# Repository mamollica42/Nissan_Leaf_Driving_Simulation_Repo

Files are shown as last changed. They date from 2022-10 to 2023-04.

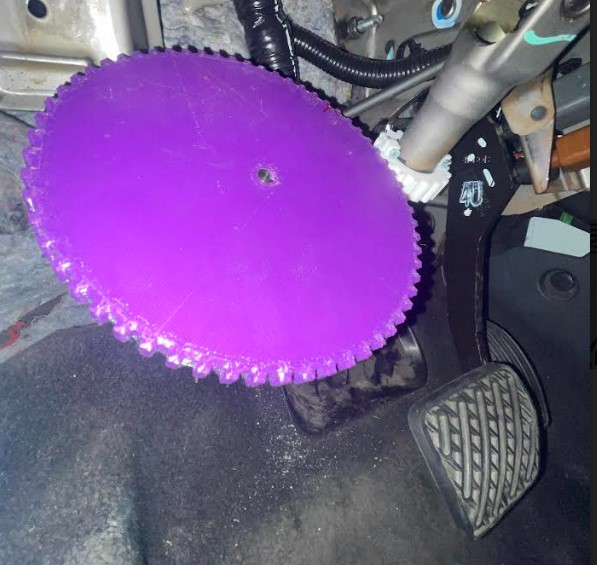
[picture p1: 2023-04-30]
Documentation/Images/Steering.jpg

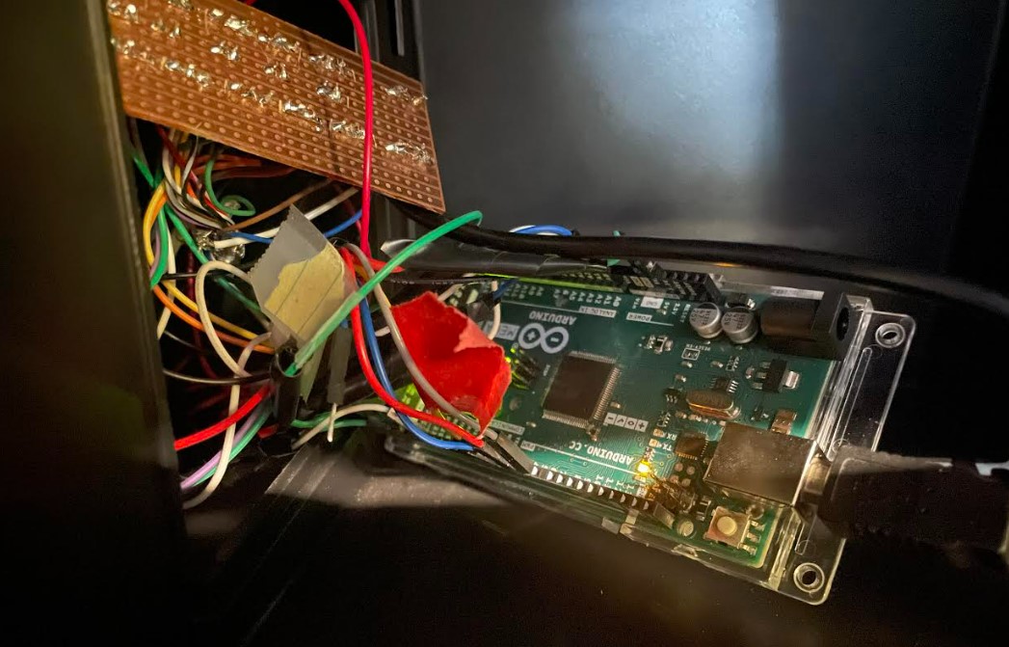
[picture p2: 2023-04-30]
Documentation/Images/MasterMCU.jpg

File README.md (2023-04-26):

# Nissan Leaf Driving Simulation

# Executive Summary

The Nissan Leaf Driving Simulation is a long-term goal for the ECE and ME Departments at TNTECH. This project consists of data acquistion and initial hardware setup for the future simulation to be built off of. The hopes of the final product are to accurately replicate the look and feel of driving a Nissan Leaf without the actual motion of the vehicle.

# Capabilities

This repository currently contains finalized documents for the project. This includes, but is not limited to the following:
- Electrical Schematics
- Final Project Poster
- CAD Models
- Experimental Analysis
-  Subsystem Signoffs
- Finalized Software
- Project Demonstration
- Individual & Final Presentations

# Salient Outcomes
- Measure steering angle from -600 to +600 degrees
  - _Note: After experimentation, the team discovered that the left and right bounds of the steering wheel are NOT equal. That is, the wheel rotates slightly more to the right than it does to the left by approximately 20 degrees._
- Capture break and accelerator percentage of compression
- Detect shifter position and auto-light selection
- Single system power switch with overcurrent protection
- Collect CAN Bus messages >> 10 Hz
- Replaced speedometer with aesthetic 3D printed LCD module
- Use of OEM steering wheel, brake pedal, accelerator pedal, shifter, and auto-light knobs
- All hardware is concealed from the user
- Provide all data to PC in less than 100 milliseconds

# Project Demonstration & Images
Watch our project demonstration [HERE](https://youtu.be/_0IFVq8wqwk)

Power Supply & Control Switch|Steering Gear System|Shifter Subsystem|
:---------------------------:|:------------------:|:------------------:
||

Final Vehicle Interior|
:--------------------:|
|

# About Us

## Team

Michael Mollica - CmpE

Gerardo Mateo - CmpE

Chase Colotta - EE

Brett Harden - EE

Ethan Powers - EE

## Faculty Supervisor

Dr. Nan Chen - ECE Department

Mr. Jesse Roberts -  ECE Department

### Stakeholders

Dr. B. Andy Pardue - ME Department

# Repo Organization
## Reports
- Project Proposal
- Conceptual Design
- Individual Technical Presentations
- Final Presentation
- Final Bill of Materials (BOM)
- Project Poster
- Lessons Learned

## Documentation
- 3D Models
- Electrical Diagrams
- Images
- Signoffs
- Experimentation

## Software
- Documentation -> Software
- Folder includes all Arduino code used to program the MCUs

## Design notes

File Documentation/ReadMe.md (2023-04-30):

## Signoffs

Signoffs are the detailed designs for different components. Signoffs include the analysis for each design specification, images of the schematics for the implementation, and the bill of materials for the components. These documents are the details for each subsystem in the total project. 

## 3D Models

The models posted here are derived from the signoffs. The signoffs include images of the models, but this folder houses the files that contain the designs to be opened in drawing software. Most files were drawn in AutoCAD and uploaded as a .stl file. The 'Final **** Assembly' file in each subfolder is all other pieces in the folder combined into the implemented design. 

## Electrical

### Wiring Schematics

Schematics posted here were drawn in KiCAD from the signoffs, and they represent the wiring for components in the subsystems. Images of the schematics were posted in the signoffs, but this is the downloadable files to view in drawing software. 

## Detailed photos of the project

Pictures taken of the implemented hardware and the software output. The picture labels describe the contents of the respective pictures.

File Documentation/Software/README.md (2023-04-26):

Arduino Software
---------
This folder contains the code for the Master MCU, Shifter, Speedometer, and CAN Bus subsystems. All files are .ino extension.

##### _*Note: CAN Capture Code is example code found at the following link created by the manufacturer of the CAN Bus Shield for Arduino, Seeed Studio. It is not original code and Team 8 takes no credit for its creation._
Link to Code: https://github.com/Seeed-Studio/Seeed_Arduino_CAN
### Capabilities
Each file is the main code that runs its respective subsystem. For example, the Master MCU V2 code runs on the Arduino Mega in the Master MCU subsystem.
### How to Install/Run?
Each .ino file must be downloaded in a folder **with the same name as file**. For example, a file named "myFile.ino" must be placed in a folder named "myFile" so that Arduino IDE can recognize it properly. Once downloaded and in a folder with the same name, simply open the files in Arudino IDE to run and edit.

##### _*Note: This code requires no dependencies to run._

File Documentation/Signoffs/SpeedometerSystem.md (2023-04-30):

SPEEDOMETER SUBSYSTEM
--------------------
### Functions of the Subsystem
The speedometer subsystem must receive output from the driving simulation and display the speed the user is going. A microcontroller will be used to export the speed data from the simulator and display it on a screen inside the car.
### Specifications & Constraints
- C1. Shall be powered by the PC running the simulator via USB 2.0
-	C2. Microcontroller must be able to read speed data from the simulator while it is running using serial communication
-	C3. Data must exit the PC running the simulator and be stored on a microcontroller using serial communication
-	C4. Shall display the speed data in an appropriate manner on a screen inside the car

### Schematic
##### 1. Screen to Microcontroller Connection



_Figure 1. A photograph of the LCD snapping onto the Arduino Uno [1]

##### 2. Wiring Schematic



_Figure 2. Schematic for the 3.5 Inch TFT Color LCD Screen Plugging into the Arduino Uno

### Analysis

### C1. Shall be powered by the PC running the simulator via USB 2.0
An Arduino Uno can be powered by a USB 2.0 coming from the PC running the simulator.

### C2. Microcontroller must be able to read speed data from the simulator while it is running using serial communication
Arduino can directly communicate with the simulator that runs on MATLAB via serial communication with a USB 2.0. For the simulator to send data to the Arduino, serial.write() functions will be inserted into the simulator code to continuously send speed data to the Arduino. For the Arduino to receive and display the speed data, serial.read() functions will be used.

### C3. Data must exit the PC running the simulator and be stored on a microcontroller using serial communication
Once the serial.read() function is used, the speed data will be collected and used in the C code that displays the speed. This means that the data has exited the PC and is being processed on another device using a programming language other than MATLAB.

### C4. Shall display the speed data in an appropriate manner on a screen inside the car
#### LCD Display Selection
The The 3.5 Inch TFT Color LCD Screen has 28 pins and can directly snap onto an Arduino UNO REV3. The 3.5" LCD screen can be programmed to display whatever the user wants and is plenty big enough to display the speed data from the simulation. With a module display area that contains 320x480 pixels, the team can add extra embellishments onto the screen to make the speed data that is displayed feel more appropriate to the car.

#### Mounting
The recommended max distance of a USB 2.0 cable is 16 feet. The PC running the simulator will be within 16 feet of the speedometer and the master MCU, so mounting the LED display in the desired position shall have no effect on transmission speeds. To keep the the immersive feel of the inside of the car, the LCD will be mounted exactly where the current speedometer display is located. The stock display will be removed and be replaced with a new mount that will mimic the current one. The new one will of be able to communicate with MATLAB and pull the speed data from the simulator.



_Figure 3. The mounting for the Uno in the Car 



_Figure 4. The face plate for the mount

The back of the mount will be screwed in to replace the old speedometer display. The face plate will allow for only the LCD screen to be seen by the user of the simulator and will be screwed directly where the old speedometer display was located. All of this should allow for immersive experience for the simulator by not creating an eye sore that sticks out from the rest of the car. The green pieces from the above digrams will be 3D printed in black to blend in with the rest of the components in the car. The pink piece is the Arduino and the yellow piece is the display.

### BOM

| Part | Price |
|:---:|:---:|
| Arduino | $27.60  |
| USB 2.0 | $ 7.60 |
| TFT Color LCD | $ 19.00|
| TOTAL | $54.20 |

### REFERENCES
[1] https://www.amazon.com/Treedix-Display-Screen-Arduino-Mega2560/dp/B0872S57HG

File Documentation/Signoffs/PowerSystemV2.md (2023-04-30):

Power System
-------
### Function of the Subsystem
The power system is to provide power to all of the components and subsystems within the design. This includes the original car components in its entirety as well as the external subsystems that will be added. This will include replacing the battery with a power converter for continuous supply and implementing safety components to protect the sensors and controllers in the external subsystems. . 

### Specs & Constraints
- Must utilize the power supply provided for 12 V supply
- Must regulate the supplied source voltage to be within 5% of 12 V
- Must implement a method to disconnect the entire system from the source
- Shall implement safety components to prevent overcurrent on new devices
- Must not exceed wire capabilities
- Must supply required input voltage to the external sensors, external controllers, and 12 V OEM components

### Schematics
###### Wiring Diagram



_Figure 1: Power Circuit & Connected Components_---

### Analysis
*This analysis is for the original design with 3 Ardiono Unos. The design was modified to only one Uno as shown in the schematic and implemented.*

###### 1. Power Supply
The power supply to be used supplies 12 Volts and 600 Watts of direct current. The voltage output of the power supply was tested with an oscilloscope and the peak-to-peak voltage was approximately 800 mV with a 12 V DC offset. This output means that the voltage supplied is between 11.6 and 12.4 V. The variance of +/- 0.4 V means that the supplied voltage is approximately 3.33% of the expected value. This verifies that the power supply’s original output meets the 5% constraint.  

###### 2. Switch Selection
To prevent the master switch from being a restriction, the switch needs to have a rating of 12 V and 50 A DC. Digi-Key offers a toggle switch from Switch Components that meets the criteria with the TD1-1A-DC-3-R [1]. The switch is rated for 12 V, 50 A DC and has minimum insulation resistance of 100 Mohm. The insulation of the switch will not allow a current from a 12 V supply to reach the user that could be felt by the operator while properly disconnecting the entire system from the source.

###### 3. Diode Selection 
Due to the uncertainty of not knowing the components in the OEM components, an assumption is made that energy storage elements are implemented somewhere. The switch system needs to be designed to allow for the load to always have a path for current to flow and dissipate the stored energy. A flyback diode is introduced to be in parallel with the load and allow energy to circulate through the load until it dissipates completely after the switch is opened.
The diode for the circuit shown in Figure 1 will be a 19TQ015CJ from SMC Diode Solutions [2]. It is designed to have a continuous forward voltage of 360 mV at a maximum continuous current of 19 A. The datasheet provides that the diode can handle a peak current of 120 A for an instance before dissipating, which is three times greater than the maximum current that can be supplied.

###### 4. Wiring
The wiring to all of the external components will be 18-gauge wire. This is based around the pre-terminated wire that is sold to be used for the Arduino’s DC jack [3]. The maximum current that is allowed for 18-gauge wire is 2.3 Amps [4]. The current drawn by each external microcontroller or sensor is expected to have a maximum of 70 mA per their respective datasheet. This 70 mA current is within the 2.3 A limit of the 18-gauge wire. The internal resistance of 18-gauge wire is approximately 6.385 Ohms per 1000 ft. For the 6 ft of wire, the resistance is 0.03831 Ohms. This means that the maximum voltage across the wire is 0.08811 V or 88.11 mV.  

###### 5. Voltages and Fuses
Per the datasheet for the Arduino Uno, the microcontroller draws no more than 70 mA and can receive voltages ranging from 6 to 20 volts on the DC jack [5]. The microcontrollers will then be connected directly to the 12 V system due to 12 +/- 0.4 V falling within the range. The rotary encoder used for the steering system states that it can draw up to 70 mA per the data sheet at a range of 10.6 to 24 V. Likewise, the voltage will be within the requirements with the 12 V supply.
A fuse panel will be implemented to protect the wiring from short circuits. The fuses for each system will be 100 mA glass fuses from Digi-Key [6]. These fuses will be used in series as the first point of failure instead of the wire. It is common practice for mechanics and electricians to install wiring for devices that would be around 60-85% of the maximum current rating for the expected load. The 100 mA fuse was chosen to allow for approximately 70% of the maximum tolerance to allow for the event of a device drawing slightly more current than expected. 
To protect the wiring between the power supply and the switch, the internal fuse for the power supply will be the protection. This is designed within the supply and eliminates any issues seen by the terminals.


_Figure 2: Spice Circuit with 70 mA loads_

A Spice simulation was used to determine the expected values of the currents and voltages on each line. The circuit in Figure 2 shows the expected connections for the Unos and encoder with each of the wire resistances placed in series. Two simulations were run with the input voltage V1 being 11.6 V and 12.4 V to cover the maximum variance of the supplied voltages to the wires. The data yields the conclusion that the voltages at the end of the wires will be within the acceptable values for the input of the Unos and Encoder. 

Input: 11.6 V 

| Element | Voltage (V) | Current (mA) |
|---:|:---:|:---|
| Uno1 | 11.5973 | 70 |
| Uno2 | 11.5973 | 70 |
| Uno3 | 11.5973 | 70 |
| Encoder | 11.5973 | 70 |

Input: 12.4 V 

| Element | Voltage (V) | Current (mA) |
|---:|:---:|:---|
| Uno1 | 12.3973 | 70 |
| Uno2 | 12.3973 | 70 |
| Uno3 | 12.3973 | 70 |
| Encoder | 12.3973 | 70 |

###### 6. OEM Connection
The OEM battery terminals will be connected to bolts that will act as posts to the switch. The OEM safety devices will be utilized since they were designed for the OEM components. 

###### 7. Housing
The components to the power system will be placed inside of a plastic electrical box. The wires will be ran into it and will provide insulation and support to all of the safety compontents. A plastic box was chosen over metal due to the insulation characteristics of plastic.

### BOM

|Item | Part Number |Price |
|---:|:---:|:---|
| Master Switch | TD1-1A-DC-3-R |$5.08 |
| Flyback Diode | 19TQ015CJ |$1.30 |
| Arduino Wiring | 10-02493 |$30.04  |
| 100 mA Fuses | 5ST 100-R |$3.78 |
| Fuse Holder | 4628 |$2.92 |
| TOTAL | |$43.12  |

### References
[1] https://www.digikey.com/en/products/detail/switch-components/TD1-1A-DC-3-R/11492919

[2] https://www.digikey.com/en/products/detail/smc-diode-solutions/19TQ015CJ/6022095

[3] https://www.digikey.com/en/products/detail/tensility-international-corp/10-02493/9134524

[4] https://docs.arduino.cc/resources/datasheets/A000066-datasheet.pdf

[5] https://docs.arduino.cc/static/6c94080aaecc364dd9013ce042a27790/A000066-datasheet.pdf

[6] https://www.digikey.com/en/products/detail/bel-fuse-inc/5ST-100-R/1009010

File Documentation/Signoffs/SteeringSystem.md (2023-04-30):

STEERING WHEEL SUBSYSTEM
------------------------
### Function of the Subsystem
The Steering Wheel subsytem shall recieve the input of the Nissan Leaf steering wheel into a sensor
embedded into the steering column of the vehicle. The sensor will measure the steering angle and send
the data into a local microcontroller which will interpret the data and relay it to the simulation.

### Specifications & Constraints
- Must measure angle of rotation of the steering wheel
- Must use the Nissan Leaf OEM steering wheel as the input
- Angle shall be no less than 1200 degrees from the left boundary to the right boundary (3 and 1/3 rotations)
- Error of the angle must be within 1 degree of the true steering angle
- Must not lose steering position when power is cycled
- System must be small enough to fit in the area of the vehicle without interfering with the driver or other subsytems

The simulation requires an input for the steering angle of the vehicle. In the Nissan Leaf, the steering
is limited to 3 and 1/3 total rotations from the clockwise boundary to the counter-clockwise boundary.
Therefore, the angle measured must be at least 1200 degrees total. Due to the broader impact 
accuracy constraint, the error of the angle sensed must be within 1 degree of the true angle to prevent false
representation of the steering. Based on a study conducted on front wheel drive vehicles, the range of error in steering angles
is between -0.56 and 1.64 degrees for a total error range of 2.2 degrees [1]. Therefore, the 1 degree target error is within the
normal range of a standard front wheel drive vehicle such as the Nissan Leaf.

### Schematic
##### 1. Model



LEGEND:
- Black  --> OEM Parts (Steering Column and Mounting Plate)
- Blue   --> Small Gear
- Green  --> Large Gear
- Red    --> Adapter Plate
- Yellow --> JT-035D (Mounting Bracket)
- Orange --> Absolute Encoder

_Figure 1: 3D-Model of Gear and Encoder Connection_



_Figure 2: 2D Model of the Adapter Plate to be 3D printed_



_Figure 3: 2D Model of the Mounting Plate in the Nissan Leaf_



_Figure 4: Highlighted the Mounting Plate from Figure 3 in the Nissan Leaf_

##### 2. Wiring Schematic



_Figure 5: Encoder Connection to MCU_

### Analysis
##### 1. Angular Rotation

To select the appropriate rotary encoder, the CPR value must be enough to measure each steering position accurately. The equation below is used to capture the angle in degrees based on the CPR and the counts:
      
      A = (C/CPR) * 360       (1)

where C is the number of counts, CPR is the Counts per Revolution, and A is the angle in degrees.

Similarly, the accuracy of the angle is highly important to the selection of an encoder. To find the output sensitivy of the encoder, the following equation is used:
     
     D = 360/(Resolution)       (2)

where D is the degrees of accuracy and Resolution is the how many data bits. 

##### 2. Encoder Selection

This steering wheel design will use a TRD-NA1024NW absolute rotary encoder with a resolution of 1024. The unique property of the absolute encoder is that the output will remain constant even if the encoder is not powered which allows the system to not lose the steering position when power is cycled. The Encoder a voltage rating of 12 to 24 VDC, and a maximum current consumption of 70 mA. The TRD-NA1024NW has 10 data bits, a VDD pin, and a GND pin. This requires a microcontroller with at least 10 digital GPIO pins and that can receive current of up to 32 mA from the rotary encoder.

The encoder has 1024 unique 10-bit outputs than will be read into the MCU. The outputs of each pin are 10 V signals which are too high for the MCU to read becuase the Arduino digital input pins operate at 5 V. To overcome this issue, a simple two resistor voltage divider will be connected to each output of the encoder. To solve for the resitance needed, the below equation is used:

      Vin = Vout*(R2/R1 + R2)   (3)
      
In this case, Vin is 10 V and Vout must be 5 V. Therefore, selecting R1 such that it equals R2 will give a Vout of 5 V because 10 V / 2 = 5 V. For the purposes of this project, R1 and R2 will be 2 W, 100k Ohm resistors to ensure the current of 32 mA will not damage the resistors in the voltage divider circuit. This can be proved by the equation below:

      P = IV                    (4)
      
where P is power dissipated in the resistor, I is current through the resistor, and V is the voltage across the resistor. The resistors are each rated for 2 W of power. If each resistor is placed in the circuit and are equivalent, the current though each resistor will be equal. Additionally, the voltage across each resistor will be 5 V based on Ohm's Law where V = IR. Therefore, the power consumed in each resistor is (5 V)(32 mA / 2) = 0.16 W which is much less than the maximum rating of 2 W.

The output of the encoder changes on rotation of the knob. The knob of the encoder will be connected to a gear system that is mounted to the steering column of the vehicle so that the steering wheel rotation will rotate the knob. Each 10-bit output will increment or decrement a count variable in the MCU code depending on the direction of rotation. That count will be used to calculate the angle of the wheel using equation 1 above.

Our contraint of 1% accuracy means that the encoder must have a resolution high enough to measure values within 1 degree of the true angle. With a 1024 resolution, we are able to cut down the accuracy to 0.9375 degrees, which is highly accurate. This resolution is the lowest possible that allows the team to measure less than a degree of change in the steering angle.

##### 3. Microcontroller Selection

The Arduino UNO REV3 is clocked at 16 MHz, has 14 digital I/O pins, and 6 analog I/O pins. The board can be powered via battery, USB, or the VDD pin and can operate within a voltage range of 7-12 V. Each GPIO pin can receive up to 40 mA and operates at 5 V. The maximum current consumption Given that the encoder requires 10 digital pins, the Arduino UNO can support that requirement and still have leftover pins for communication. Addtionally, the power supplied to the encoder will be supplied by the power system to avoid any possible damage to the microcontroller.

##### 4. Connectivity

The rotary encoder must be connected to the steering column such that the rotation of the wheel can be properly mapped to the encoder. This will be done using a gear system with an 10:3 gear ratio. This value is based on the 1200 degree rotation of the Nissan Steering Wheel having to be mapped to the 360 degree rotation of the encoder. The below equation helps analytically verify this calculation:

      Driven/Driving = 1200/360 = 10/3 ==> 10:3    (5)
      
The steering wheel is already limited to the 1200 degree range by Nissan. This means that the steering wheel physically is unable to exceed 960 degrees of rotation from the left boundary to the right boundary. Therefore, mapping its rotation using the 10:3 gear ratio will also make it physically impossible for the rotation of the encoder to exceed 360 degrees as desired. The TRD-NA1024NW is a 1024 resolution encoder, meaning it displays 1024 unique outputs per revolution. For each turn of the encoder, 0.356 degrees will be measured allowing the angle to be extremely precise. Additionally, by attaching the gear system to the steering column, the OEM steering wheel can be used as the input to the encoder.  

##### 5. Calculations
To find the diameters of the gears that will be used to create the 8:3 gear ratio, we will follow the Law of Gearing:
      
      D2/D1 = T2/T1                             (6)
      
where D1 and D2 are the diameters of the gears, and T1 and T2 are the number of teeth for each gear. To acheive an 8:3 ratio, the driving gear will have 18 teeth and the driven gear will have 48 teeth. This translates to 6 cm and 16 cm respectively for D1 and D2 to maintain the 8:3 ratio while meeting the spacing constraint of the vehicle.

To verify that this ratio would provide accurate mapping of 960 to 360 degrees, we created a MATLAB script to iterate through all possible positions of the encoder as seen in the figure below.



_Figure 6: MATLAB Verfication for all possible Angles_

##### 6. Gear and Mounting Design
The size constraints for the next closest item in the car are as follows:
- Closest point to the left of the mounting plate: 12 cm
- Closest point behind the mounting plate: 6 cm
- Closest point below the mointing plate (barrier determined to be for operator's feet): 10 cm
- Closest point to the right of the steering column: 7 cm
- Closest point to above the steering column: 9 cm

The steering column has an inch diameter, so the small gear must have a center bore of exactly 1 inch (2.54 cm). To maintain a small size, the small gear was chosen to have a 6 cm pitch diameter to fit around the steering column and comply with size restrictions around the column. When chosing 6 cm for the small gear, 16 cm must be the pitch diameter of the large gear based on the Law of Gearing. The center bore of the large gear must fit the knob of the encoder such that the rotation of the gear is the same rotation for the encoder. In this case, the center bore of the large gear must be 8 mm in diameter and a 0.5 mm notch to secure the knob of the encoder. 

The mounting bracket of the encoder will be connect to the frame of the Leaf via an adapter plate. The gear connected to the encoder needs to be on the same plane as the gear from the steering column to allow the gears to mesh properly. This was done by creating the adapter plate to allow the mounting bracket to be rotated 45 degrees from the frame and be parallel to the steering column. Then the depth of the adapter was determined to be 12.7063 mm based off of the space needed to have the gears far enough to mesh, but also have the gears as close as possible to reduce the backlash between the teeth. These gears will be 3D printed in the Maker's Space in the Angelo & Jennette Volpe Library.

The furthest point that the design extends to the right is the small gear on the steering column, and its farthest point protrudes 2.03 cm from edge of the steering column. The furthest point to the left is the large gear and it should extend 10.38 cm past the edge of the mounting plate. The model should not extend below the mounting plate by any more than 1 cm. The back of the mounting plate is the furthest back that the design goes and should not conflict with the wall. The furthest up the design goes is the 10.45 cm due to the large gear and the closest point is above the steering column. Since the large gear is offset, the closet point to it is 17 cm above the mounting plate. With the specifications of the design, none of the boundaries on the car are exceeded and the size constraints are met.

### BOM

| Part | Price |
|:---:|:---:|
| TRD-NA1024NWD| $352.00  |
| JT-035D | $13.00 | (Mounting Bracket)
| Arduino | $27.60 |
| Resistors | $7.60 |
| TOTAL | $400.20  |

_*Note: The filament and the printer will be provided by the university because this is a school project_

### REFERENCES
[1] https://www.researchgate.net/publication/327832862_Analytical_Evaluation_of_Steering_Errors_in_a_Front_Wheel_Steered_Vehicle

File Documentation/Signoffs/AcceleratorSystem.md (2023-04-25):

Accelerator Pedal Position System
--------------------------------------
### Function of the Subsystem
This subsystem will obtain the gas pedals position and send this signal to a local microcontroller for processing. The local microcontroller will then send its position to the master microcontroller which tells the simulation the pedals position. 

### Specifications & Constraints
- C1. Must use OEM gas pedal to meet customer expectations.
- C2. Must send voltage at the range 0-5V that changes as the position changes to be read by the local microcontroller.
- C3. Must have wires able to handle at least 5V and 20mA due to the expected voltage range 0-5V and expected current of 20mA.
- C4. Shall have an accurate measure of the pedal postion of at least 1% accuracy to ensure the simulation is a accurate representation of real life. 
- C5. Must not have any exposed or loose wire according to IEEE Std 576-13.  

### Wiring Schematic

Gas and Brake kicad schematic

###### _Figure 1: OEM Wiring With Splice On Output Signals of Gas and Brake pedals_

### Analysis
#### C1. Must use OEM gas pedal to meet customer expectations.
- Customer does not want external pedal installed to car.
#### C2. Must send voltage at the range 0-5V that changes as the position changes to be read by the local microcontroller.
- The sensor that measures the position will be an analog signal with voltage range 0-5V that can be read by most microcontrollers. In this case a external sensor will not be added since there is a accelerator pedal position sensor(APPS) that sends an analog signal to the engine controller module(ECM) that will be wire spliced to the local microcontroller.
#### C3. Must have wires able to handle at least 5V and 20mA due to the expected voltage range 0-5V and expected current of 20mA.
- 22 AWG wire will be selected for the splicing since it can handle 300V and 7A.
#### C4. Shall have an accurate measure of the pedal postion of at least 1% accuracy to ensure the simulation is a accurate representation of real life.
- Arduino boards convert the 0-5V analog signal to a digital signal with 1024 bits so 5/1024 means 4.88mV per step.  The smallest range of voltage we tested was 1.883V which has 1.883V/0.00488V to get 376.6 steps for this range of voltage. The accuracy then is 1/376.6 = 0.27%.
#### C5. Must not have any exposed or loose wire according to IEEE Std 576-13. 
- This section of the IEEE standards tell you the safe practices of wire splicing which I will follow when install the Dorman wire splicing clips.



###### _Figure 2: The wiring diagram of the cruise control with the pedal position sensors at the bottom left[1]_



###### _Figure 3: The expected values of each wire for the accelerator[2]_

### Testing 
The accelerator pedal has been tested by the Mechanical Engineering (ME) capstone team that has also been tasked to get data from the gas pedal to use in the simulation. They took out the pedal and took it to their lab and power the sensors with a power supply and measured the sensors output with a digital multimeter (DMM). Their results are shown in Figure 4. As shown in the picture there are two 5V supplied the pedal from the ECU to pins 3 and 2 and shown in the picture with red and wired in the car with white. The two grounds are shown shown in the picture as pins 5 and 6 with black and wired in the car with black. The two outputs from the senors are on pins 1 and 4 and are shown in the picture as green but are wired in the car with red. The correct pins and wire colors are also shown in Figure 2. The voltage range they got on the sensor at pin 1 is 0.367V - 2.250V from zero throttle to full throttle respectively. The voltage range from the sensor on pin 4 is 0.745V - 4.455V. With these ranges we will be able to set up a linear angle increase as the voltages increase in the coding of the local microcontroller. 

ME gas pedal testing

###### _Figure 4: The data the ME team gathered from testing the accelerator pedal while hooked up to a DMM.

### BOM

| Part | Price |
|:---:|:---:|
| Dorman 22-18 splicers 7 pact | $4.49 |
| 22 gauge wire | $14.99 |

note: tax not included

Sources:
[1] https://portal-diagnostov.com/en/2020/04/20/cruise-control-nissan-leaf-sv-2013-system-wiring-diagrams/

[2] https://erwinsalarda.com/nissan-accelerator-pedal-position-app-sensor/

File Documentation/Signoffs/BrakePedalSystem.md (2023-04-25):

Brake Pedal Position System
--------------------------------------
### Function of the Subsystem
This system will obtain the brake pedal posistion and send this signal to a local microcontroller to process its position. The local microcintroller will then send the pedal location to the master microcontroller to implement it to the simulation.  

### Specifications & Constraints
- C1. Must use OEM brake pedal to meet customer expectations.
- C2. Must send voltage in the range of 0-5V that changes with pedal position to be read by a local microcontroller.
- C3. Must have wires able to handle 5V and 20mA to meet the expected voltage range of 0-5V and the expected current of 20mA. 
- C4. Shall have an accurate measure of the brake pedal position of at least 1% accuracy to ensure the simulation is an accurate representation of real life.
- C5. Must comply to IEEE 576-13 section on loose wires and splicing of wires.
- C6. Must have microcontroller with at least four analog or four digital in ports to read both the gas pedal sensors and the brake pedal sensors.
- C7. Must have microcontroller able to be powered by a 12V source to comply with the power systems design to stay at 12V.
- C8. Must have microcontroller with UART capability to communicate with the master MCU. 
- C9. Must have microcontroller able to convert analog to digital in at least 100ms to be consider real time. (Shown in master MCU signoff)

### Wiring Schematic

Gas and Brake kicad schematic

_Figure 1: The wiring schematic with the desired local MCU and OEM sensors for both pedals being sent to it. 

### Analysis
#### C1. Must use OEM brake pedal to meet customer expectations.
- Customer does not want external brake pedal installed so must use stock pedal.
#### C2. Must send voltage in the range of 0-5V that changes with pedal position to be read by a local microcontroller.
- I am going to use the cars anti-brake system(ABS) deceleration sensor[1] which sends an analog voltage of 0-5V to the ECM. I will wire splice sensor output wires and feed them to local microcontroller analog input pins. 
#### C3. Must have wires able to handle 5V and 20mA to meet the expected voltage range of 0-5V and the expected current of 20mA.
- I am choosing 22 AWG wire since it is rated for 300V and 7A.
#### C4. Shall have an accurate measure of the brake pedal position of at least 1% accuracy to ensure the simulation is an accurate representation of real life.
- Arduino boards convert the analog siganl to digital signal with 4.88mV per step. The smallest signal voltage range was 3.35-3.98V. (3.98-3.35)V/4.88mV = 129 steps and has 1/129 = 0.78% accuracy.
#### C5. Must comply to IEEE 576-13 section on loose wires and splicing of wires.
- This section of standard deals with wire splicing practices and regulation which will be followed when installing the Dorman wire splicing clip that meets regulation. 
#### C6. Must have microcontroller with at least four analog or four digital in ports to read both the gas pedal sensors and the brake pedal sensors.
- I will be using an Arduino Uno Rev3 that has 6 analog pins.
#### C7. Must have microcontroller able to be powered by a 12V source to comply with the power systems design to stay at 12V.
- I chose the Uno over the nano since the uno can be powered by 12V power supply will the nano cannot.
#### C8. Must have microcontroller with UART capability to communicate with the master MCU. 
- The Uno has UART which is haow it will communicate with the Arduino Mega.
#### C9. Must have microcontroller able to convert analog to digital in at least 100ms to be consider real time. (Shown in master MCU signoff)
- The Uno has processing speed of 16MHz which is 62.5ns for one cycle, it takes 13 cycles to convert A to D which takes 0.8125 microseconds which is greater then 100ms.

### Testing 
Brett and I took out the entire brake pedal with the ABS sensor attached and took it to the capstone lab for testing. I turned on the car with the part removed and measured the 4 pin plug and found Vin and GND. Vin is the white wire on pin 3 and GND is the black wire on pin 4. With these pins determined I hooked up those pins to a powersupply and measured the outputs of pin 1 and 2 with a digital multimeter(DMM). I learned that pin 2 has a voltage of 3.35V when not pressed and a voltage of 3.98V while fully pressed. The voltage does change linearly as the brake is pushed. I also learned that pin 1 has a voltage of 2.77V not pressed and 1.58V fully pressed. This voltage also changes linearly as the brake is pushed. With this data I will be able to program the arduino board to get a position based on the change of voltages while the pedal is being pressed. 

### BOM

| Part | Price |
|:---:|:---:|
| Arduino Uno Rev 3 | $24.00 |

Sources:
[1] https://www.scribd.com/presentation/344855740/Sensors-Used-in-ABS#

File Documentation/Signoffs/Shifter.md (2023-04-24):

Gear Shifter Subsystem
--------------------------------------
### Function of the Subsystem
The gear shifter subsystem will capture the OEM signal from the gear shifter sensor by splicing into the wiring and storing the signal on a local microcontroller. 
### Specifications & Constraints
-	C1. Must use OEM gear shifter sensor
-	C2. OEM shifter sensor must send a detectable output signal for the shifter positions park, neutral, drive, and reverse.
-	C3. Shall receive the OEM gear shifter signal on a local microcontroller
-	C4. Must have local microcontroller that can be powered by a 12 V source
-	C5. Must have local microcontroller that can communicate with the master MCU via UART communication
-	C6. Must have local microcontroller that samples above or at twice the the measured normal frequency of 4.82 Hz from OEM gear shifter sensor to satisfy the Nyquist rate
-	C7. Must have local microcontroller capable of reading the measured 5 V digital output signal from the OEM shifter sensor
-	C8. Must have local microcontroller with at least 4 digital I/O pins to read the output signals coming from the OEM shifter signal
-	C9. Must have wires capable of handling 5 V to read the output signal from the OEM shifter sensor
-	C10. Must comply with IEEE 576-13 section on splicing wires and having loose wires.

### Wiring Schematic



###### _Figure 1: Splicing OEM wiring to a local microcontroller

### Testing 
For wire splicing to be effective, the signals coming from the wires of the gear shifter sensor would still need to be accurate even with the back half of the car being cut off.  As of now, the car can only go into park and neutral. To see if the car can go into drive and reverse, the OEM shifter sensor was tested was to see if the sensor still could send the appropriate output signal even if the car could not go into the desired gear. For testing, male to female jumper wires, an oscilloscope, and a DMM was used. The DMM was used to the voltage changes coming from the sensor and the oscilloscope was used to find the normal frequency of the voltage changes. The voltages measured on the DMM were 0 or 5 V.



###### _Figure 2: Measuring the voltage of the output signals coming from the gear shifter sensor

## Analysis

### Nyquist
For the signal to be read properly by the local microcontroller, the Nyquist rate of the OEM shifter sensor needs to be determined to eliminate aliasing in reading the signal. This was done by using an oscilloscope to detect the fastest fall and rise of the signal created by the user coming from the OEM sensor. After measuring this, it was concluded that the normal frequency is 4.82 Hz. This value was found by using the oscilloscope's measurement tools. The Nyquist rate is double the normal frequency. This makes the Nyquist rate of the OEM shifter sensor 9.64 Hz. This means that the local microcontroller must have a sampling rate of 9.64 Hz or greater to have accurate readings.



###### _Figure 3: Measuring the falling edge of the OEM shifter signal going from 5 V to 0 V



###### _Figure 4: The measured values from the oscilloscope

### C1. Must use OEM gear shifter sensor
The output from the OEM shifter sensor is being captured so the sensor is being used.

### C2. OEM shifter sensor must send a detectable output signal for the shifter positions drive, park, reverse, and neutral
After measuring the voltages and changing the gears in the car, it was determined that system is an active low system. This was done by using a DMM to measure the output signals coming from the OEM gear shifter sensor. The red lead was connected to a pin and the black lead was connected to ground. Whenever the gear in the car was changed, the wire corresponding to the gear when from 5 V down to 0 V until you let go of the shifter position. Then it returned back to 5 V. This allowed for the conclusion of the signal being a digital signal [1]. Out of the 12 pins coming from the sensor, it was determined that pins 2, 3, 9, and 11 were able to represent park, neutral, drive, and reverse.

### C3. Shall receive the OEM gear shifter signal on a local microcontroller
The wires carrying the signal are being wire spliced to a microcontroller.

### C4. Must have local microcontroller that can be powered by a 12 V source
The Arduino Uno can be powered by a 12 V source unlike the Arduino Nano.

### C5. Must have local microcontroller that can communicate with the master MCU via UART communication
The master MCU is an Arduino Mega, so the Arduino Uno can communicate with it via UART communication.

### C6. Must have local microcontroller that samples above or at twice the the measured normal frequency of 4.82 Hz from OEM gear shifter sensor to satisfy the Nyquist rate
The sampling rate of a digital I/O pin from the Arduino Uno is 8 MHz, so the constraint of sampling at or above double the normal frequency of the OEM shifter sensor is met. A Nyquist rate of 9.64 Hz is easily met.

### C7. Must have local microcontroller capable of reading the measured 5 V digital output signal from the OEM shifter sensor
A digital port on the Arduino Uno can read up to a 5.5 V digital signal. Since the measured signal was 0 or 5 V, it was determined to be a digital signal [1].



###### _Figure 5: Spice Diagram of Protection Circuit

Since the the max input voltage into a digital I/O port is 5.5 V, four 100 Ω resistors and four zener diodes with a breakdown voltage of 5.1 V will be used to protect the the microcontroller in case of a voltage spike. Once the breakdown voltage of the zener diode is reached, it will short circuit to neutral until the voltage is below the threshold of 5.1 V. This means that a voltage greater than 5.5 V cannot reach the microcontroller.



###### _Figure 6: Output Voltage of Circuit with an Input Voltage of 15 V

### C8. Must have local microcontroller with at least 4 digital I/O pins to read the output signals coming from the OEM shifter signal
The Arduino Uno has 14 digital I/O pins.

### C9. Must have wires capable of handling 5 V to read the output signal from the OEM shifter sensor
Since the wires will be only handling 5 V, any sized wire could be used to carry the gear shifter's signal to the local microcontroller. 22 gauge wire will be used to splice into the OEM wires. 22 gauge wire is capable of handling 7 A, so it is more than capable of handling a digital voltage signal [2].

### C10. Must comply with IEEE 576-13 section on splicing wires and having loose wires.
This section of standards deal with the regulations and protocols around wire splicing that will be met when installing the Dorman wire splicing clip that meets regulations.

### BOM

| Part | Price |
|:---:|:---:|
| Dorman 22-18 Splicers 7 Pact | $4.49 |
| 22 Gauge Wire | $14.99 |
| Arduino Uno | $25.00 |
|Diodes | $3.00 |
| 100 Ω Resistors | $1.00 |
| Total | $48.48 |

### REFERENCES
[1] https://www.allaboutcircuits.com/textbook/direct-current/chpt-9/current-signal-systems/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,12%20milliamps%20representing%2050%20percent%2C%20and%20so%20on.

[2] https://www.rvandplaya.com/what-is-22-gauge-wire-used-for/

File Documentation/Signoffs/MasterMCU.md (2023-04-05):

MASTER MICROCONTROLLER
------------------------
### Function of the Subsystem
The master microcontroller (MMCU) must receive data from four seperate local microcontrollers that interface with the
sensors in other subsystems. This MMCU will read serial data from each local MCU and then send that data to the PC to
be processed in the simulation. This system in necessary to relieve the PC that is running the graphical simulation from
having to also read four different data streams from the local microcontrollers. The SpeedGoat system is connected to the
PC so it can handle the physics engine because the PC can not handle running the graphics and physics simultaneously. So, 
without the MMCU to handle the addtional data processing to the PC could overload the system and greatly impact the performance 
of the simulation.

### Specifications & Constraints
- Must connect to no less than one local microcontroller
- Must provide real-time data transfer of under 100 milliseconds
- Shall connect to the PC running the simulation
- Shall have 1 Tx and 1 Rx pin for communication protocols
- Shall be powered by the PC

The definition of real-time is subjective and therefore can not be directly defined. In the case of this system, real-time was
based on the average human reaction time of 250 milliseconds [1]. Given that delay being considerably high for a real-time system, 
the team has decided to cut that number to over 1/2 of its value and target less than 100 milliseconds. This target is based on the 
acceptable latency for gaming which lies between 20 and 100 milliseconds [2].

### Wiring Schematic



###### _Figure 1: UART Connection_

### Analysis
##### 1. Microcontroller Selection
The MCU will be the Arduino Mega 2560 that includes a 16 MHz clock frequency, 54 digtial I/O pins, 4 UARTs, and can be powered via USB. This MCU supports serial communication with up to 4 other local microcontrollers via UART which meets the constraint above. Additionally, the board can be programmed using the Arduino IDE which includes multiple libraries and functions to help manage multiple communications via UART simultaneously without interfering with the data transmitted or received.

Some useful Arduino functions include : 
- Serial.available() : Checks to see if the UART has data waiting to be read
- Serial.read() : Reads the data into the serial buffer
- Serial.write(x) : Sends the data 'x' to through the Tx line

By using these functions, we can use the following code that is from the Official Arduino Forum to connect to four other devices [3]:



###### _Figure 2: Multiple Serial Communications on Arduino Mega 2560

By configuring each of the four serial ports and checking their availability before reading or writing data, no packets should be lost or corrupted during transmission. Addtionally, the four different ports will be read in an infinite loop one after the other in a round robin fashsion such that no process is left unserviced.

##### 2. Communication Protocols
The MMCU will use the following forms of communication with the local microcontrollers and the PC: UART and USB. UART is the most basic form of serial communication offered on the Arduino architecture. UART only requires 2 lines for communication: transmit and receive (Tx, Rx). To send and receive the data properly, UART uses special formatting to denote the start of the data packet and the stop as seen in the figure below.



###### _Figure 2: UART Packet Structure_

UART stands for Universal Asynchronous Receiver-Transmitter. The UART packet begins with a start bit which denotes the beginning of a data message. Following the start bit is the data being sent to the receiver from the transmitter followed by the parity bit. The parity bit is used for error checking and can be either even or odd. Finally, the stop bit denotes the end of the data packet and allows the receiver to correctly parse the data message. This protocol is simple and the baud rate is configurable so that data can be transmitted and received at a desired speed. For the purposes of this project, the baud rate will be configured to the highest supported rate of 115200 for the fastest data transmission time possible as to meet the real-time constraint of 100 milliseconds. The baud rate of 115200 translates to 14400 bytes per second which is equivalent of sending a data packet of 8 bits every 79 microseconds.

USB stands for Universial Serial Bus and is the most commonly used communication protocol today. USB is standard on nearly every computer device and allows the connected hardware to communicate serially while also providing power. The Arduino Mega 2560 supports USB and will be connected to the PC via USB 2.0. This port will be able to read all of the data sent from the microcontroller network up to 480 Mbps while also powering the MMCU.

##### 3. Calculations
Each serial port will be configured to 115200 baud rate which sends a data packet every 79 microseconds. Because there are four serial ports, it will take four times the 79 microseconds at the very least if other code is disregarded. This will be called as T_ideal
  
    T_ideal = (4) * (79 us) = 316 us = 0.316 ms
    
The time complexity of the if-statements are O(1) which correlates to the time of a single atomic instruction. The time of one atomic instruction in the case of the Arduino Mega with a 16 MHz processor is as follows:

    T_atomic = 1 / (16e6) = 62.5 ns = 0.0000625 ms
    
Given the main code has four if-statements and will also require the four serial transmissions, the total time can be calculated:

    T = T_ideal + (4) * T_atomic = 0.31625 ms << 100 ms for real-time constraint
    
Based on the calculations above, the Arduino Mega can read each of the Arduino UNOs data lines in only 0.316 milliseconds. This allows much more code and data processing to occur within the Mega and still maintain a transmission time of under 100 milliseconds.

### BOM

| Part | Price |
|:---:|:---:|
| Arduino | $36.30 |
| USB 2.0 | $ 7.60 |
| TOTAL | $43.90 |

### REFERENCES

[1] https://reactiontest.org/#:~:text=The%20average%20human%20response%20time%20is%20about%200.25,traffic%20and%20had%20to%20slam%20on%20their%20brakes.

[2] https://www.bandwidthplace.com/the-importance-of-latency-in-online-gaming/

[3] https://forum.arduino.cc/t/mega-2560-multiple-serial-connections/100542/2

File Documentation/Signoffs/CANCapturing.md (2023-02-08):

CAN Bus Capturing
---------------------------
### Function of the Subsystem
This subsystem must capture the data on the CAN (Controller Area Network) bus 
and store it. This system is not responsible for interpreting the information
that is captured.

### Specifications & Constraints
- Must capture information from CAN bus at no less than 10 Hz
- Must store CAN bus data neatly and in a readable manner on the PC
- Shall not interfere with the functionality with any other subsystem
- Shall receive power from the PC
- Must be able to store up to 2048 different CAN Messages
- PC must have at least 28 Kb of storage space for CAN data

### Wiring Schematic



###### _Figure 1: Arduino Leonardo CAN BUS Board Connection to OBD II Port via DB9 connector_

### Analysis
##### 1. Microcontroller Selection

The board contains the MCP2515 CAN transceiver to read the CAN bus at a rate of up to 1 Mbps and is connected through a DB9 to OBDII cable to the Nissan Leaf. The MCP2515 utilizes its three receive buffers to capture messages from the CAN bus [1]. The most important of these buffers is the Message Assembly Buffer (MAB) which assembles the messages from the CAN bus and always receives the next message [1]. These messages are then transferred into the RXB0 or RXB1 buffers to be read by the MCU once complete [1]. The MAB buffer ensures the messages are valid before sending them to the other two receive buffers so that the data is correctly interpreted [1]. The MCP2515 is built into the Arduino Leonardo CAN BUS Board and communicates via SPI (Serial Periphial Interface) to the on-board MCU. The Arduino will then be powered by and communicating with the PC via USB (Universal Serial Bus).

Arudino IDE can include the MCP2515 CAN-BUS Library in order to write the proper code to capture the data being read
from the CAN bus. Additionally, the library includes functions to help parse the data into sections of the entire CAN 
message to help the readability of the data.

##### 2. Verfication

The Nissan Leaf CAN Bus uses 11-bit identifier which allows for up to 2048 different messages (2^11 = 2048, which means CAN messages must have IDs that range from 0-2047). Each CAN frame can be up to 108 bits long due to acknowledgements, Cyclic Redundancy Check (CRC), Data bits, Start of Frame bit(s) (SOF), End of Frame bit(s), Control bits, and Remote Transmission Request bits (RTR). Therefore, the PC must be able to store at least 2048 * 108 bits = 221,184 bits = 27,648 bytes = 27.648 Kb to capture at least one of each type of CAN message.

The target is to read the CAN messages at no less than 10 Hz which translates to a message every 0.1 s. The CAN transceiver
on the arduino is able to read up to 1 Mbps which is 1 million bits per second. Each message of the Nissan Leaf is 108-bits
which means the subsystem can read the CAN messages at a rate of up to nearly 9259 messages per second, which is well above the 
10 Hz minimum [2].

###### 2.1 Data Storage
Data capture and storage can be done by using the MCP_CAN library in the Arduino IDE along with an application called [_CoolTerm_](https://freeware.the-meiers.org/). The MCP_CAN library includes the readMsgBuf() function which will read the CAN data from the receive buffer of the MCP2515 CAN transceiver and can then be printed to the terminal using the Serial.println() function so that each message and its corresponding ID will be displayed on a different line [3]. However, to store the data in a non-volatile file type such as CSV (Comma Seperated Values) format, [_CoolTerm_](https://freeware.the-meiers.org/) will be used to intercept the data on the serial port that the Arduino is connected to and will be able to save the data in CSV format which can be opened in Excel [4].



###### _Figure 2: CAN Message Format_

###### 2.2 Connectivity




###### _Figure 3: OBDII Pin Diagram w/ Table [5]_

As seen in the figure above, the OBDII port pins 6 & 14 are connected to the CAN High and CAN Low signals of the Car-CAN as stated in the Nissan Leaf OBDII manual [6]. The output pins of the OBDII port will be connected to a OBDII to DB9 cable.



###### _Figure 4: Pin Diagram for OBDII to DB9 cable [5]_

The diagram above shows that the CANH & CANL signals from pins 6 & 14 from the OBDII port are connected to pins 7 & 2 of the DB9 port through the cable [7]. The female end of the DB9 connector is soldered to the Arduino and the pins 7 & 2 are directly connected to the CANH & CANL input signals of the MCP2515 CAN transceiver.



###### _Figure 5: Arduino Leonardo CAN Bus Board PCB Underside_

###### 2.3 System Interference

The CAN capturing subsystem connects to the OBDII port of the Nissan Leaf and the PC via USB to power the arduino and receive serial data. The OBDII port is not being used by any other subsystem of the design, so there will be no interference from that connection. The PC will be running the simulation and powering the Master Microcontroller subsystem. However, the Arduino for the CAN Capturing subsystem will be connected to a different USB port on the PC and will not have interaction with the simulation in any manner. So, this subsystem will cause no destructive interference to the other subsystems in the overall design.

### BOM
| Part | Price |
|:---:|:---:|
| Arduino | $21.72 |
| DB9 Cable | $10.64 |
| TOTAL | $32.36 |

### References

[1] https://ww1.microchip.com/downloads/aemDocuments/documents/APID/ProductDocuments/DataSheets/MCP2515-Family-Data-Sheet-DS20001801K.pdf

[2] https://www.mynissanleaf.com/viewtopic.php?t=4131#:~:text=The%20messages%20on%20the%20LEAF%20EV%20CAN%20bus,the%20Identifiers%20could%20range%20from%200%20to%200x7FF.

[3] https://reference.arduino.cc/reference/en/libraries/mcp_can/

[4] https://freeware.the-meiers.org/

[5] https://leaf-obd.readthedocs.io/en/latest/tutorial/elm327.html

[6] https://leaf-obd.readthedocs.io/en/latest/diagnostic-connector.html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

[7] https://components101.com/sites/default/files/component_datasheet/OBD2%20Adapter%20Cable%20Datasheet.pdf

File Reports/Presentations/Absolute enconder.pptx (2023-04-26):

## Absolute encoder

By Gerardo Mateo

## table contents

- Definition of Rotary Encoder
- History of encoder
- Introduction the type of rotary
- Advantage and Disadvantage of increment and absolute rotary encoder
- Incremental vs absolute
- How does absolute rotary encoder work
- Absolute encoder feature
- TRD-NA1024NWD
- Grey code
- Absolute Encoder output
- Summary

## Definition of rotary Encoder

- The rotary encoder is an electro-mechanical device that converts angular motions or positions into analog or digital signals.

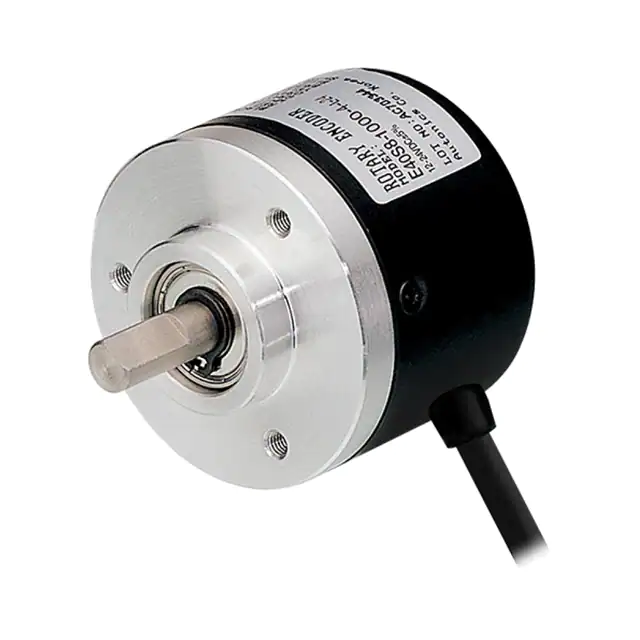
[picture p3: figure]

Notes: This definition of the Rotary encoder is to give you guy a general idea. But eventually, I will take about the absolute encoder.

## History of encoder

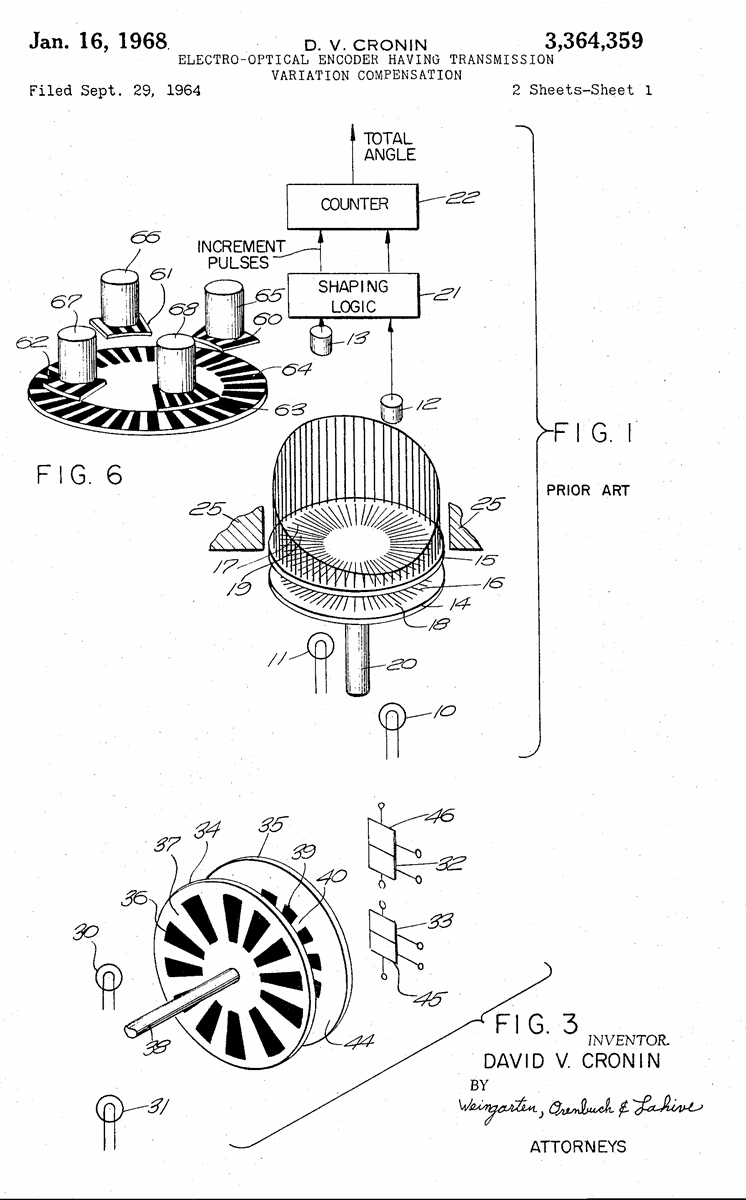
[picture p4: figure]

- In 1964, David Cronin, create the first optical encoder
- In 1955, Baldwin was first who first experimental optical encoder
- In 1962, Baldwin research resulted into creating the first optical encoder with 18-bit resolution used in space.

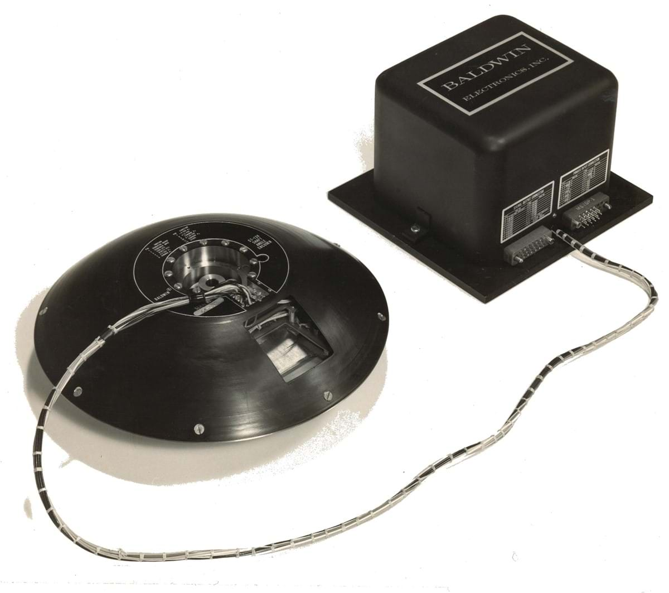
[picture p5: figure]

## Introduction the type of rotary

- Incremental Rotary Encoder
- Absolute Rotary Encoder

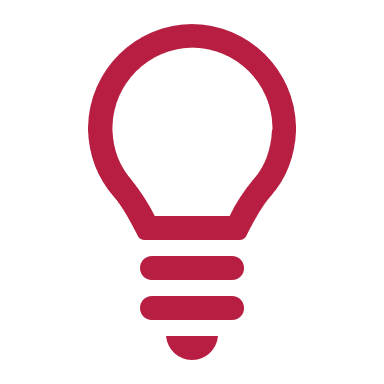
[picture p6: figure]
Lightbulb icon
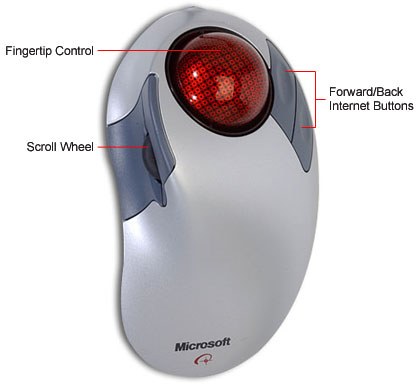
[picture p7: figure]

This Photo (http://superuser.com/questions/303661/remedy-for-a-no-scroll-wheel-trackball) by Unknown Author is licensed under CC BY-SA (https://creativecommons.org/licenses/by-sa/3.0/)

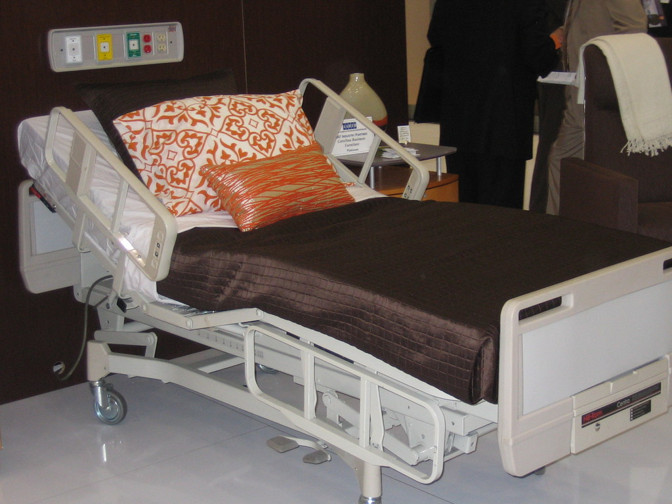
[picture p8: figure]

This Photo (https://www.flickr.com/photos/bfionline/1618597680/) by Unknown Author is licensed under CC BY-SA (https://creativecommons.org/licenses/by-sa/3.0/)

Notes: Most automation companies, industrial companies, warehouse distributors, and daily life equipment use a rotary encoder. The most common rotary encoder is the increment rotary, and it usually uses to monitor speed, measure position, or measure distance. An example of a company and daily life equipment would be an old trackball mouse. Inside the old trackball mouse has an incremental encoder to check its position by counting the positional changes. Furthermore, another example would be inside of assembly line or package line would be checking the speed of a component or the distance. However, an incremental encoder is not the only type of rotary encoder. The other type of rotary encoder is an absolute rotary encoder. An absolute encoder checks the Angular position, velocity, and distance. An example that uses an absolute encoder would be a hospital bed to determine the height. The incremental and absolute rotary encoder has advantages and disadvantages, depending on the situation.

## Advantage and disadvantage of increment encoder

- Incremental encoder
  - Advantage
    - Cost less
    - Less complex
    - Easy to design
  - Disadvantage
    - Volatile
    - Disk have same mark
    - Need Reference point
    - Can be unsafe
    - Imprecise sometime

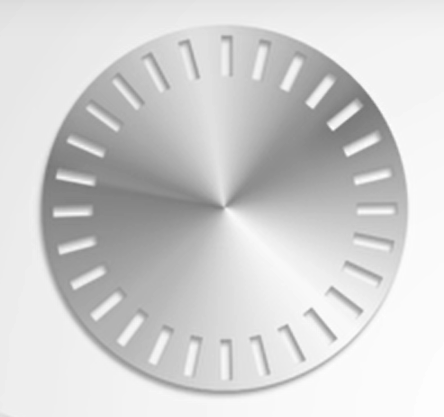
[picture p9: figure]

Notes: The Advantage and disadvantages of both rotary encoders will tell you why I chose the absolute encoder for my team. First, let's talk about the increment rotary encoder benefit. The benefits are that the increment encoder will get information immediately, is less complex, and is easier to buy. However, the increment has some drawbacks. One of the drawbacks of this device is that increment is volatile, which means if the encoder loses power, the position or value it holds will be lost. Also, one of the benefits is a drawback to the device because if it's less complex, it means that the disk inside of the encoder has the same mark. If the disk has the same marking, then there is a chance that the encoder will read an overlapping code. Furthermore, another drawback is that the increment encoder will need a reference point to help to recalibrate or somewhere to call home. Overall, each of the advantages and disadvantages of the incremental encoder will give a general idea of when to use the component.

## Advantage and disadvantage of Absolute encoder

Absolute encoder
Advantage
nonvolatile
No need of a fixed reference point
Higher resolution
Disk has unique mark for each position
Safe
precise
Disadvantage
High price
Complex to design
Hard to design

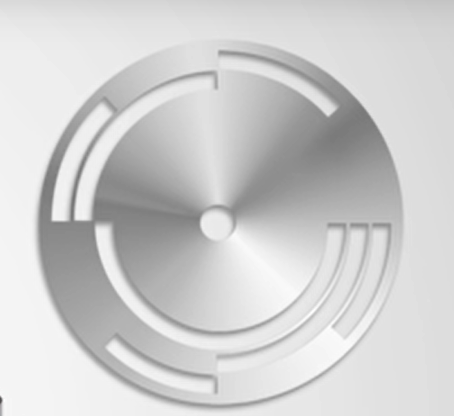
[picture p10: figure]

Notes: Now let's talk about the absolute encoder. The benefit of the absolute encoder is that it's nonvolatile, which means the position or value will not be lost when power is lost. Also, an awesome benefit is that it does not need a fixed reference point because it is nonvolatile. Since absolute encoders are more complex, each position of the disk will have a unique mark, and each mark will help to improve the resolution. However, the disadvantages will be that it's an expensive product and hard to design due to the unique markings for each position for a particular resolution. Overall, each of the advantages of the absolute encoder overcomes the disadvantage of the incremental encoder, which means the absolute encoder is better than incremental.

## Incremental Vs. Absolute Encoders

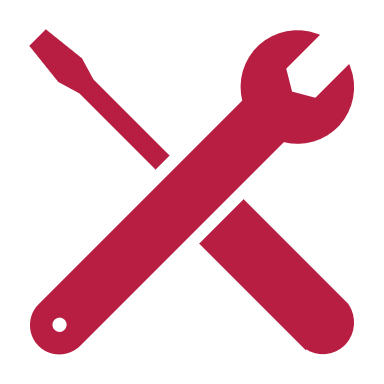
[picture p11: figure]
Tools icon

- Incremental Encoder
  - Volatile
  - The output Square wave with two signal
  - Measure Relative movement
    - Distance
    - Speed
    - position
  - Can be imprecise

Absolute encoder
reliably
nonvolatile
Precise
The output unique bits for each position
Angular position, velocity, and distance

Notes: Since I already talk about the advantage and disadvantages of both rotary encoders. Some detail about increment is that the output is a square wave produced by two signals. However, you can use one or two signal waves to help with a task that needs them. Also, incremental encoders measure specific movements and send information immediately when power is on. Additionally, the incremental encoder can miss reading the disk, leading to imprecision. The absolution encoder, however, overcomes all the problems associated with incremental encoders. Also, the absolution encoder has an output with a unique bit for each position, and it can remember the value when the power is off. Considering that the encoder is precise by a unique bit, it would be safe to say that it would help to prevent any danger. Overall, if a person needs a precise position when the power goes out, then an absolute encoder will help fix the problem. Also, this applies to the incremental encoder, but the absolute encoder has a special benefit.

## How does absolute rotary encoder work

- The component
  - Light emission diode
  - Shaft
  - Rotor plate
  - Fixed slit
  - Photo Transistor

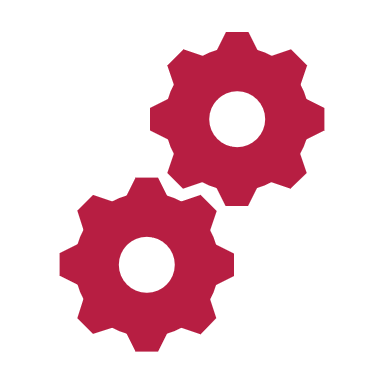
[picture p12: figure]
Gears icon
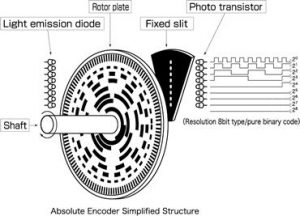
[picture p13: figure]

< Feng, Niu. “Asbolute Encoder Simplified Structure.” Https://Www.omch.co/Absolute-Rotary-Encoder/, 10 Oct. 2021. Accessed 4 Apr. 2023.
!

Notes: I will now explain how an absolute rotary encoder works and what components it contains. The part that the absolute encoder has is the LED, shaft, Rotor plate, fixed slit, and phototransistor. Each of the components will play a part produces the output.Let's begin by rotating the shaft. When the shaft rotates, the disk will rotate along with it. Also, each LED will emit at the Rotor plate. As you can see in the picture, the rotor plate has a tiny marking, and those marking has a unique code. During rotation, the LED will pass through the mark on the disk. After passing the mark, the LED will pass the fixed slit, which allows it to emit effectively to the phototransistor. Furthermore, the transistor will detect if the LED is on or off and produce an output of 0 and 1. Overall, the picture will show what is inside the absolute and give an idea of how each component works.

## Absolute encoder feature

- Single turn

- multi-turn

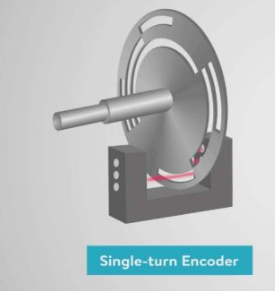
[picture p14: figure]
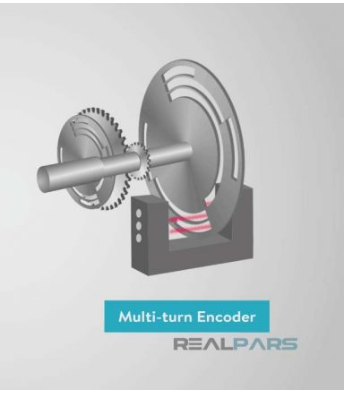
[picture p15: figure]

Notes: The absolute rotary encoder has features such as single and multi-turn. A single turn measures the position in a single rotation, and a multi-turn measures the position beyond a single rotation. Also, the multi-turn can keep track of the rotation. Both single and multi-turn have a usage in different situations. An example of single-turn encoder use in real life would be an automatic door that does not need to measure more than one rotation because the door usually opens around 180 degrees or 90 degrees. The real-life application of multi-turn would be robotic manipulators, which go beyond 360 degrees and need to track rotation.The only problem with both features would be the cost. An absolute single-turn encoder will cost more than an incremental encoder, and an absolute multi-turn encoder will cost more than both a single-turn encoder and an incremental encoder. Our group used an Absolute single turn encoder because it is reliable and costs less than a muti-turn. talk about the group when researching

## TRD-NA1024NWD

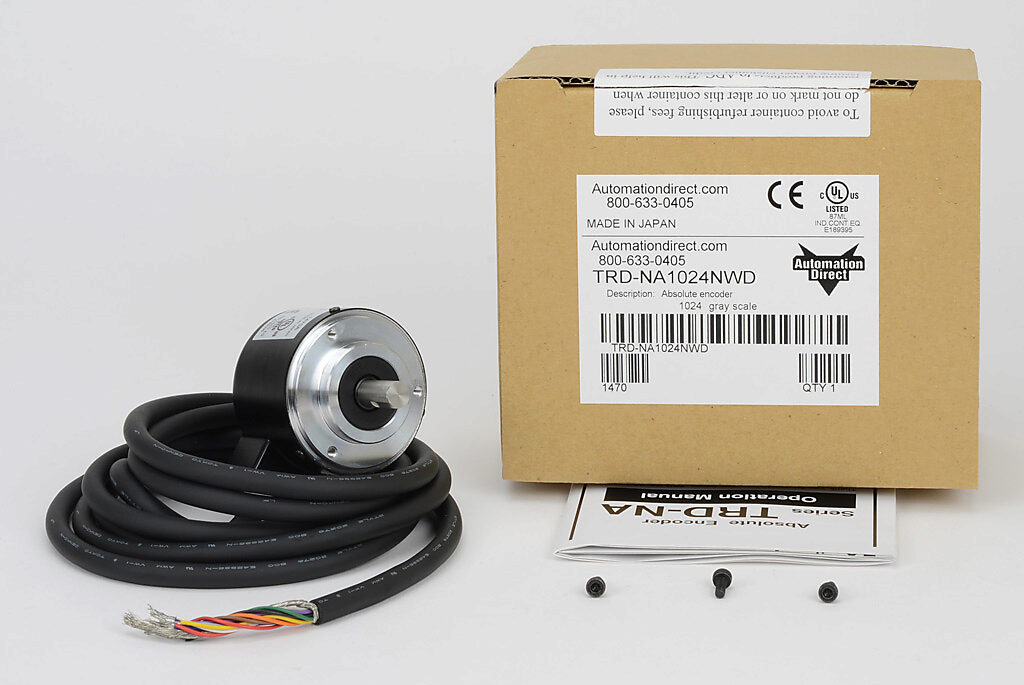
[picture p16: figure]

- Medium duty
- Single turn
- Output: Gray code (10 bit)
- 2^10 =1024 unique position

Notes: The absolute rotary encoder that the team chose was TRD-NA1024NWD. Also, there were three reasons behind this: reliability, remembering its old value when the power went out, and good resolution. Furthermore, The reliable part is that the encoder is medium-duty, which means it can last a couple of years. In addition, the absolute encoder is a single turn, and the output is gray code. However, the resolution is 10-bit and has 1024 unique positions. The resolution will help us to get better accuracy on our steering wheel. Overall, the encoder met our condition for a capstone project, and the team installed it in the vehicle and got the information. But the downside of our encoder was that need a pull resistor to get our output and very good ground. In the next slide, we will talk about grey code.

## Grey code

- Know as reflected binary
- Frank Gray
- Minimum error code

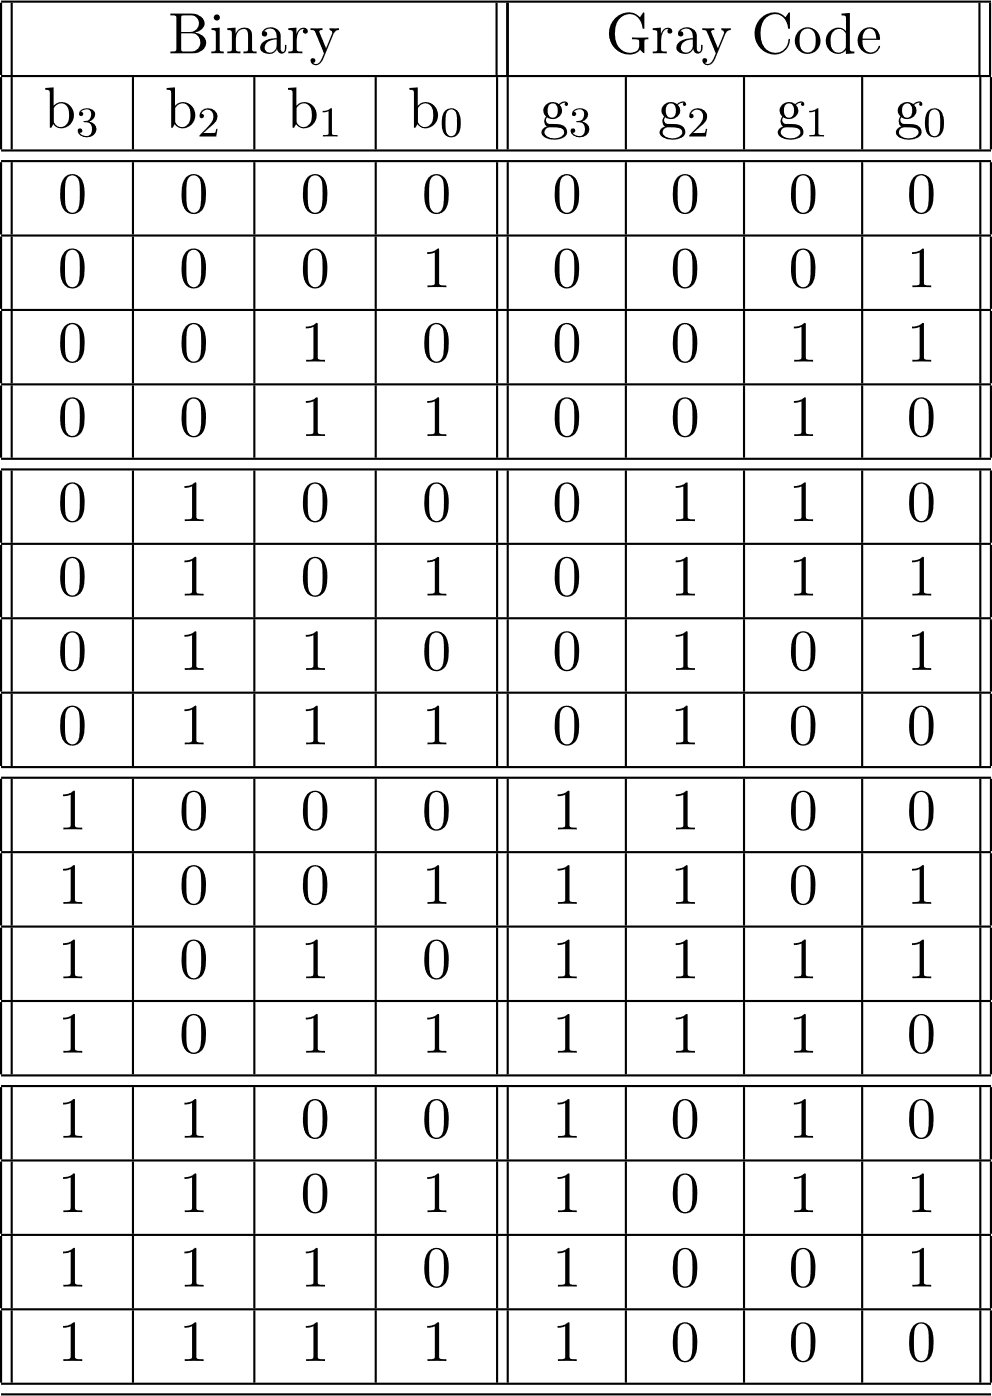
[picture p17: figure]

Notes: Frank Gray created grey code, and the binary are be to be converted to gray code. Grey code is important to the absolute encoder because it helps to minimize error and become more accurate. By minimizing error, we mean reducing the switch binary. If it was binary, then there is a possible chance of an overlap bit. However, grey code gives a big advantage to the absolute encoder and gives a precise position. Also, the grey code creates a unique position on the rotor plate. In general, gray code can be useful for equipment that deals with precision or absolute encoding.





need for extra time
To convert binary to Grey code
get MSB
add the MSB to the next bit and ignore the carry
Repeat the process

## Absolute Encoder output

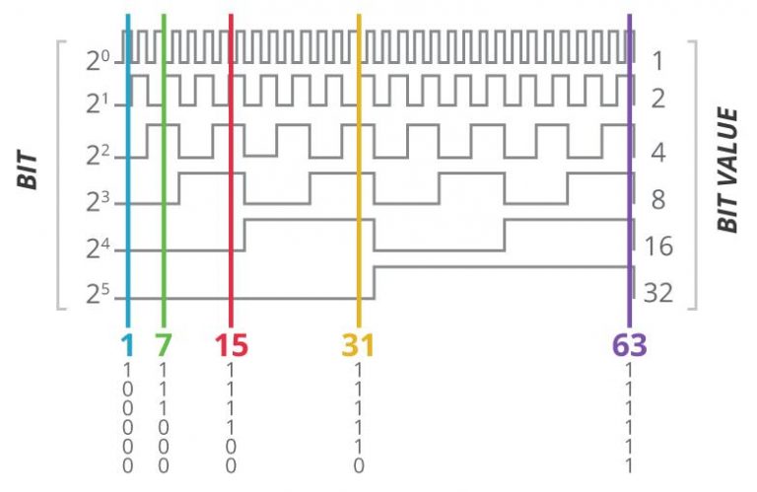
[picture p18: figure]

- Three type of output
  - Parallel
  - Serial
  - Analog

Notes: Absolute encoders have three types of outputs: parallel, serial, and analog. Furthermore, the most common output would be the parallel, and parallel depends on the number of wires for each bit. As shown in the picture, each bit represents a wire, and each bit helps to represent its unique position. Also, our absolute encoder is parallel and has 10 bits. The absolute encoder with serial output is usually used in microcontrollers since serial output has a clock. Further, the absolute encoder output sends one bit for each clock pulse. The analog output will depend on the position of the absolute encoder and send out a voltage signal or current signal. Overall, each of the outputs I mentioned will help you in finding the correct absolute encoder that you need. Parallel is not be the only option.

## Summary

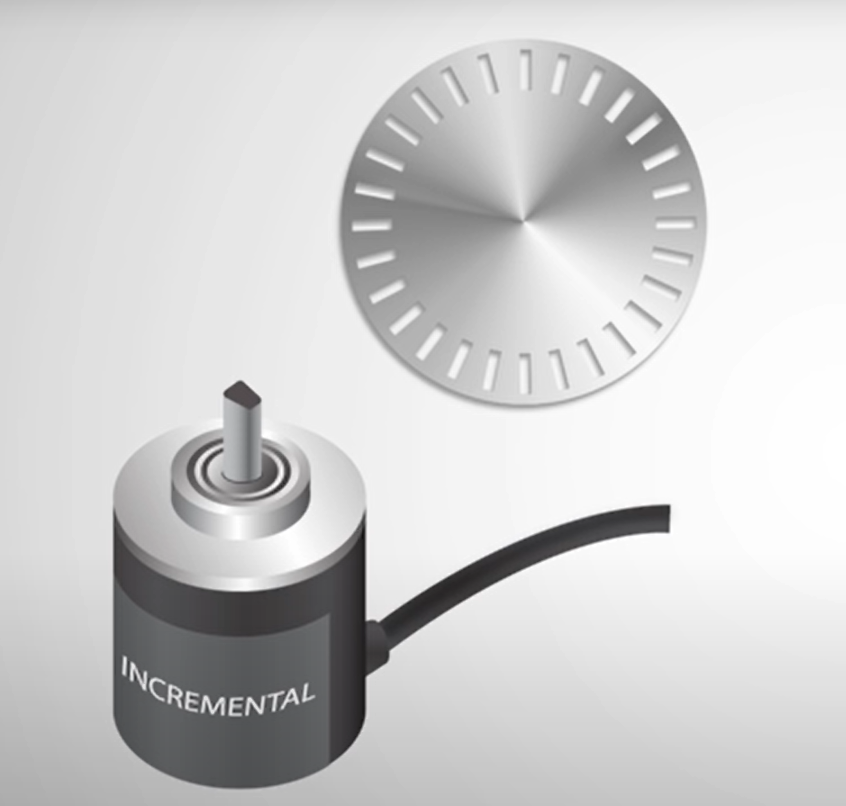
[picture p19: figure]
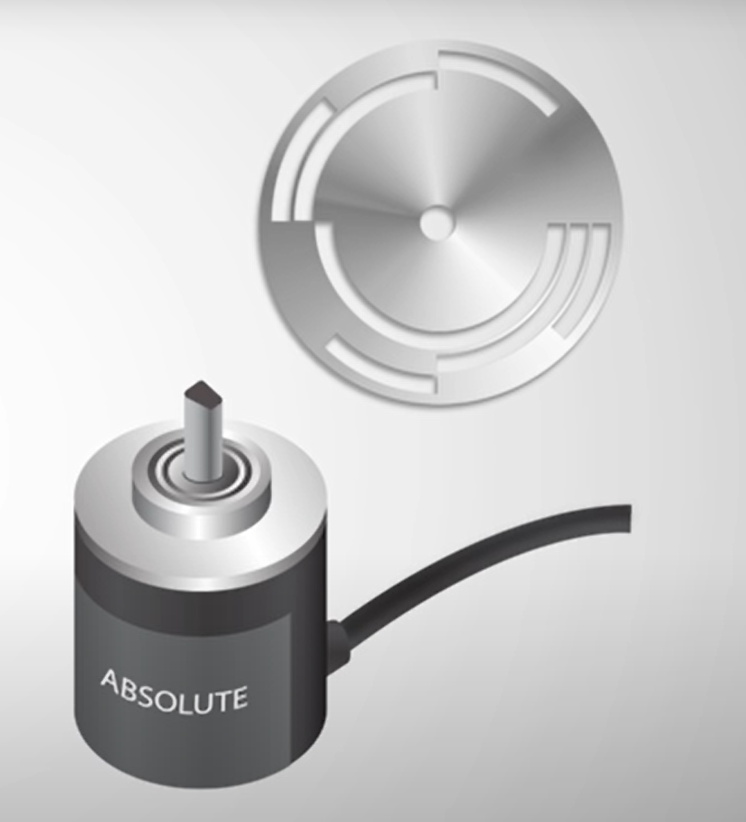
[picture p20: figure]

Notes: Overall, incremental encoders have the advantage of constantly running machines that require little precision. In other words, the incremental encoder measures position, speed, and distance when power is on. Also, this is useful for applications that require constant monitoring of the object's movement but do not require high levels of precision. On the other hand, the absolute encoder can handle things that increments can't do. As a result, absolute encoders are more precise and safer. Also, absolute encoders are more capable to measure even the smallest movements. The absolute encoder can show the exact position of a shaft within a single revolution. Furthermore, the absolute encoder provides a backup feature that the incremental encoder does not have. If the power is cut off, the absolute encoder can still remember the position of the shaft, and the machine will not move unexpectedly.

## Work cited

- https://www.omch.co/absolute-rotary-encoder/
- https://www.geeksforgeeks.org/code-converters-binary-to-from-gray-code/
- https://www.usdigital.com/blog/the-strange-history-of-encoders/#:~:text=In%201955%20Baldwin%20made%20their,optical%20encoder%20used%20in%20space.
- https://www.digikey.com/en/products/detail/industrialemart/E40S6-360-3-N-24/15285029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
- https://realpars.com/absolute-vs-incremental-encoder/

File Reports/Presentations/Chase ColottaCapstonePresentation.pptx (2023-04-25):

## Technical Presentation: Hall-Effect Sensor

Chase Colotta
ECE-4971

## What is a Hall-effect sensor?

- It’s a type of sensor that detects the presence and magnitude of a magnetic field using the hall effect.
- They are used for measuring positioning, speed detecting, and current sensing.
- It’s mainly used for timing the speed of wheels and shafts like a tachometer and anti-brake locking.

## History of the Hall Effect

- The theory of electromagnetism was published by James Clerk Maxwell in 1861
- This theory was tested for the following years especially the interaction of magnets and current
- In 1879, Edwin Hall discovered the hall effect eighteen years before the discovery of the electron
- His findings are published with the name “On a New Action of the Magnet on Electric Currents"

## What is the Hall effect?

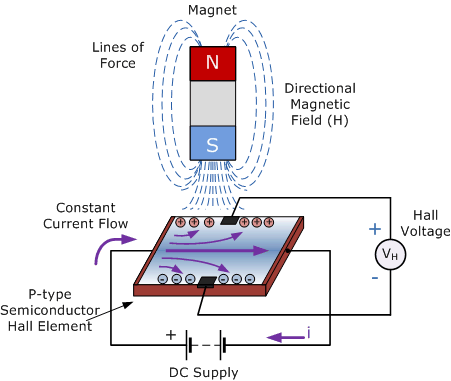
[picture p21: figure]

V_H =(IB_(⊥))/(ρ_n qt)

R_H =(V_H t)/(IB_(⊥))=1/(ρ_n q)

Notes:
Discover by Edwin Hall 1879
The Hall effect is the potential difference created in an electrical conductor when a magnetic field is introduced perpendicular to the current.
Higher magnetic field more electrons deflected making a higher voltage potential

The force that causes the electrons to shift is called Lorentz force

VH is the Hall voltage across the conductive plate,
I is the current passing through the plate,
q is the magnitude of the charge of the charge carriers,
ρn is the number of charge carriers per unit volume, and
t is the thickness of the plate.
Rh is hall effect coefficient

## Lorentz Force

F=q(E+v×B)

- F is the force acting on a particle
- q is the electrical charge
- v is the instantaneous velocity of the particle due to E and B
- E is the external electrical field
- B is the external magnetic field

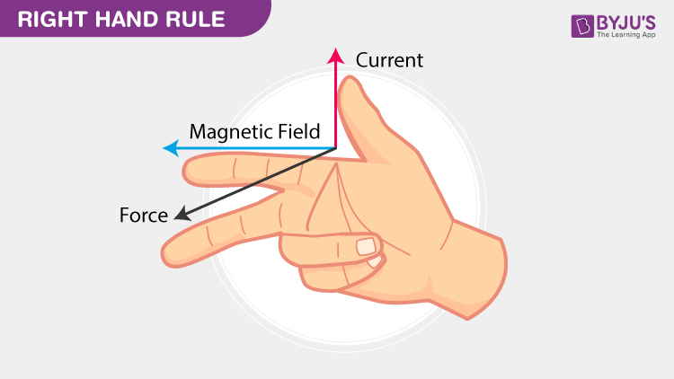
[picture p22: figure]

## How does this work?

- As Current flows a magnetic field is created
- When the amps increase so does the magnetic force. Giving it a higher flux density.

φ_B =BAcos(θ)

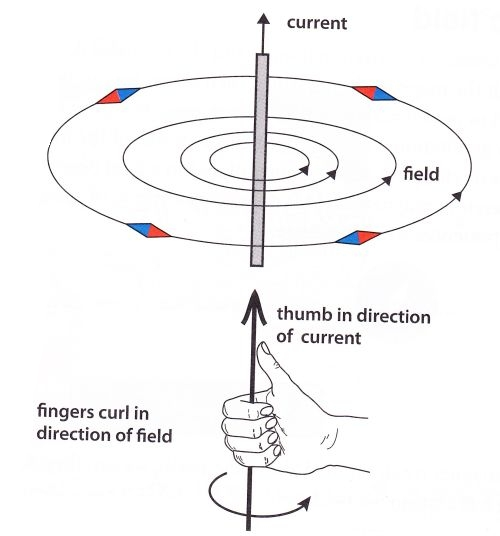
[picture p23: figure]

B=(μI)/(2πr)

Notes: Mu is the magnetic permeability
I is current
R is distance from wire
A is cross sectional area of wire
Theta angle normal to magnetic field angle

## Electromagnets

- When current flows in a coil it creates an electromagnet
- These electromagnets can interact with permit magnetics for various effects

φ_B =nBAcos(θ)

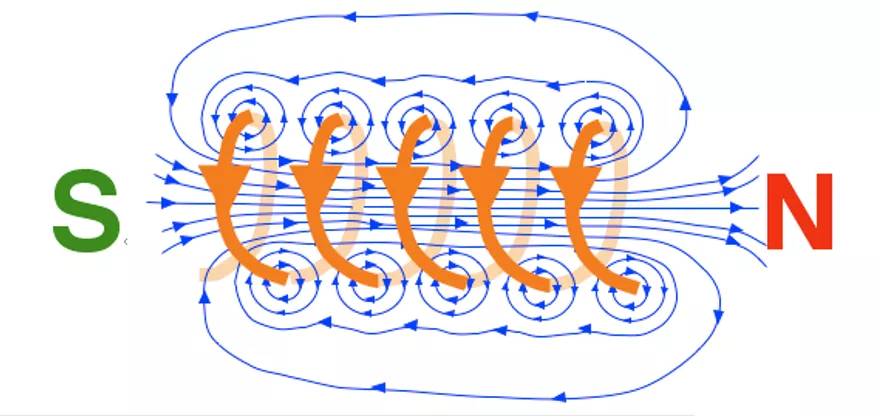
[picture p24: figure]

## Examples of electromagnetic uses

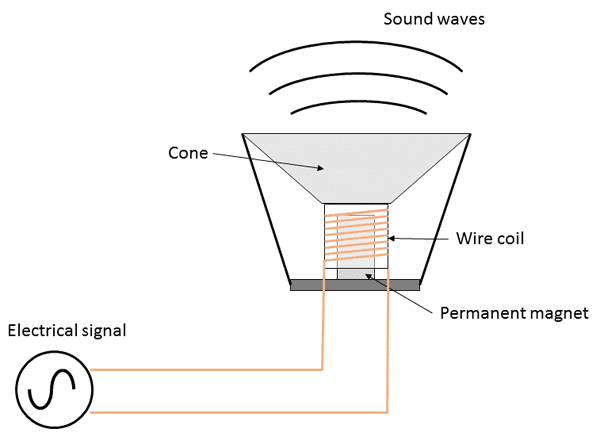
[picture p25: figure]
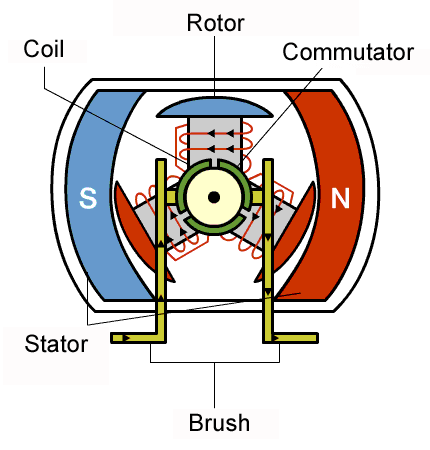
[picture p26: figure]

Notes: Brushed dc motor

The speaker works by oscillating with current changes

## Examples of Hall Effect Senors

Icon

## Linear Hall Sensors vs. Digital Hall Sensors

Linear
- Outputs a continuous analog signal that changes with magnetic field strength.
- Accurate position sensed with voltage changes.

Digital
- Has a “Schmitt Trigger” circuit which changes output based on thresholds.
- ‘On’ and ‘Off’ uses no oscillation

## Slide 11

Linear Hall Sensor Circuit


Digital Hall Sensor Circuit


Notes: Amplifiers to increase intensity of output signals

Schmitt trigger (op-amp) which gives it the on or off nature
Open collector NPN transitor there to switch to ground when magnetic flux density is higher then the on point.

## Unipolar Sensor and Bipolar Sensor

Unipolar
- Only needs a single south pole to activate and release them
- Used as momentary switches

Bipolar
- Requires a south pole to activate the sensor and a north pole to release them
- Used as latch switches with the output

## Hall Effect Sensors

- Pros

- Immune to dust, dirt, mud, and water
- Is a non-contact sensor so no wear down
- Needs no additional shunt resistances in the circuit

- Cons

- Magnetic flux from surroundings such as wires affects the measured value

## Sources

- https://en.wikipedia.org/wiki/Lorentz_force
- https://en.wikipedia.org/wiki/Hall_effect
- https://en.wikipedia.org/wiki/Hall_effect_sensor
- https://www.icrfq.net/hall-effect-sensors/
- https://www.renesas.com/us/en/support/engineer-school/brushless-dc-motor-01-overview
- https://www.electronics-tutorials.ws/electromagnetism/hall-effect.html

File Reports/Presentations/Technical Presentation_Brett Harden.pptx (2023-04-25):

## Gear Train


By: Brett Harden

## Contents

- Definition & Purpose
- Theory
- Relevance/Design

## What is a gear train?

Definition:
Mechanical device where two or more gears are made to mesh with each other to transmit power from one shaft to another.
Purposes
Mechanical Advantage
Mechanical Conversion
Angular Velocity control

## Theory

Machine gears

## Mechanical Advantage

- Force amplification achieved by devices
- Mechanical conversion of Forces
- Simplest form: lever
- (FB)/(FA)=a/b


## Linear vs. Angular Position

- Relationship
  - s=rθ
- Key
  - s = Arc length
  - r = Radius
  - θ = Radians


## Linear vs. Angular Velocity

- Linear Velocity
  - Straight line motion from reference point
  - Unit: m/s
  - v=s/t=(rθ)/t
- Angular Velocity (ω)
  - Rotational motion around a reference point
  - Unit: rad/s
  - ω=θ/t


## Gear Ratio

- Key Components
  - Torque (T)
  - Number of teeth (n)
- Ratio
  - (T2)/(T1)=(n1)/(n2)
  - Same for all components


## Gear Train Mechanical Advantage

- Power=torque(T) ×angular velocity(ω)
- Ideal Case
  - Power in = Power Out
- Input Gear > Output Gear
  - Speed Increases, Torque Decreases
- Input Gear < Output Gear
  - Speed Decreases, Torque Increases

## Transfer Function & Analysis

- Transfer Function
  - (T2)/(T1)=−(n1)/(n2)
  - Negative accounts for direction change between gears
- Torque
  - T_(out) =−(n_(in))/(n_(out))T_(in)
- Angular Velocity
  - ω_(out) =−(T_(out))/(T_(in))ω_(in)
  - ω_(out) =−(n_(out))/(n_(in))ω_(in)

## Gear Design Nomenclature


## Gear Design Nomenclature


## Types


## Relevance & Project Design

Rolls of blueprints

## What’s Needed

- Record Steering Wheel Position
  - Fit inside the car
  - Physical Rotational Boundary: 960 degrees
  - Connect the car to an electrical encoder: 360-degree limit*
*Free Spinning. Does not account for full rotations

## Design

- Encoder Limits: 360 degrees
- Car Limits: 960 degrees
- 8:3 ratio

## Design


## Final Design


## References

- https://clubtechnical.com/gear-train
- https://khkgears.net/new/gear_knowledge/gear_technical_reference/gear-trains.html
- https://learnmechanical.com/gear-trains/
- https://www.differencebetween.com/difference-between-angular-velocity-and-vs-linear-velocity/
- https://math.libretexts.org/Bookshelves/Precalculus/Book%3A_Trigonometry_(Sundstrom_and_Schlicker)/01%3A_The_Trigonometric_Functions/1.04%3A_Velocity_and_Angular_Vel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
- https://www.mech4study.com/kom/gear-terminology-basic-defination-used-in-gear.html/

## Thank You

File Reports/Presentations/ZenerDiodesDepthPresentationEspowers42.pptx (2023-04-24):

## Zener Diodes

By: Ethan Powers

## What are Zener Diodes?

- Diode designed to allow current to flow backwards when the Zener voltage is reached
- Have a sharp highly doped p-n junction
- Come in a great variety of Zener voltages


## P-N Junction

P-type semiconductors- created by doping an intrinsic semiconductor with an electron accepter element
N-type semiconductors- created by doping an intrinsic semiconductor with an electron doner element
Doping- the intentional introduction of impurities into an intrinsic semiconductor with the purpose of modulating its properties
Hole- a quasiparticle which has a lack of an electron at a position where one could exist
Depletion Region- insulating region where mobile charge carriers have been diffused away or forced away by an electric field

## P-N Junction

Image result for PN Junction Gif

## How do Zener Diodes Work?


## Zener Effect

- Is a type of an electrical breakdown discovered Clarence Melvin Zener in 1934
- Under low reverse voltages the electric field intensity increases and creates free electrons
- These free electrons then pass through the barrier by quantum tunneling

## Quantum Tunneling

- Quantum mechanical phenomenon where an electron or atom passes through an energy barrier when the object does contain sufficient enough energy
- Electrons pass through the barrier when the electric field is very strong

What is it? - Quantum Tunnelling

## Valence and Conduction Bands


## Energy Diagram for Zener Effect


## Difference Between Zener Diodes and Other Diodes

- Can allow current to pass in the reverse direction
- Have a smaller depletion region
- Can operate in the avalanche region
- Has a slower reverse recovery time


## Waveform Clipper


## Voltage Shifter


## Voltage Regulator


## How I Used Zener Diodes


## Pros and Cons of Zener Diodes

- Pros

- Very Cheap
- Circuitry involved around using them is very simple
- High performance standard
- Great for regulating voltage

- Cons

- Wastes power when used as a voltage regulator
- Slower reverse recovery time when used in forward bias
- A variance in temperature can cause problems if not addressed

## Sources

- Valence and conduction bands – Wikipedia (https://en.wikipedia.org/wiki/Valence_and_conduction_bands)
- Zener Diode - Special Devices - Solid-State Devices (ecstudiosystems.com) (https://ecstudiosystems.com/discover/textbooks/solid-state-devices/special-devices/zener-diode/)
- Depletion region – Wikipedia (https://en.wikipedia.org/wiki/Depletion_region)
- Zener diode – Wikipedia (https://en.wikipedia.org/wiki/Zener_diode)
- Difference Between PN Junction & Zener Diode (with Comparison Chart ) - Circuit Globe (https://circuitglobe.com/difference-between-pn-junction-and-zener-diode.html)
- What is a Zener diode and how does it work? -… | (https://www.circuitbread.com/tutorials/what-is-a-zener-diode-and-how-does-it-work)CircuitBread (https://www.circuitbread.com/tutorials/what-is-a-zener-diode-and-how-does-it-work)
- Zener Diode - Working, Characteristics and Applications (vedantu.com) (https://www.vedantu.com/physics/zener-diode)
- ECSTUFF4U for Electronics Engineer: Advantages and disadvantages of (https://www.ecstuff4u.com/2019/03/advantages-and-disadvantages-of-zener.html)zener (https://www.ecstuff4u.com/2019/03/advantages-and-disadvantages-of-zener.html) diode (https://www.ecstuff4u.com/2019/03/advantages-and-disadvantages-of-zener.html)
- What is Zener Diode? Operation Principle, Types & Uses of Zener Diode as Voltage Regulator, Waveform Clipper and Voltage Shifter (circuitdigest.com) (https://circuitdigest.com/tutorial/zener-diode-types-applications-and-operational-principle)

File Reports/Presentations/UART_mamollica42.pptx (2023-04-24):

## UART

Universal Asynchronous Receiver/Transmitter
Michael Mollica

## History Of UART

- Gordon Bell – Digital Equipment Corporation (1960’s)
- Idea was to create a “Universal” communication protocol
  - Data Format
  - Transmission Speed
- Less common in modern electronics due to USB and Ethernet protocols

Download Digital Equipment Corporation (DEC) Logo in SVG Vector or PNG ...

## BACKGROUND

## Asynchronous vs. Synchronous

- NO CLOCK

- Combinational Logic
- Push Buttons
- Switches

- CLOCK

- Flip-Flops
- State Machines
- Processors

*Note: UART still requires speed to be configured even though it does not operate with a clock.

## Serial Communication

- Simplex / Half Duplex / Full Duplex
- Receiver & Transmitter
- Bits are sent/received one at a time
- Much more widely used compared to Parallel Communication
  - Trouble in High Frequency Systems


## UART Connectivity

- Two lines for serial data (Rx, Tx)
- One line for common ground
- Device 1 Rx connects to Device 2 Tx (and vice versa)
- 1 Master and 1 Slave
- Both devices must have the same Baud Rate


## Baud Rate

- Baud Rate != Bit Rate
- Bit Rate = # of Bits / Time
  - Alternatively, Bit Rate = Baud Rate x Bits per symbol
- Baud Rate = # of symbols / Time
- 9600, 57600, 115200, etc.


## UART Packet

- Data is sent in packets
- Packets contain: Start bit, Stop bit, Parity bits, and Data bits
- Start bit denotes the beginning of a data frame and begins the process of reading in the UART (Usually LOW)
- Parity bits are used for error checking (Even, Odd)
- Stop bit(s) denotes the end of a data frame (Usually HIGH)

## HARDWARE

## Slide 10


ATMega8U2 USART Block Diagram (Chip on Arduino UNO) [3]

## Key Hardware Components

- Parity Generator
  - Even Parity = Dn-1 xor … xor D1 xor D0 xor 0
  - Odd Parity = Dn-1 xor … xor D1 xor D0 xor 1
- Clock Recovery
  - Synchronizes the receiver input with the system clock
- Data Recovery
  - Samples each received bit three times and outputs the majority value
- Parity Checker
  - Compares receiver parity bit with calculated parity
- UDR (Transmit & Receive)
  - Buffer used to store transmitted and received data (FIFO)

## SOFTWARE

*Particularly for Arduino

## UART Configuration

Software must initialize the following:
Baud Rate
Parity
Data Bits
Arduino Serial Functions:
Serial.begin(BR) → void
Serial.available() → bool
Serial.read() → byte
Serial.write(val) → void


## Why Choose UART?

- Advantages

- No Clock required
- Two wires needed
- Error checking
- Modifiable data packet
- Long distance (Up to 1000 meters)
- No addressing needed

- Disadvantages

- One-to-One communication
- Must configure Baud Rate
- 9-bit maximum data packet

## Application in Capstone


Master MCU connection


Shifter MCU connectivity

- Send shifter data captured on Arduino UNO to Arduino Mega Master MCU
- UART sends shifter position at 115200 Baud Rate

## Sources

- [1] UART: A Hardware Communication Protocol Understanding Universal Asynchronous Receiver/Transmitter | Analog Devices (https://www.analog.com/en/analog-dialogue/articles/uart-a-hardware-communication-protocol.html)
- [2] Baud Rate and its importance – (https://www.geeksforgeeks.org/baud-rate-and-its-importance/)GeeksforGeeks (https://www.geeksforgeeks.org/baud-rate-and-its-importance/)
- [3] ATmega8U2 | Microchip Technology (https://www.microchip.com/en-us/product/ATmega8U2)
- [4] What is UART? Basics of UART | Instrumentation and Control Engineering (automationforum.co) (https://automationforum.co/what-is-uart-basics-of-uart/)
- [5] UARTs Provide Reliable Serial Communication | (https://www.digikey.com/en/articles/uarts-ensure-reliable-long-haul-industrial-communications)DigiKey (https://www.digikey.com/en/articles/uarts-ensure-reliable-long-haul-industrial-communications)

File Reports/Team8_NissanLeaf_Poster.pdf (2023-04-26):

# Nissan Leaf Driving Simulation

Brett Harden, Gerardo Mateo Laras, Michael Mollica, Ethan Powers, Chase Colotta Advisors: Dr. Nan Chen & Jesse Roberts
Project Overview | Outcomes

The ME and ECE department requested that the Nissan Leaf residing in Lewis Hall be engineered to act as the input controller to a pre-existing driving simulation created by a previous capstone team. The goal was to use all OEM parts or sensors to capture data for steering, accelerating, braking, shifting, and auto-light control in real-time. All data is currently being consolidated to a single MCU that will eventually feed all signals into the simulation in a future capstone project.

The team was able to successfully meet nearly all system design constraints with the given solution. Modifications were made to our design as necessary to account for calculation, instrumental, and system errors such as steering wheel rotation and common grounds for the MCUs. Currently, the system captures brake and accelerator pedal compression percentage, steering angle in each direction, auto-light signals, and shifter position in under 100 milliseconds. Simulator connection was a failure due to issues with the existing code and inability to bring the PC into the vehicle lab.

## Solution

## Future Work

- Fix existing driving simulator software or create new software
- Feed collected data into Simulink physics engine
- Create systems for additional inputs: radio, windshield wipers, etc.
- Move simulator PC into Lewis Hall to connected to Master MCU
- Lift front wheels from the ground for easier steering
- Redundant brake sensor for error checking

## Budget

TOTAL COST ➔ $684.18

## System Constraints

- Real-time data transfer (100 milliseconds or less)
- Display simulation speed in vehicle in an aesthetically pleasing manner
- Detect steering angle with no greater than 1° of error
- Detect shifter positions: Park, Drive, Reverse, & Neutral
- Detect accelerator & brake pedal position
- Detect Low Beam, High Beam, Turn-signals, & Hazard lights
- Power all OEM components with 12 V DC power supply
- Read CAN Bus data at no less than 10 Hz

1 1

24

1 | 1 | 1 | 1

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
1 | 2 | 3 | 4 | 5 | 6 | 7 | 8 | 9 | 10

System Timing (ms)

CAN Timing | Master MCU Timing

Figure 5: Power System Schematic

Figure 6: Data Propagation Delay

Figure 2: Steering Gear System

Figure 3: Speedometer Module

Figure 1: System Flow
Figure 7: Vehicle Interior

Figure 4: Sample Output

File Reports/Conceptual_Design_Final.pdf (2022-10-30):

# Nissan Simulation Conceptual Design

Michael Mollica, Chase Colotta, Brett Harden, Ethan Powers, Gerardo Mateo ECE Department
Tennessee Technological University mamollica42@gmail.com, cdcolotta42@tntech.edu, bpharden42@tntech.edu, espowers42@tntech.edu, gjmateolar42@tntech.edu
I. INTRODUCTION
Tennessee Tech currently has a driving simulator using
Logitech controllers in the basement of Brown Hall. This simulator was built and designed by a mechanical engineering (ME) capstone team a few years ago. While the simulator was sufficient for providing the university with a generic driving simulation, the electrical and computer engineering (ECE) department has decided to team up with the ME department to further improve this old project. The ECE team is tasked with converting a 2014 Nissan Leaf that resides in Lewis Hall into a real-time accurate driving simulation that uses Nissan hardware as opposed to game controllers. This Nissan Leaf is cut in half, removing the rest of the car behind the driver’s seat.
A. Problem Definition
Team 8 intends to replace the controllers that interface with the simulation to the Nissan Leaf’s hardware which includes, but is not limited to the steering wheel, pedals, and shifter. The use of this hardware will still provide real-time and accurate inputs into the simulation to provide the most realistic driving experience possible to its user. To achieve this goal, the car must be powered and tested for the data outputs from the Controller Area Network (CAN) bus, Nissan sensors already inside the vehicle, and external sensors installed by the team. The CAN bus is the highway for all data being communicated between different systems of a vehicle. Thus, the CAN bus contains useful information about steering angles, throttle position, gear position, and brake status. The team will not pull data from the CAN bus because data will not be able to be decrypted, but the team will still capture its outputs. The Nissan sensors and external sensors will be the target for data acquisition. The data extracted from the sensors shall be sent to local microcontrollers to interpret the outputs of the sensors. The local microcontroller data shall then be sent to a master microcontroller that receives the data from each local microcontroller. The master microcontroller will then interpret and communicate data into a personal computer (PC) for use in the driving simulator. The following is the list of shall statements that fully describes the project requirements:
- Shall integrate external systems such that the Nissan Leaf steering wheel, pedal positions, blinker, shifter position, and headlight selection are detected and sent into the simulation.
- The CAN bus data shall be captured in no less than 10 Hz transmission speed.
- Shall integrate an external speedometer such that the simulation data controls the speedometer.
- Shall develop bypass strategy to enable vehicle operation without the back half.
- Shall implement power system that requires flipping a single switch to turn on.
- Shall develop and deploy a testing strategy to identify which original equipment manufacturer (OEM) sensors are functioning and which are not.
- Shall include safety device to protect components from power overloads.
B. Constraints
The three main constraints of the design are as follows:
1. National Electrical Safety Code (NESC)
2. Accuracy of Data Outputs
3. Unique Implementation of Subsystems

The engineering standard constraining the design of the project is the Institute of Electrical and Electronics Engineers (IEEE) NESC. This safety code lays out all the fundamental precautions to be taken when working with and designing electrical hardware that has inherent hazardous potential [1]. The power system of the design shall include a breaker or fuse box system to prevent overloading components. The fuse system can protect the circuits in the vehicle and the external components from damage or possible failure. To conceal exposed wires, the team shall encase all wires in an insulting material so no direct contact can be made with the user.

Constraint 2 involves the broader impacts of the project. The simulation is to be used to replicate driving a real vehicle as accurately as possible. Any inaccuracies in the simulation can lead to a poor learning experience that can negatively impact a new driver on the road. This can then lead to more accidents and fatalities which opposes the societal goal of the project [2]. To overcome constraint 2, the team shall implement a testing strategy for each subsystem to ensure the output data is accurate compared to a stock Nissan Leaf. Additionally, sensors installed in the vehicle shall have a low margin of error to provide the most accurate data possible.

Constraint 3 is an ethical consideration the project must follow. The team shall not steal or implement any trademarked designs in the project. This includes not replicating the Logitech controllers that already interface with the simulation. Therefore, each subsystem of the design shall be designed only by the team members of the project.

II. PURPOSE OF CONCEPTUAL DESIGN
Designing a complex system is constrained by engineering standards, broader impacts, and ethical concerns. All of these must be accounted for before physical construction of the system can occur so that the project’s lifecycle is optimized both economically and timely. For each constraint that is ignored and not incorporated in the design, costly maintenance of the product will be required. Therefore, it is imperative that the team recognizes and accounts for each constraint in the individual subsystems of the design.

To maximize the goals of the customer, all requirements must be met within the boundaries of the constraints. Detailing each requirement must be completed in the conceptual design before construction beings so that the customer is satisfied with the final product. Unfortunately, the project contains some critical unknowns that may inhibit the team’s ability to fully deliver the final design. These critical unknowns include wiring schema, CAN bus encryption, and OEM sensor functionality from cutting the vehicle in half. To minimize these risk sources, the team is installing external sensors for most of the subsystems. The sensors being installed can be fully understood by the team through datasheets provided by the manufacturers so that they may be properly implemented.

By planning for the project to be designed around the risks, goals, and constraints associated with it, the team can create a detailed design that utilizes the least number of resources possible. Ultimately, the conceptual design allows the team to layout the steps to complete the final project within an optimal timeline.

III. SUBSYSTEM DESIGN

A. Power Systems


Figure 1. Block Diagram of the Power Sub-system

The internal control systems of the car were originally powered by a 12 V dc battery. With the conversion of this car to being an input device for the simulator, the battery will not be recharged from normal car usage and needs to be replaced with a continuous power supply. So, the beginning design of the power system for the car is transferring the 12 V terminals from a battery to a continuous power supply.

For implementation and control of the power system, there will be a cutoff switch installed in series with the power supply output to disconnect all power to the car. This will allow for an accessible point to safely turn the power on and off for the system that does not put the user in danger. The switch will also house a fuse to protect the power supply for any chance of exceeding the rated current due to an inrushing current from when the switch is closed. This instantaneous spike in current to charge the entire system to its initial steady state levels could overload the power supply and damage its internals. So, when implementing a power switch, the design and specifications for it need to be in a manner that will not jeopardize the integrity of the power supply and system [3].

With the power supply being 12 V, it is known that lower voltage will be needed for at least the microcontrollers. Most microcontrollers are powered by 5 V DC, and this proposes the problems of needing either a DC-DC converter or another power supply for 5 V. Due to the cost for another AC-DC power supply being greater than a converter, either a DC-DC buck converter or an operational amplifier will be used for this design rather than another supply. The loads on the converter should mainly be the sensors and microcontrollers. In designing the optimal converter circuit, Spice simulations will be completed to see the maximum loads that could be applied to the converter and what the minimal current requirements are needed and determine if one single converter will be enough.

A problem with a single converter compared to multiple is the receiving voltage at each component of the load. Depending on the length of the line being run, the voltage at each component may drop below the required input level and force the converter to be closer to the component. This concern will be tested analytically with simulations and calculations of the voltage drop for different lengths of wire with respect to the wire size.

To reinforce the safety of every component that will be design and installed, a layer of protection will be added in series with the components in the form of a fuse. The value of each fuse will be based off the required power of the component that it is in series with and the maximum current that can be supported by the wire. Ideally, the sensor or microcontroller that is at the receiving end will be the limiting factor with the wire being large enough to support the current needed. The fuses for each system will be found and then placed into a centralized fuse panel for ease of verifying that all fuses are still functional if there were to be any issues. The National Electrical Code (NEC) states in article 240 what requirements are needed for protection from overcurrent, and this standard will be the largest constraint to the design of the fuse panel and the fuse for each component system [4]. The requirements from NEC’s article 240 will be the deciding factor in which the panel will be constructed.

Different from the external system, the Nissan Leaf already has an internal fuse box for all the OEM components. The OEM components are connected to a fuse box between components and the battery terminals. This fuse box was designed for the internal system and should meet safety requirements and constraints. The component restrictions from the manufacturer should not require modification since this fuse box should already be safe and efficient in its design. This provides the safety needed for the OEM systems.

B. Gear Shifter


Figure 2. Block Diagram of the Shifting Sub-system.

The CAN bus will be used to read the outputs from the
gear | shifter. | These | outputs | will | be | collected by a
local microcontroller. The local microcontroller will then send the outputs to a master microcontroller. Also, a position sensor for each position will be mounted on the frame around
the shifter. These | outputs | will | be | collected by a
local microcontroller. The local microcontroller will then send the outputs to a master microcontroller. The local microcontroller will read data from all of the sensors, but it will only send one value indicating what gear the position is to the master microcontroller. The sensors will be powered by a 12 V power supply and will be stepped down using an amplifier circuit. This will be used to ensure that the sensor is receiving the appropriate amount of voltage. C code will be created to compensate for the gear shifter’s three second time delay to put the Nissan Leaf in neutral. Without this, the sensor would be reading that the car is in neutral when it could be in park. These two methods will be used for redundancy, so the car’s gear is always matching with what is being stored in the microcontroller. The sensors and CAN bus will operate at 100% accuracy due to the accuracy constraint and the high importance of knowing what gear the car is in due to the negative impacts it could have on the functionality of the car and simulation.

If the signal being sent to the microcontroller is not accurate when compared with the actual gear of the car, it could cause the accelerator pedal to not work properly due to the car being in park even though the sensors read that it is in drive. To measure the accuracy of the sensors and CAN bus, the team will continuously check to see if the signal being sent to the microcontroller matches what gear the car is in. The team will go through many trials of testing to ensure that there
is | zero | error | in | accuracy. To | verify | that | the
sensors are receiving the appropriate amount of power, a multimeter will be used to measure the power being sent to the sensor. This will be checked until the sensors are consistently receiving the appropriate amount of power.
C. Steering Wheel


Figure 3. Block Diagram of the Steering Wheel Sub-system.

The steering wheel subsystem in the block diagram is a system to measure the angle and the rate of rotation inside the steering wheel. Also, inside the subsystem, the sensor shall communicate with the local microcontroller and store the information. The local microcontroller shall send the stored information to the master microcontroller.

Since the steering wheel is unique for many different vehicles, this will create a constraint for the subsystem. For the Nissan leaf, the input range constraint arises due to the steering wheel having 2⅔ rotations from the limitation of the left and right (980 degrees). Since this restriction of 2⅔ rotations of the steering wheel exists, the sensor shall measure within that range. The rate of the steering wheel, however, shall assist in improving angle measurement. There is a small constraint when it comes to identifying a sensor that is not too sensitive to movement, which could lead to high error rates.

The precision of the encoding of the output comes from "shall be in the range 2⅔ ". Given 2⅔ rotation, the user is able to rotate the steering wheel with 0 to -480 degrees representing the position from the center to the right limit (clockwise) and 0 to 480 degrees representing the position from the center to the left limit (counterclockwise).

An output angle shall be created and sent to the local microcontroller. It is critical to note that the rate of steering wheel rotation shall send a general idea about what the driver is doing with the steering wheel to the microcontroller. Both sensors shall transmit information to the local microcontroller that results in a realistic steering experience. An example of this will be when the user turns a positive 45 degrees on the left and moves to steer fast. The first sensor shall detect the speed and give an idea to the local microcontroller before the user turns the steering wheel completely. Also, the second sensor will send how much the steering wheel rotated.

The purpose of unit tests and integrated test units is to ensure constraints are met analytically before using them. The unit test will check that the rotation is positioned correctly and send verification to a display that is ready to use. However, the integrated test unit will detect if the sensor is working efficiently and send a confirmation to display each sensor's working. When establishing the integrated test unit and unit test, an oscilloscope or multimeter shall check whether the sensor is producing any signals.

D. Accelerator and Brake Pedals


Figure 4. Block Diagram of the Accelerator and Brake Pedals.

The purpose of this subsystem is to gather data of the position of the pedals and send it to the master microcontroller to be implemented into the simulation. This subsystem is made up of the atomic pieces of the accelerator angle sensor, the brake angle sensor, and the local microcontroller their outputs feed into. The inputs of the sensors come from the power system and the OEM pedals. This subsystem outputs data to a local microcontroller from each sensor. These signals are then processed in the local microcontroller and sent to the master microcontroller. The brake pedal and the accelerator atomic systems will be implemented identically on the hardware aspect. To differentiate the output signals of the pedals, the microcontroller subsystem will send the data to the simulation and store it in the appropriate parameter within the physics engine that controls the brake pressure and acceleration of the vehicle respectively.

The subsystem is constrained by Constraint 1 and Constraint 2. It must be compliant with Constraint 1 because the user could negatively affect the system if the wires and the sensors are not secured safely. In the event a wire is not properly secured or protruding from the pedal, the user could interrupt the signal by damaging the hardware below their feet. Constraint 2 must be followed to get accurate information of the pedal angle for the simulation to be realistic. Discrepancies between the true pedal angles and the measured pedal angles from the sensors could provide a fallacious learning experience to the user. Inaccuracies of this kind are not to be tolerated from a civil standpoint. To verify these constraints, the team will use a multimeter to verify if the current levels are within a safe range of values as well as verifying the voltage output has a direct relation to the angle of the pedals

E. Microcontroller Network


Figure 5. Block Diagram of the Microcontroller Network.
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

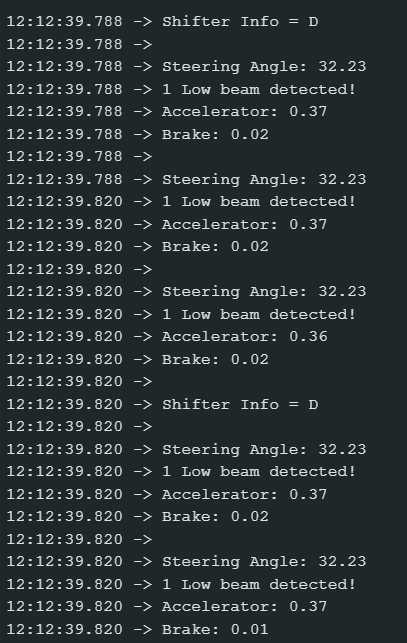
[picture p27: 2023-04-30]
Documentation/Images/SampleOutput.png

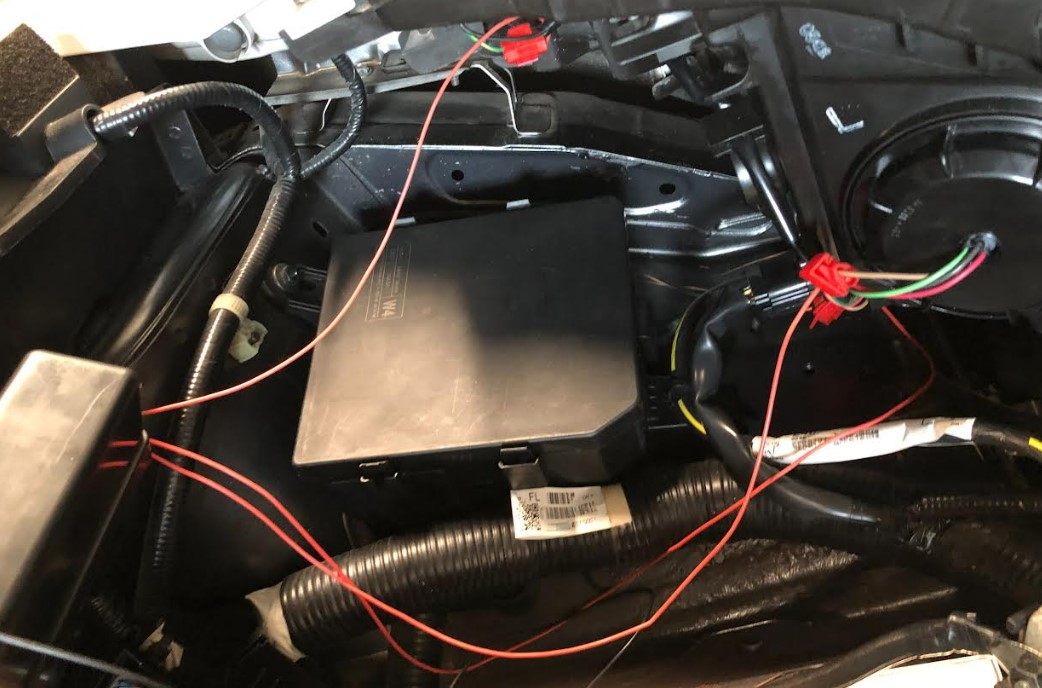
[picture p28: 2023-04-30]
Documentation/Images/HeadlightWireSplicing.jpg

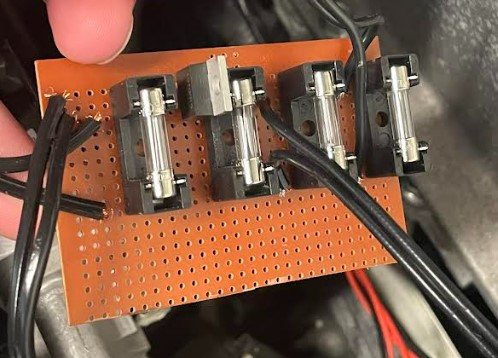
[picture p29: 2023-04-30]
Documentation/Images/External Fuses.jpg

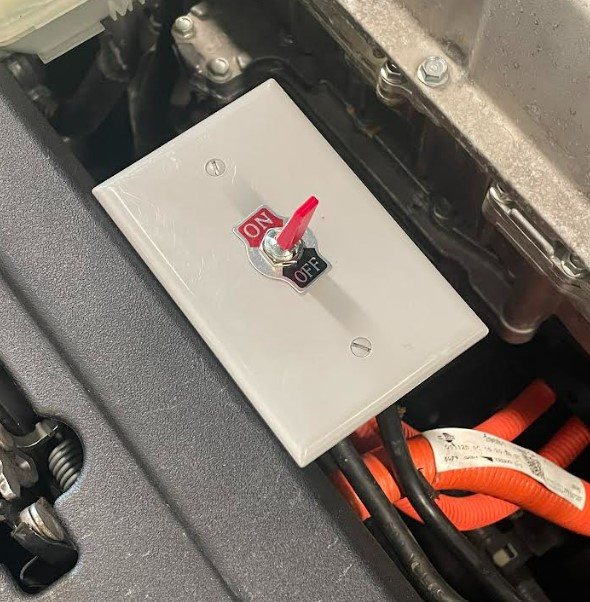
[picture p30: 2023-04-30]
Documentation/Images/PowerSwitch.jpg

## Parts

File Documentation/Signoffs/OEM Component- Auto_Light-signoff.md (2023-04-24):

OEM Component Subsystem- Auto Light
------

## The function of the Auto Light Subsystem
The Master microcontroller will receive the output of the Nissan Leaf AutoLight in this part of the subsystem. Furthermore, the Master microcontroller will detect if the headlight is off, on, blinking, and high and low beams.

### Specification & constraints
   - Must detect the auto light high beams, low beams, and left and right indicators with a voltage of no more than 5 volts and a current below 40 milliamps.
   - Must use OEM componets as the inputs
   - The signal input from the autolight must not exceed 5 V 
   - Implement a way to protect the signal from the input voltage varying from 10 V to 15 V
   - Current to the signal must be less than 1 percent of the current to the light
   - Prevent interference among signals through isolation methods
   
## Auto Light Wiring schematic
opel2437
#### Figure 1: Headlamp(High and low Relay)
<br/>

### Auto Light Wiring Diagram

#### Description
-------
- The auto light wiring diagram shows the whole wiring for each component in the headlight of the Nissan vehicle. However, the main focus are the headlamp relays shown in Figure 1 and they link to the headlamps. This displays how the low beam and high beam functions operate and make the headlight indicate. The wiring diagram reveals that the battery is attached to the CPU through the relay showing that the relay receives power from the battery, but the current is operated by the CPU. The input from the battery is also connected to one side of the relay switch. This means that the input to the lamp and headlight should be 12 V. Also, Figure 1 shows that their fuse connects to the output of the relay, and the fuse can take up to 10 amps. Overall, the key point is to see the headlamp relay, what is connected, and how it works. 

## Design: A Voltage divider from Auto Light to the Microcontroller
<br/>



##### Figure 2: Voltage Divder with Opto-isolation

#### Usage of OEM componets as the inputs 

--------
- From the information in Auto Light Wiring diagram, a method to detect the output of the relay can be created. The design shown in Figure 2 is to splice and add a voltage divider to connect to the microcontroller. This process uses the 12 V potential that is sent to the lamp to illuminate the light to trigger a reaction on the microcontroller. 

### The detection of the auto light high beams, low beams, and left and right indicators and Current to the signal must be less than 1 percent of the current to the light
------

LVT 817
##### Figure 3: From the optoisolator Datasheet
<br/>

- The design behind the voltage divider is to reduce the auto light voltage to no more than 5 V and have a current of less than 1% of the current to the light. This constraint on current is to prevent any exceedance in the limits of the original hardware and wire ratings that could cause overload or failure on the car.

 - The current through the light is 4.79 A.
 
 - The 40 ma forward current was chose for this design to drive led inside of  optoisolator
 
 - which makes the limit to the voltage divider 47.9 mA. 
  
 - 40 mA is decided to be a limit for the safety of the devices added and not exceed the constraint.
 -  assuming that the input voltage could vary from 10 to 15 V

    -  $Max \ Resistance: 375 \ ohms = {15V \over  \ 40 \ mA }$

    - $R1 : 250 \ ohms = {10V \over  \ 40  mA}$  

    - $R2 : 375 \ ohms = {250 \ ohms + R2}$   
       $R2 : R2=375 \ ohms -250 \ ohms=125 \ ohms $ 
  
   - The average active voltage applied should be approximately 12 V. Thus, the limit should not be exceeded.

### Implement a way to protect the signal from the input voltage varying from 10 V to 15 V
----

##### Figure 4: 40 mA Fuse

-  40 mA fuse will be installed to protect against any extreme voltage spikes outside of the 10 to 15 V range that would cause overcurrents. The LTV-817 optoisolator was chosen based on the threshold voltage of 1.2 V, and the maximum current constraint of 40 mA is less than the limit for the LTV-817 at 50 mA. According to the analysis of the design voltage divider and fuse, the protection of the signal from input voltages varying from 10V to 15V comes from a voltage divider, while the protection of current from a current spikes comes from a 40 mA fuse.


##### Figure 5: Voltage Divder

- the design with only a voltage divider has a potential risk due to the chance of a voltage spike reaching the microcontroller and interference from other signals. 
 - ### The analysis of Voltage divider (10 V to 15 V)

   Vout = Vin ${ R2 \over R1+R2}$

   5V = 12V ${ 125 \ ohms \over 250 \ ohms  + 125 \ ohms}$

   $Total \ Resistance: 375 \ ohms = {250 \ ohms +125 \ ohms}$ 

   $Max \ current: 40\ mA = {15V \over 375 \ ohms }$

   $Min \ current: 26.67\ mA = {10V \over 375 \ ohms }$

   Test different voltages going through Voltage Divider(0 to 15)

   

   Test different voltages going through Voltage Divider(10 to 15)

   

- This design shows the vulnerability to signal interferece through the shared ground terminal and the ability for the current to backfeed onto another divider. 
- The voltage divider prevents the chance of the signal voltage to exceed the limit of 5 V due to a spike in the input voltage on the lamp node. The design was modified to include optoisolators to remidy the hazards of both constraints as shown in Figure 2.
- Optoisolators operate on a threshold voltage and are not reliant on current. This means that it can operate on very small currents as long as the voltage meets the minimum requirement. 

### A prevention of interference among signals through isolation methods
___

The optoisolator will take the reduced voltage from the Nissan Vehicle and convert it into a light signal. Then a photosensor will detect the light signal and allow the 5 V to pass through the pin of the microcontroller. The LED that is used to trigger the photosensor also prevents any backfeed current from false triggering a signal. This isolates both systems so that the voltage to the lights does not have a direct path to the signal input. With the microcontroller being used for the 5 V supply in the signal, there should not be a voltage spike to the controller since it would have to be generated by the controller. 

## Master microcontroller communication

A wire will be connected directly to the optoisolator to the digital pin of the master microcontroller. The microcontroller receives voltage from themselves into digital pins, and the optoisolator controls whether the voltage passes through or not based on whether the auto light is on or off. Also, the master microcontroller has availible GPIO pins to shorten the delay of input into the communication network with less items to pass through. With the voltage being either 5 V or 0, the microcontroller will use the digital GPIO pins to read the voltage.

### Summary
The voltage going through the headlight is 12 volts and the current is in the range of 4.0 to 4.7 amp based on research using the auto light diagram from Figure 1 and the Sylvania H13 XtraVision Halogen Headlight Bulb [1]. Furthermore, based on the information, the conclusion can be drawn that the current won't affect the optoisolator, but the voltage will.

| Part | Cost | Qty| total|
|---:|:---:|:--:|:----:|
|250 ohms| $1.060 |  5 |$5.30 | 
|125 ohms| $0.70  |  5 |$3.50|
|LTV-817*| $0.24  | 10 | $2.40|
|Fuseholders|$0.86| 5  | $4.30|
|40mA fuse| $2.67 | 6  | $16.02|

*4 are required. It is the same cost for 10 as it is 6. This provides extras in the event of multiple isolators failing.

reference
---------
[1]https://www.oreillyauto.com/detail/c/xtravision/sylvania-h13-xtravision-halogen-headlight-bulb-pack-of-2/syl5/h13xv2bp/v/a/128040/automotive-car-2014-nissan-leaf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

[2]https://ledlightinginfo.com/led-headlights-amps#:~:text=So%20the%20total%20amps%20drawn,pair%20would%20be%209.16%20amps.

[3]https://optoelectronics.liteon.com/upload/download/DS-70-96-0016/LTV-8X7%20series%20201610%20.pdf

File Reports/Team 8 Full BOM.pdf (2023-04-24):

Product Name | Description | Subsystem | Part Number | Manufacturer | Qty | Price (each) | Item Totals
Rotary Encoder | The product is an absolute rotary incoder with a 6.5 ft output cable. | Steering | TRD-NA1024NWD | Koyo | 1 | $352.00 | $352.00
Mount | This is the right angle mounting bracket for the TRD-NA1024NWD | Steering | JT-035D | Koyo | 1 | $13.00 | $13.00
100k Ohm Resistor | These are the 100k Ohm resistors that will be used for voltage dividers | Steering | CFR25SJT-52-100K | Yageo | 25 | $0.05 | $1.25
Arduino Uno | MCU for reading Rotary encoder, reading shifter, | Steering, Shifter, Speedometer, Pedals | Arduino UNO Rev3 | Arduino | 4 | $27.60 | $110.40
Zener Diode | 5.1 V Zener Diode | Shifter | BZX79-C5V1 | Nexperia USA Inc | 10 | $0.16 | $1.60
100 Ω Resistor | 100 Ω Resistor | Shifter | LR1F | TE Connectivity Passive Product | 10 | $0.14 | $1.40
LCD Display | LCD Compatible with Arduino Uno | Speedometer | Treedix 3.5 inch TFT LCD Display | Treedix | 1 | $18.99 | $18.99
Toggle Switch | 12 V Toggle Switch | Power | TD1-1A-DC-3-R | Switch Components | 1 | $5.08 | $5.08
Standard Diode | Diode (Different fom signoff due to original being out of stock, higher ratings meet requirements) | Power | S-19TQ015-M3 | Vishay General Semiconductor -Diodes Division | 1 | $1.61 | $1.61
18 gauge wire | Wiring terminated to connect to Arduino | Power | 10-02493 | Tensility International Corp | 4 | $7.51 | $30.04
100 mA Fuse | 100 mA fuses to protect Arduinos | Power | 5ST 100-R | Bel Fuse Inc | 6 | $0.63 | $3.78

Fuse Holder | Hold 100 mA fuses | Power | 4628 | Keystone Electronics | 4 | $0.73 | $2.92
CAN-BUS Shield V2 | Arduino board to help capture CAN Bus messages | CAN | CAN-BUS Shield V2 | Seeed | 1 | $32.10 | $32.10
OBDII to DB9 Cable | Cable to connect the Arduino Board to the OBDII port of the Nissan Leaf | CAN | CAB-10087 | SparkFun Electronics | 1 | $10.95 | $10.95
Mega 2560 Rev3 | Microcontroller for the Master Microcontroller System | Master MCU | Mega 2560 Rev3 (Barcode: 7630049200067) | Arduino | 1 | $41.14 | $41.14
USB 2.0 Cable | USB cable for Arduino Mega 2560 | Master MCU | USB 2.0 Cable Type A/B | Arduino | 1 | $7.60 | $7.60
Optoisolator | OPTOISOLATR 5KV TRANSISTOR 4-DIP | OEM Lights | 160-1366-5-ND | Lite-On Inc | 10 | $0.24 | $2.40
250 Ohm Resistor | RES 250 OHM 5% 5W AXIAL | OEM Lights | 55J250E-ND | Ohmite | 5 | $1.06 | $5.30
125 Ohm Resistor | RES 125 OHM 1/4W 1% AXIAL | OEM Lights | RN60D1250FB14-ND | Vishay Dale | 5 | $0.70 | $3.50
40 mA Fuse | FUSE GLASS 40MA 250VAC 5X20MM | OEM Lights | 486-1876-ND | Schurter Inc | 6 | $2.67 | $16.02
Fuse Holder | FUSE HOLDER CART 250V 6.3A PCB | OEM Lights | RPC3981-ND | Essentra Components | 5 | $0.94 | $4.70
Wire Splices | Solderless wire splice connecters (package) | Pedals | B09539VNBK | XGTECH | 1 | $7.99 | $7.99
22 AWG | 22AWG wire 2 color 100ft | Pedals | B089D211KX | Fermerry | 1 | $15.49 | $15.49
| | | | Total Items | 105 | Total Price | $689.26

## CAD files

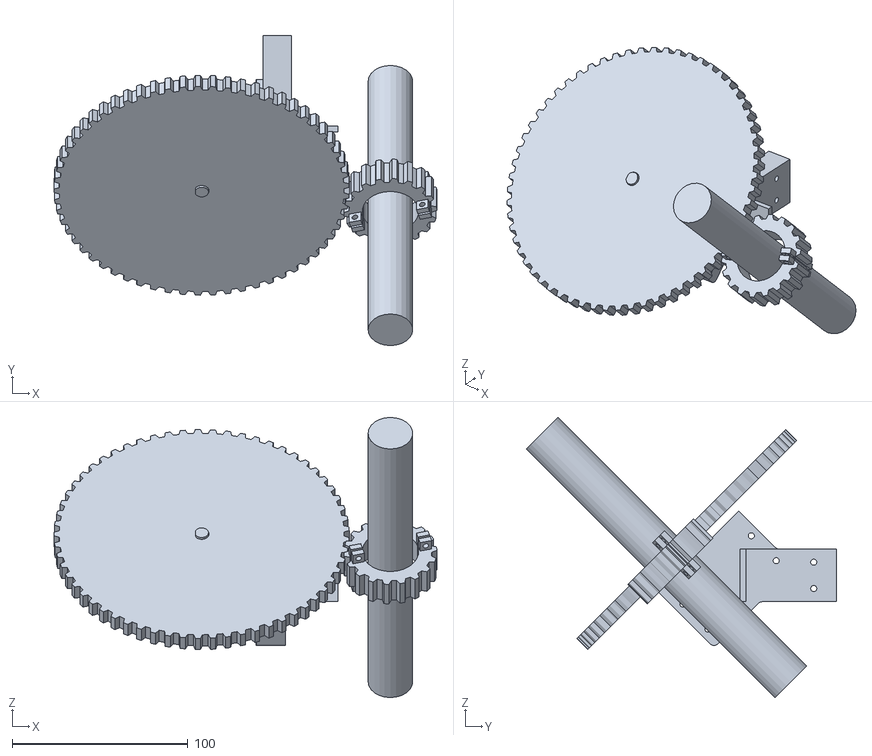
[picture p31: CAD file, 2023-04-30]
Documentation/3D Models/Steering/Final Steering Assembly V2.stl
217.9 x 176.5 x 159.4

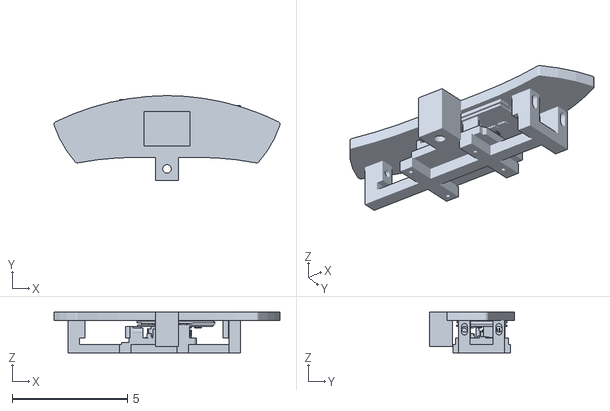
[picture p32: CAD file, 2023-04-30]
Documentation/3D Models/Speedometer/Final Speedometer Assembly v2.stl
9.82 x 3.69 x 1.78

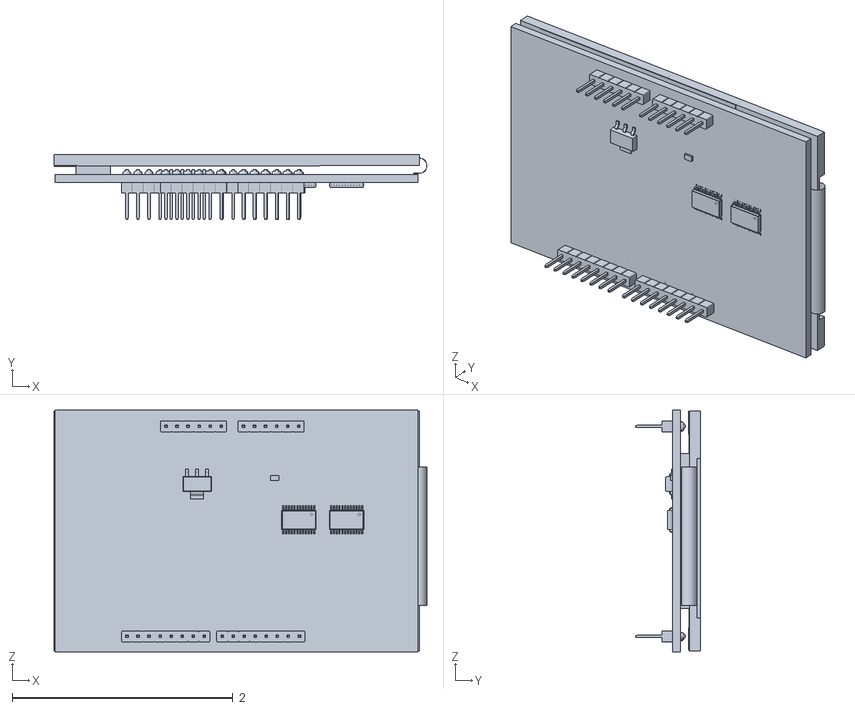
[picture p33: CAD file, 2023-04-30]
Documentation/3D Models/Speedometer/3.5LCD.stl
3.38 x 0.584 x 2.19

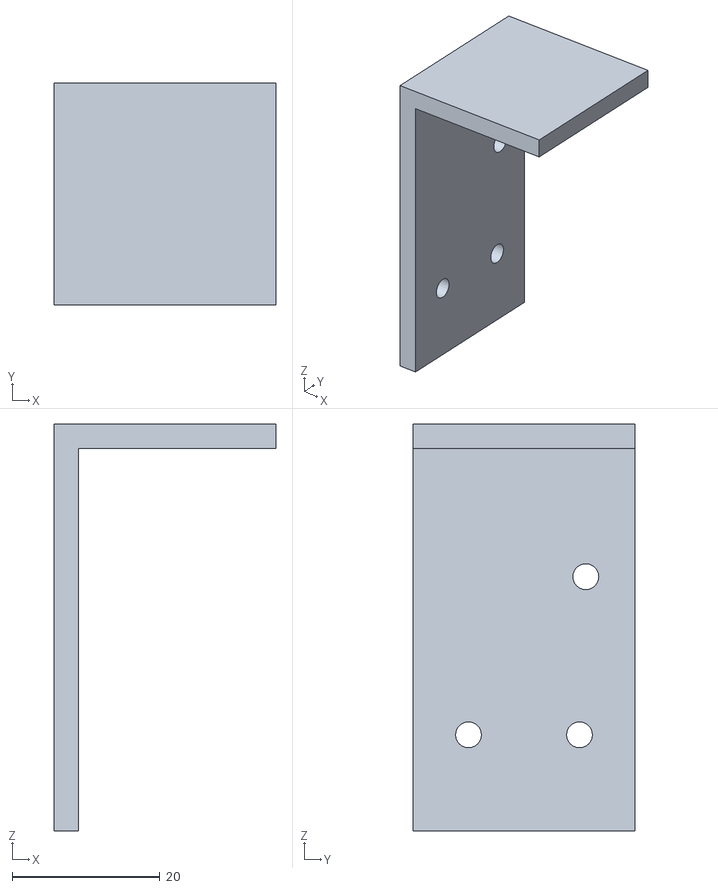
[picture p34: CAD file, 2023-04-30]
Documentation/3D Models/Steering/Car Mount Arm.stl
30.0 x 30.0 x 55.0

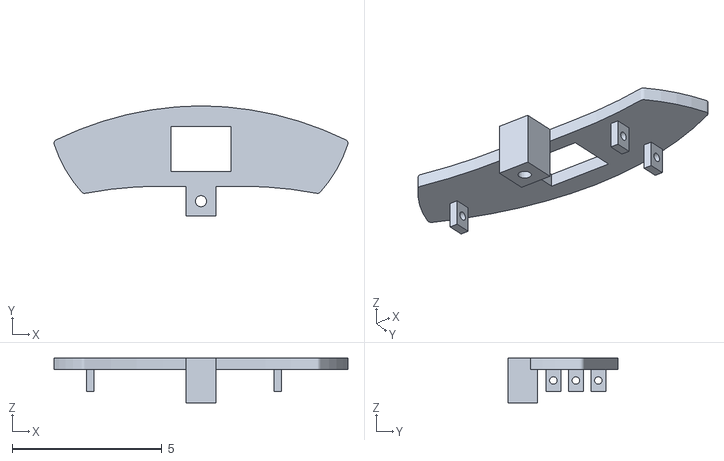
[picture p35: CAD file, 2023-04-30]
Documentation/3D Models/Speedometer/SpeedometerShield.stl
9.82 x 3.69 x 1.50

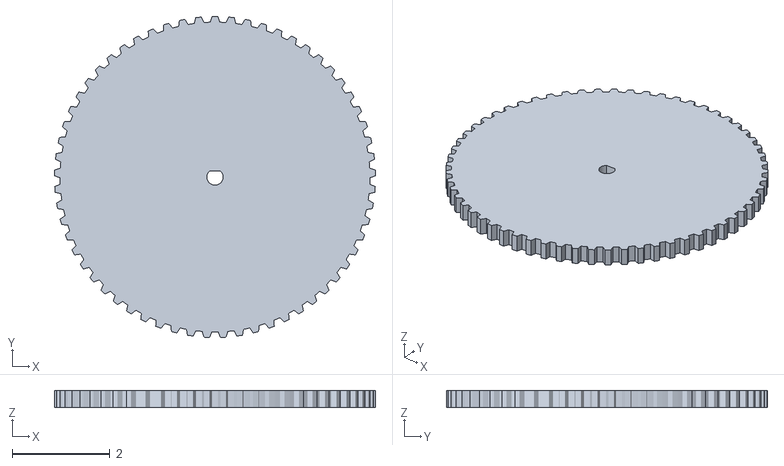
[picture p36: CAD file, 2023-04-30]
Documentation/3D Models/Steering/Steering Larger GearV4.stl
6.56 x 6.56 x 0.35

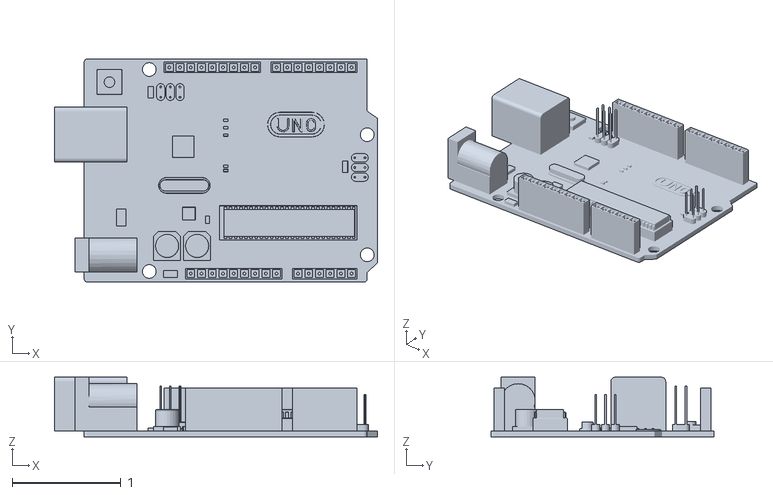
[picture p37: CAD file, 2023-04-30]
Documentation/3D Models/Speedometer/ArduinoUno.stl
2.96 x 2.05 x 0.547

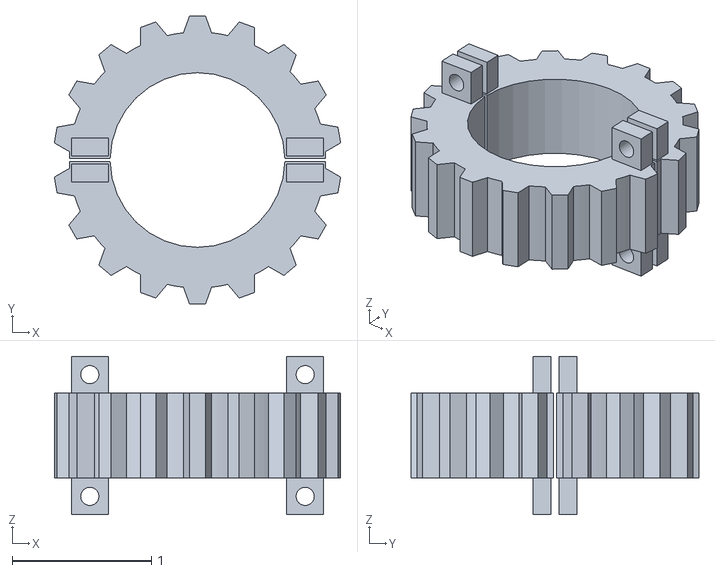
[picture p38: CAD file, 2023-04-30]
Documentation/3D Models/Steering/Steering Smaller GearV3.stl
2.06 x 2.07 x 1.14

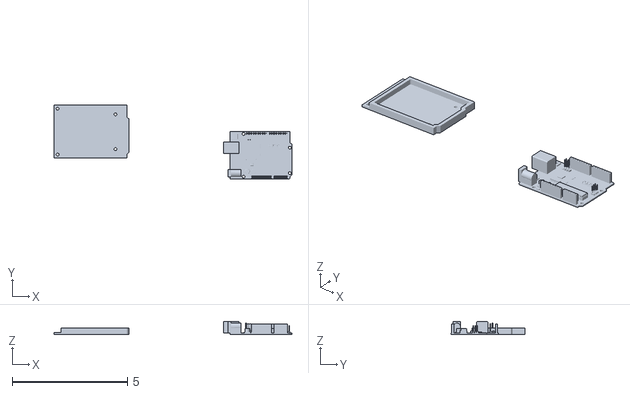
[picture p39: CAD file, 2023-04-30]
Documentation/3D Models/Speedometer/ArduinoUnoR3.stl
10.3 x 3.20 x 0.547

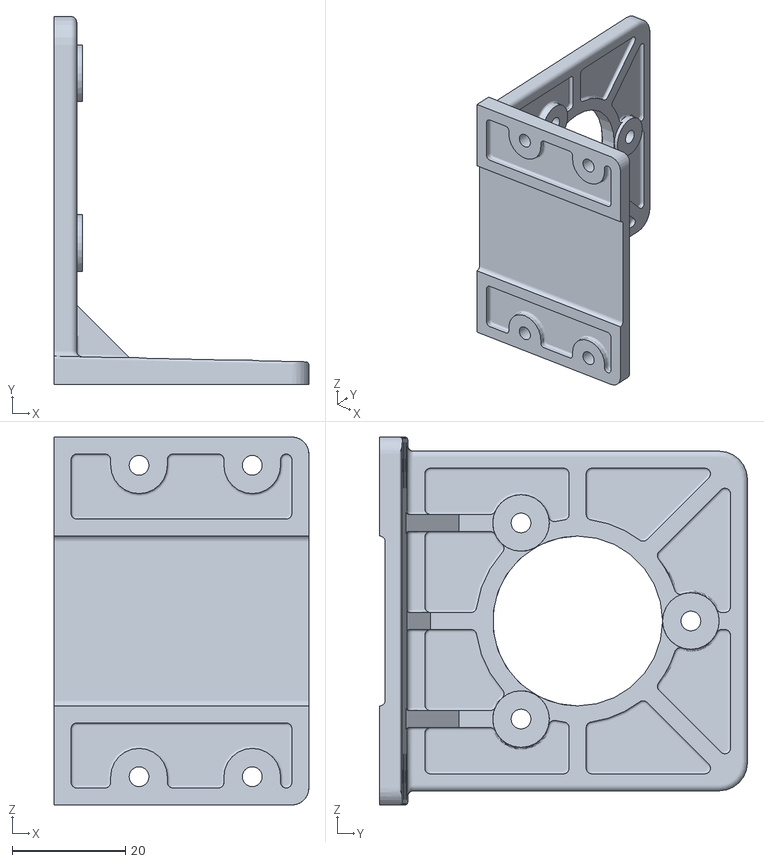
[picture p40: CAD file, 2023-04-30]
Documentation/3D Models/Steering/jt-035d_3D.stl
45.0 x 65.0 x 65.0

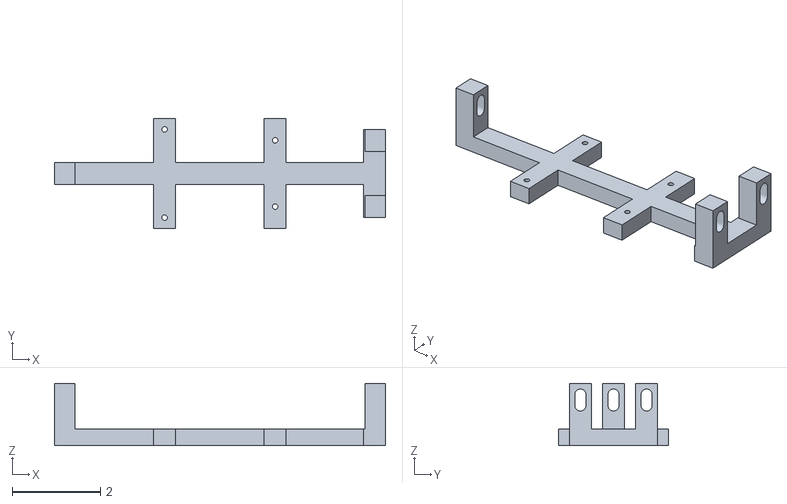
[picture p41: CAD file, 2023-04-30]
Documentation/3D Models/Speedometer/mounts_v2.stl
7.50 x 2.50 x 1.41

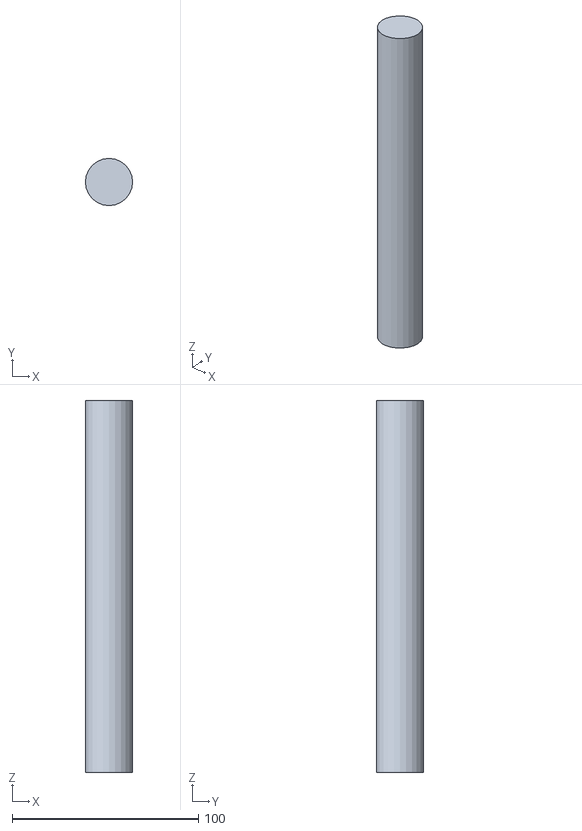
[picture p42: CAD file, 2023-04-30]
Documentation/3D Models/Steering/Steering Column.stl
25.4 x 25.4 x 200.0

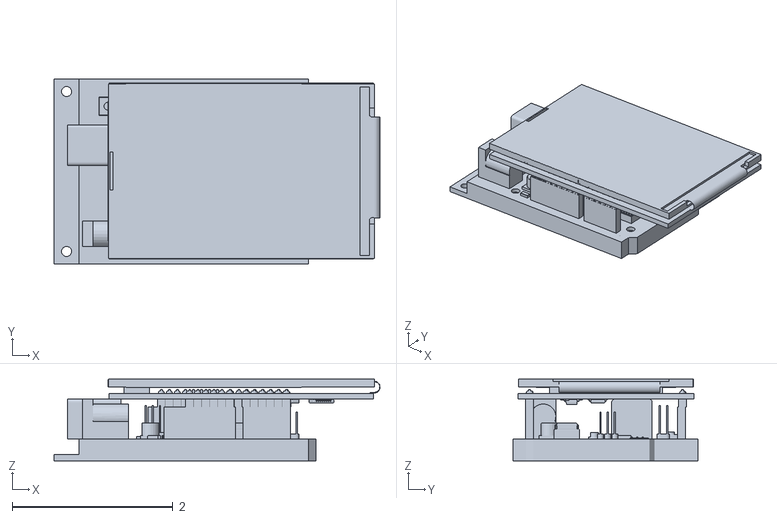
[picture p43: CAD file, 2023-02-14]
Documentation/3D Models/Speedometer/LCDArduinoBase.stl
4.05 x 2.30 x 1.02

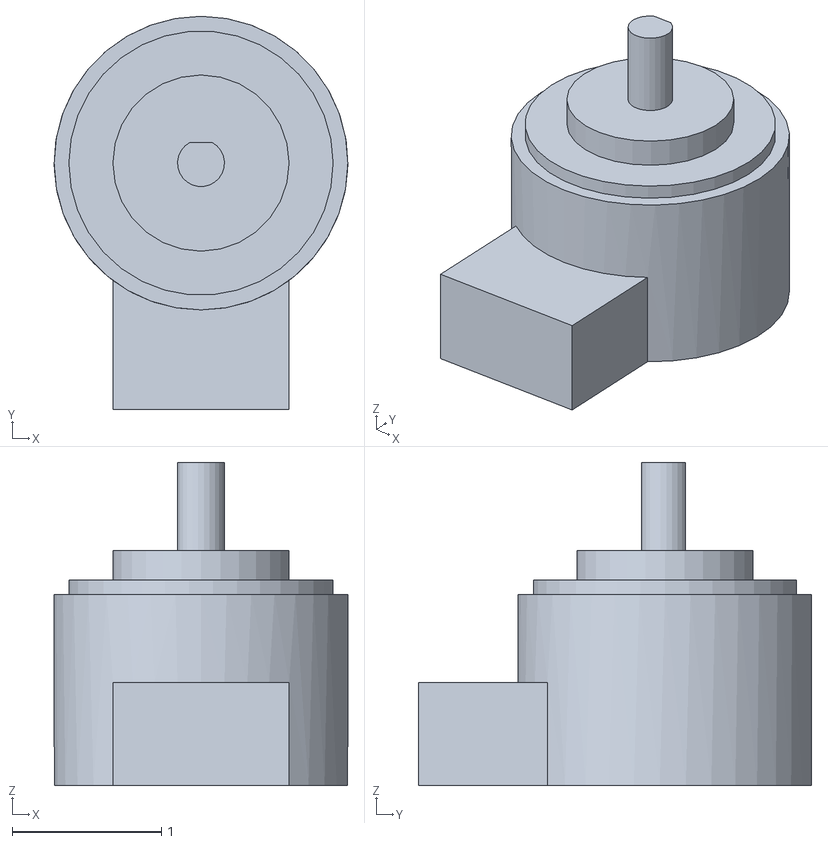
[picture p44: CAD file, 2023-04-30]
Documentation/3D Models/Steering/Steering Encoder.stl
1.97 x 2.64 x 2.17

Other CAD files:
Documentation/3D Models/Steering/Adapter Plate.stl

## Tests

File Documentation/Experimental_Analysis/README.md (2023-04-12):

Experimental Analysis
------
Each file is contains data and written analysis for each subsystem of the Nissan Leaf. The organization is as follows:
- Pedals Subsystem --> Accelerator&Brake.md
- Auto-light Subsystem --> AutoLightAnalysis.md
- CAN Bus Subsystem --> CANAnalysis.md
- Master MCU Subsystem --> MasterMCU_analysis.md
- Power Subsystem --> PowerSystem.md
- Shifter Subsystem --> Shifter.md
- Speedometer Subystem --> Speedometer.md
- Steering Subsystem --> SteeringAnalysis.md

Each file addresses the testing and verification of each of the specifications and constraints listed in the **_Signoffs_** folder (Documentation -> Signoffs) for its respective subsystem.

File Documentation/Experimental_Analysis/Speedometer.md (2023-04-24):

SPEEDOMETER SUBSYSTEM ANALYSIS
--------------------

### Specifications & Constraints
- C1. Shall be powered by the PC running the simulator via USB 2.0
-	C2. Microcontroller must be able to read speed data from the simulator while it is running using serial communication
-	C3. Data must exit the PC running the simulator and be stored on a microcontroller using serial communication
-	C4. Shall display the speed data in an appropriate manner on a screen inside the car

### Analysis

### C1. 
An Arduino Uno is powered by the PC running the Simulink model.

### C2. C3. and C4.

The speedometer is placed right where the OEM spedometer use to be. The value on the LCD is received from the PC running a Simulink model and is stored on the Arduino. The value is sent using serial communication with a USB 2.0. The speed data is displayed appropriately due to it being displayed the same way as it was with the old speedometer display. The accuracy of the data being sent to the speedometer was checked by using a counter and sending individual numbers. This method of testing is sufficient due to the number displayed always being the number sent.



###### _Figure 1: The speedometer in the car when Simulink sends the value 15



###### _Figure 2: The speedometer in the car when Simulink sends the value 43

### Measures of Success
Initially, the signals from the car's speed sensors were to be spoofed, so the OEM speedometer display could still be used. The local MCU would recieve the speed from the PC to then be spoofed. Instead, a LCD was used to display the number acquired from the PC. A 3D printed mount for the LCD replaced the OEM speedometer display to keep the same immersive feel that was strived for initially. Since the accuracy and the immersive feel were still reached, the new design is a success.

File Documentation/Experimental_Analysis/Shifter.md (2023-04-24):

Gear Shifter Subsystem Analysis
--------------------------------------

### Specifications & Constraints
-	C1. Must use OEM gear shifter sensor
-	C2. OEM shifter sensor must send a detectable output signal for the shifter positions park, neutral, drive, and reverse.
-	C3. Shall receive the OEM gear shifter signal on a local microcontroller
-	C4. Must have local microcontroller that can be powered by a 12 V source
-	C5. Must have local microcontroller that can communicate with the master MCU via UART communication
-	C6. Must have local microcontroller that samples above or at twice the the measured normal frequency of 4.82 Hz from OEM gear shifter sensor to satisfy the Nyquist rate
-	C7. Must have local microcontroller capable of reading the measured 5 V digital output signal from the OEM shifter sensor
-	C8. Must have local microcontroller with at least 4 digital I/O pins to read the output signals coming from the OEM shifter signal
-	C9. Must have wires capable of handling 5 V to read the output signal from the OEM shifter sensor
-	C10. Must comply with IEEE 576-13 section on splicing wires and having loose wires.

## Analysis

### C1.
The output from the OEM shifter sensor is being captured so the sensor is being used.

### C2. C5. and C6.
The master MCU can sucessfully receive the shifter position signal being sent from the local MCU. This is done via UART communication. The local MCU is successfully detecting the shifter positions for positions Park, Neutral, Reverse, and Drive. Since the local MCU is successfully detecting the position changes, the Nyquist rate is satisfied. As you can see by Figure 1. below, N >> 1. This amount of testing is sufficeint enough due to the accuray of the output when compared to the input.



###### _Figure 1: The actual shifter position when compared to what the master MCU is displaying

### C3. 
The wires carrying the signal are wire spliced to a microcontroller.

### C4. 
The Arduino Uno is powered by a 12 V source.

### C7.
The signal being sent to the local MCU is a 5 V voltage signal and, the MCU is successfully detecting the 5 V to 0 V changes. The voltages were tested several times with a multimeter. As you can see by Figure 2. below, N >> 1. This amount of testing is sufficeint enough to prove that the signal sent to the MCU will always be around 5 V.



###### _Figure 2: The measured voltage being detected by the local MCU

### C8.
The Arduino Uno has 14 digital I/O pins.

### C9.
The wires being used for splicing are 22 gauge wires. 22 gauge wires can easily handle 5 V. 

### C10. 
There are no loose or exposed wires. All spliced wires have heat shrink and electrical tape.

### Measures of Success
In the conceptual design CAN bus and external sensors were intitally going to be used. Wire splicing instead was used to capture the position of the sensor. This alternative way of capturing the position yielded the same intended result. Each position of the shifter can be accurately captured by wire splicing with 100% accuracy. For overvoltage protection, intitially op-amp circuits were going to be used. A zener diode circuit was used instead. This also yielded the same desired result.

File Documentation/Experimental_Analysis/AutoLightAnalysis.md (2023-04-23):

# AutoLight Subsystem Experimental Analysis

### I. Specification & constraints
  1.  Must detect the auto light high beams, low beams, and left and right indicators with a voltage of no more than 5 volts and    a current below 40 milliamps.
   2. Must use OEM componets as the inputs
   3. The signal input from the autolight must not exceed 5 V 
   4. Implement a way to protect the signal from the input voltage varying from 10 V to 15 V
   5. Current to the signal must be less than 1 percent of the current to the light
   6. Prevent interference among signals through isolation methods

### II. Analysis

### SC1
| |High Beam | Low beam|Right indicator|Left indicaor|
|----|---|---|---|---|
|Test|Voltage|Voltage|Voltage|Voltage|
|1|4.20V|4.20 V|4.20V|4.00 V|
|2|4.20V|4.00 V|3.60V|3.60 V|
|3|4.00V|4.00 V|3.60V|3.60 V|
|4|4.20V|4.00 V|3.60V|3.60 V|
|5|4.00V|4.20 V|3.80V|3.80 V|
|6|4.00V|4.00 V|3.60V|3.60 V|
|7|4.00V|4.00 V|3.60V|3.60 V|
|8|4.20V|4.20 V|3.60V|3.80 V|
|9|4.00V|4.20 V|3.80V|3.80 V|
|10|4.00V|4.20 V|3.80V|3.80 V|

Figure 1: Each signal input are no more than 5 volt
 
 According to figure1, each signal input is not more than 5 volts. As the Arduino provides the power, it receives 5v. In the experiment, the oscilloscope helped to check each input, and each input produced a voltage below 5 volts, which the Arduino board could detect.

| |High Beam | Low beam|Left indicator|Right indicaor|
|----|---|---|---|---|
|Test|current|current|current|current|
|1|0.028 A| 0.027 A| 0.015 A| 0.015 A|
|2|0.028 A| 0.027 A| 0.015 A| 0.015 A|
|3|0.028 A| 0.027 A| 0.015 A| 0.015 A|
|4|0.028 A| 0.028 A| 0.015 A| 0.015 A| 
|5|0.028 A| 0.028 A| 0.015 A| 0.015 A|

Figure 2: each wire current from the headlight to optoisolator

   As shown in Figure 2, each wire has a current below 40 milliamps, which meets the requirement. The Multimeters help to measure the current flowing between the fuse cases for the experiment. Also, the data collected from the multimeter shows that the experiment was successful. All the results were within the expected range. The results show that the current will not harm the wire from the headlight to the optoisolator.

### S2
   
   

   Figure 3: wire splice form high beam,low beam and left indicator

   

   Figure 4: wire splice form right indicator

### S3
   As shown in figure 1, The input does not go over 5 V because the Arduino is providing power. 

### S4
   
   Figure 5 :Protection from the input voltage varying from 10 V to 15 V

   The resistor, fuse, and optoisolator prevent the signal from the input voltage varying from 10 V to 15 V. Also, if a current goes over the limit, the fuse will prevent it and protect the ciruit from frying.

### S5
   

   Figure 6: The current through the light

   - current to the light = 4.79 mA
   - 4.76 mA * 1% = 0.0476 mA
   - As shown in figure 2, the current from the wire is less than 0.0476 mA for the high beam, low beam, left indicator, and right indicator.

### S6
   opt
   Figure 7: The optoisolator is isolating the 12 V and 5 V

 The optoisolator prevents any interference from another signal. Also, it will allow 5 V to go through the optoisolator whenever the headlight turns on. Furthermore, it isolates the 12 V from the headlight and 5 v from the Arduino. Using this method prevents the Arduino from being damaged by 12 V signals. Furthermore, it allows the Arduino to detect the headlight when it is on. Finally, it creates a secure connection between the two circuits.

## III. Conclusion
Low Beam           |  High Beam
:-------------------------:|:-------------------------:
low beam|  highbeam

Left indicator       |  Right indicator 
:-------------------------:|:-------------------------:
leftInd |  right

The four pictures prove that the Arduino was able to detect the voltage. Furthermore, it indicates that there was no inference from another signal. The readings show that the system is working. The results obtained were consistent when the headlight is a different state. Therefore, the circuit is functioning as intended.

The experiment analysis was successful in the measure of success. For this reason, each location where voltage needs to be measured met the constraint. Furthermore, the subsystem produces an output that lets the user know that one of the states of the headlight is active. In addition, using the OEM by wiretap to detect the state met the constraint. The output of the headlight is stored in the microcontroller and displayed as high beam, low beam, left indicator, and right indicator in the terminal. Overall, each constraint and measure of success met the goal of the subsystem. Also, the experiment analysis shows that the subsystem working properly.

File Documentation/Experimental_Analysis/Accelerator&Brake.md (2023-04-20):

## Accelerator

### Specifications & Constraints
- A1. Must use OEM gas pedal to meet customer expectations.
- A2. Must send voltage at the range 0-5V that changes as the position changes to be read by the local microcontroller.
- A3. Must have wires able to handle at least 5V and 20mA due to the expected voltage range 0-5V and expected current of 20mA.
- A4. Shall have an accurate measure of the pedal postion of at least 1% accuracy to ensure the simulation is a accurate representation of real life. 
- A5. Must not have any exposed or loose wire according to IEEE Std 576-13.  

## Brake 

### Specifications & Constraints
- B1. Must use OEM brake pedal to meet customer expectations.
- B2. Must send voltage in the range of 0-5V that changes with pedal position to be read by a local microcontroller.
- B3. Must have wires able to handle 5V and 20mA to meet the expected voltage range of 0-5V and the expected current of 20mA. 
- B4. Shall have an accurate measure of the brake pedal position of at least 1% accuracy to ensure the simulation is an accurate representation of real life.
- B5. Must comply to IEEE 576-13 section on loose wires and splicing of wires.
- B6. Must have microcontroller with at least four analog or four digital in ports to read both the gas pedal sensors and the brake pedal sensors.
- B7. Must have microcontroller able to be powered by a 12V source to comply with the power systems design to stay at 12V.
- B8. Must have microcontroller with UART capability to communicate with the master MCU. 
- B9. Must have microcontroller able to convert analog to digital in at least 100ms to be consider real time. (Shown in master MCU signoff)

## Analysis

### A1. and B1.
These are meet by using the cars stock pedals.

### A2. and B2.
I tested the voltage range of the outputs for both the gas senor 1 and brake sensor 1 with an oscilloscope. I measured the signals at the analog pins of the master MCU with the oscilloscope 15 times for both systems and averaged the mean of the voltage. The averages of the voltages are as follows:

Gas sensor 1
Percent pressed | 0% | 50% | 100% 
---|---|---|---|
Voltage read | 815 mV | 1.72 V | 3.65 V |

Brake sensor 1 
Percent pressed | 0% | 50% | 100% 
---|---|---|---|
Voltage read | 1.41 V | 2.02 V | 2.92 V |

### A3. and B3. 
These are meet by the wires we selected which are 22 AWG wire which has the ratings of 300V and 7A.

### A4. and B4.
To verify this I took photos of the digital outputs read by the microcontroller with the pedals not pressed and fully pressed. 



This is the outputs for both pedals not pushed 



This is the outputs for the gas pedal fully pushed



This is the outputs for the brake pedal fully pushed

For gas 1, the number of bits measured are 871 - 174 = 697 therefore this sensor has the accuracy of 1/697 x 100% = 0.143%

For gas 2, the number of bits measured are 442 - 90 = 352 therefore this sensor has the accuracy of 1/352 x 100% = 0.284%

For Brake 1, the number of bits measured are 619 - 283 = 336 therefore this sensor has the accuracy of 1/336 x 100% = 0.298%

For Brake 2, this sensor does not output anything once the brake pedal was reinstalled to the car. I think it used to measure brake fluid pressure which would explan why the initial testing of it decreased when pressed fully and why it doesn't output signals now that the pedal was reinstalled.

### A5. and B5.
These constraints were meet because the wires that were spliced were covered with a heat shrink and then covered with electrical tape.

### B8.
These constraint no longer applies to this subsystem since there will be no local MCU to send data to the master MCU since the pedal sensors are going directly to the analog read pins on the master MCU for faster data reading and processing. 

### B6., B7., and B9.
These contraints are meet buy the use of the arduino mega as the MCU. The arduino mega has 16 analog input pins, is powered by 12V, and it is able to read analog pins at a rate of 100 mircoseconds. 

### Measure of Success
These are meet by gathering the output signals from the pedals which are the expected values of postion and interperting them in the form of percent pressed. We converted the digital signal to a percent of range of motion with the following code. 



This will result in the output signal of the pedal position being represented in percent form to be implemented into a simulator. 
This is the serial montor of the entire system is shown below which demonstrates that all signals are being measured and interpreted at the same time. 



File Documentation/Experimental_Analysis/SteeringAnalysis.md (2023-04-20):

Steering Experimental Analysis
----
### Specifications & Constraints
- Must measure angle of rotation of the steering wheel
- Must use the Nissan Leaf OEM steering wheel as the input
- Angle shall be no less than 960 degrees from the left boundary to the right boundary (2 and 2/3 rotations)
- Error of the angle must be within 1 degree of the true steering angle
- Must not lose steering position when power is cycled
- System must be small enough to fit in the area of the vehicle without interfering with the driver or other subsytems
### Analysis
#### SC1
The main function of the steering subsystem is to capture the angle of the steering wheel. Using an absolute rotary encoder, angle is a function of the resolution of the encoder and its current position.
    
    Angle = (Position / Resolution) * 360

where angle is in degrees, and resolution is 1024 for the 10-bit rotary encoder. This function is programed in the Master MCU using the following code:

    angle = (pos/1024)*360;
    
However, the programming alone does not provide the exact angle we are trying to measure. The gear system is in place to map the 360 degree rotation to the 1200 degree rotation of the steering wheel. This gear system was originally designed to be an 8:3 gear ratio based on the previously assumed 960 degrees of rotation of the steering wheel. Although, after some testing, the team discovered that the steering wheel has a 1200 degree of rotation, which must be accounted for with a 10:3 gear ratio. This experiment was done by rotating the steering wheel from the left boundary to the right boundary and checking the output of the Serial terminal. So at the time being, the angle is being measured but it is incorrect in all cases as the gear system must be changed. The new gear design should be ready to be installed in the next week or less.
#### SC2
The Nissan Leaf steering wheel is the input device of the steering subsystem. The rotary encoder measuring the changes in position of the steering wheel is mounted to the steering column of the vehicle so that turning the wheel will rotate the steering column and update the value on the Master MCU.
#### SC3 -> _Modified to "Angle shall be no less than 1200 degrees from the left boundary to the right boundary (3 and 1/3 rotations)"_
Currently, this constraint is also not being met due to the incorrect gear ratio mentioned previously. The testing was done by rotating the wheel from the far left boundary to the far right boundary, and stopping at each 90 degree interval between them. The output was then compared to the expected angle. During over 5 iterations of testing, when the wheel is moved from the far left boundary to the far right boundary, the steering angle rolls over back to 0 before the right boundary is met. Therefore, we are not able to measure the entire 1200 degrees of motion. Additionally, every single data point is incorrect due to the improper gear ratio.
#### SC4
The error in the steering angle is another constraint that is not met due to the incorrect gear ratio. That is, the error is much greater than 1 degree in all cases except when the angle is zero. Because our gear ratio accounts for a total rotation of 960 degrees and the steering wheel exhibits 1200 degrees of rotation, every angle measured is off by a factor of 3/4 (960/1200). This issue should be immeadiately resolved with the installation of the new gear system.
#### SC5
The absolute encoder was chosen to meet this requirement as one of its fundamental properties is that its position is known regardless of being powered. So, in every reboot of the power to the overall system, the steering angle is displayed at whatever its last position was. The experiment for this constraint was done by rotating the wheel to a random position, then turning the car off and then back on, and comparing the previous value from the current value.
##### Table 1
| |Output when Powered|Output when Power is Recycled|
|--|---|---|
|1|259.10|259.10|
|2|253.48|253.48|
|3|261.21|261.21|
|4|280.20|280.20|
|5|290.04|290.04|
|6|300.23|300.23|
|7|311.84|311.84|
|8|318.52|318.52|
|9|320.98|320.98|
|10|326.95|326.95|
#### SC6
The rotatry encoder, gear system, and mounts fit into the vehicle without interfering with the driver or other subsystems nearby. Therefore, this constraint has been properly met.
### Conclusion
The gear system being unproperly sized is causing all of the issues with this subsystem. Fortunately, this fix has already been addressed and the new gear system will be implemented within a week or less from the time of this submission. Once the new gear system is installed, the testing will begin again to comfirm that the subsytem has met all specifications and requirements. So, from an electrical standpoint, all parts of the subsystem are operating exaclty as desired. However, the mechanical portion of this subsystem is causing incorrect data to be fed into the system.

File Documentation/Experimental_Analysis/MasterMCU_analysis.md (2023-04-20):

Master MCU Experimental Analysis
------
### Specifications & Constraints
- Must connect to no less than four local microcontrollers
- Must provide real-time data transfer of under 100 milliseconds
- Shall connect to the PC running the simulation
- Shall have 4 Tx and 4 Rx pins for communication protocols
- Shall be powered by the PC

### Analysis
#### SC1 -> _Modified to "Must connect to no less than 1 local microcontroller"_
This constraint has been changed after the first prototype had been implemented. Originally, the Master MCU (Arduino Mega) was designed to connect to 4 different Arduino UNOs via UART for data transmission. However, due to some issues with the serial communication and lack of parts for the CAN Bus Capturing subsystem, the Master MCU must only communicate with one other Arduino UNO that is sends data from the gear shifter. The Arduino Mega is receiving serial data from the gear shifter Arduino UNO via UART successfully and therefore meets the new requirement of only connecting to one local MCU.
#### SC2
The Master MCU must transfer data in under 100 ms to the PC. To test this, the timestamps built into the Arduino IDE terminal were inspected between each data collection point.



_Figure 1: Master MCU Data Collection w/ Timestamps_

Figure 1 shows that the worst-case path in the system is the shifter info as it required _33 ms_ (195 ms - 162 ms going from Park to Neutral). This delay is under the 100 ms requirement. To ensure no outliers exist, the time between two shifter data acquistions was tested several more times:
###### Table 1 - Time between two shifter data acquisitions
| |Timestamp 1 (s)|Timestamp 2 (s)|Difference (ms)|
|--|---|---|---|
|1|5.195|5.228|33|
|2|5.228|5.228|0|
|3|5.228|5.260|32|
|4|5.260|5.293|33|
|5|5.293|5.293|0|
|6|5.293|5.325|32|
|7|5.325|5.325|0|
|8|5.325|5.359|34|
|9|5.359|5.359|0|
|10|5.359|5.391|32|

After running the test 10 more times, the worst-case delay between data captures was _34 ms_ which is well under the 100 ms specification.
#### SC3
The PC running the simulation is located in the basement of Brown Hall. The Nissan Leaf vehicle that the Master MCU pulls data from is located in Lewis Hall. Therefore, there is no way for the Master MCU to be connected to the PC running the simulation at this time. So at the time being, this constraint has not been met. Currently, the Master MCU connects to a Team Member's PC to view the data.
#### SC4 -> _Modified to "Shall have 1 Tx and 1 Rx pin for UART communication"_
Due to the same issues mentioned in section **SC1**, the Master MCU must only communicate with the Shifter Arduino UNO via UART, therefore only requiring a single Tx and Rx pin set. The Arduino Mega has 4 of each and therefore meets this specificaton successfully.
#### SC5
The Arduino Mega Master MCU connects to the PC via USB 2.0 cable which provides power. Therefore, this specification has been successfully met.
### Conclusion
Overall, the Master MCU subsystem only fails to meet constraint **SC3**, but is otherwise meeting the conditions of the other specifications and constraints. Given time and permission of the Mechanical Engineering Department, the Master MCU should be able to connect to the PC running the simulation with no issues. As for the measures of success, the real-time requirement is met but within a different time range than the original proposal. Initially, the goal was to be under 25 millisecond delay of data transfer. However, after some research, that time range was changed to 100 milliseconds or less, which is currently being met by the subsystem.

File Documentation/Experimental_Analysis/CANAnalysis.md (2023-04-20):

# CAN Capturing Subsystem Experimental Analysis
-------------------------------------
## I. Specifications & Constraints
1. Must capture information from CAN bus at no less than 10 Hz
2. Must store CAN bus data neatly and in a readable manner on the PC
3. Shall not interfere with the functionality with any other subsystem
4. Shall receive power from the PC
5. Must be able to store up to 2048 different CAN Messages
6. PC must have at least 28 Kb of storage space for CAN data

## II. Analysis
### SC1
CAN messages must be captured at no less than 10 Hz which is equivalent to 10 messages per second. In other words, every 100 ms, a CAN message must be sent to the PC.

      10 msg / 1 sec = 10 msg per sec ==> 1 msg per 0.1 sec ==> 1 msg per 100 msec
Therefore, for this subsytem to meet the first constraint, the time it takes between 2 messages being captured on the PC must be less than or equal 100 msec as seen in the recorded data table below.
###### Table 1
| |Time Stamp|CAN Message|Time Difference from previous|
|----|---|---|---|
|1|13:03:10.603|0x2DE000000000000FFFF|N/A|
|2|13:03:10.603|0x285FFFFFFFF000030B3|< 1 msec|
|3|13:03:10.627|0x60D0006000000000000|24 msec|
|4|13:03:10.627|0x1CC00000541|< 1 msec|
|5|13:03:10.627|0x285FFFFFFFF000031B4|< 1 msec|
|6|13:03:10.627|0x3550000000020006000|< 1 msec|
|7|13:03:10.627|0x30002|< 1 msec|
|8|13:03:10.660|0x2A00000000000C|33 msec|
|9|13:03:10.660|0x1CC00000572|< 1 msec|
|10|13:03:10.660|0x2457FF8011A33007FF3|< 1 msec|

As seen in Table 1 above, the time between each message is 33 msec or less in all cases, meeting the 10 Hz requirement. This experiment was performed by utilizing the timestamp function on the Arduino IDE and was performed 5 times total. Table 1 is an example data set of the output terminal that includes the time of the serial print function containing the updated CAN message.

### SC2
The CAN data is stored in an excel file, which is a well-known and highly professional software tool used to display and analyze data. Below is an example of the storage format in an excel sheet.



_Figure 1: CAN Bus Data Excel Formatting_

This storage method distinguishes the different messages being captured as well as parses the message ID from the rest of the message packet for extra readability.

### SC3
This subsystem is not connected to any other part of the vehicle and does not use any parts that are shared by any other subsystem exept the PC. This subsystem is connected to a single USB port of the PC and does not inhibit connectivity of the Master MCU to the same PC as this uses a different USB port. Therefore, this subsystem does not interfere with the functionality of any other subsystem.

### SC4
The CAN Bus Shield and Arduino that make up the subsystem are connected directly to the PC via USB which provides power.

### SC5
An excel sheet is capable of storing information in up to 65,536 rows, which greatly exceeds the 2048 maximum requirement for storage.

            2048 << 65536

### SC6
The PC has a 256 GB SSD and currently has 51.8 GB of free space which greatly exceeds the minimum requirement of 28 Kb of storage space.

            51.8 GB >> 28 Kb
            
## III. Conclusion
Because each of the 6 specifications and constraints listed above have been met, the subsystem is confirmed to function as designed. However, this system and its constriaints do not align with the original proposed measures of success. Orginally, the CAN Bus was supposed to be the main source of system information for auto-lights, steering angle, accelerator position, and brake position. This proposal has been reworked and is no longer relevant to the final product. The goal for the CAN Bus subsystem is strictly to capture data within 10 Hz and store it in a professional manner. Additionally, the original measures of success were to be under 25 milliseconds delay for all data transfer. After some research, the real-time requirement was changed to 100 milliseconds or less of delay. So, based on the new constraints, this subsystem is functioning to meet all measures of success and design specifications.

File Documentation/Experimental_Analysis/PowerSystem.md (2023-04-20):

Power System Experimental Analysis
------
### Specifications & Constraints
- 1. Must utilize the power supply provided for 12 V supply
- 2. Must regulate the supplied source voltage to be within 5% of 12 V
- 3. Must implement a method to disconnect the entire system from the source
- 4. Shall implement safety components to prevent overcurrent on new devices
- 5. Must not exceed wire capabilities
- 6. Must supply required input voltage to the external sensors, external controllers, and 12 V OEM components

### Experimental Analysis
#### SC1 
This specification is met with the power connection being on the provided power supply shown in Figure 1.



_Figure 1. The provided power supply installed inside the car._

#### SC2
This constraint for the detailed design is derived from a measure of success in the project proposal's requirement for input voltage. All measurements for this SC were recorded with a voltmeter. The source voltage measured from the output on the power supply is shown in Table 1. The experiment involved 10 samples at 1 second intervals. The average of all the trials was 12.296 V. The voltage needed to remain within 5% of the expected value, which was met as it remained within the range of 11.4 V and 12.6 V. 

Table 1.

Trial | V out (mean)
---|---|
1 | 12.27 V
2 | 12.34 V
3 | 12.40 V
4 | 12.23 V
5 | 12.25 V
6 | 12.23 V
7 | 12.36 V
8 | 12.31 V
9 | 12.28 V
10| 12.29 V

#### SC3
A switch was implemented in series with the positive output of the power supply to break the power connection for the entire system. The current rating is 50 A which is equal to the maximum output of the power supply. Figure 2 shows the met specification with the implemented switch.



_Figure 2. Switch installed inside the car._

#### SC4 & SC5
All OEM components are powered through the original protection system. Thus, the OEM wiring doesn't require analysis for the OEM safety components. The external component wiring is protected with 100 mA fuses. Figure 3 shows the implemented fuses that were installed. All wire used for the power system is 18 AWG with a current rating of 2.3 A. 

The power was cycled 15 times with leaving the power off for 15 seconds and on for 45 seconds. This allowed for the devices to dissipate all charge when off and then charge back to steady state in the 45 second period. Several actions were completed during the on period with random combinations of changeing the states of the pedals, steering, or auto lights to imitate normal use. No fuses were blown for the 15 trials with a maximum current seen being 80 mA. This meets the specification of protection the additional wiring. Table 2 shows the recorded information from the trials.

Table 2.

Trial | I (Arduino, mA) | I (Encoder, mA)
---|---|---|
1 | 76.230 | 76.125
2 | 75.560 | 78.820
3 | 74.756 | 77.235
4 | 76.853 | 77.625
5 | 78.258 | 79.235
6 | 77.831 | 74.564
7 | 76.463 | 78.264
8 | 79.465 | 77.365
9 | 76.731 | 79.102
10| 78.713 | 78.132
11| 78.201 | 77.216 
12| 76.216 | 76.120
13| 78.382 | 77.027
14| 79.021 | 78.089
15| 76.935 | 77.753



_Figure 3. 100 mA fuses for the external components._

#### SC6
The expected input voltages for all external components needed to not exceed 12 V. The two components being powered were the Arduino and Encoder. Both can accepted 10-12 V for the input. This was the target range for both components. 10 trials were conducted for the voltages at the input points. The voltages for all 20 values remained within the range and met the constriants for the devices.

Table 2.

Trial | V (Arduino, V) | V (Encoder, V)
---|---|---|
1 | 11.6 | 11.6
2 | 11.8 | 11.9
3 | 11.7 | 11.9
4 | 11.7 | 11.8
5 | 11.5 | 11.7
6 | 11.3 | 11.4
7 | 11.6 | 11.5
8 | 11.8 | 11.9
9 | 11.7 | 11.8
10| 11.8 | 11.7
### Conclusion

The specifications and constraints were all met per the experimental data. This verifies that the power system is to the designed requirements and does not require improvement to meet the mentioned criteria.

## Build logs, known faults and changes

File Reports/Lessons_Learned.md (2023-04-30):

# Lessons Learned
----------
### Michael Mollica
1. The overall project approach of tapping into existing sensors worked tremendously well. Additionally, the steering system using a rotary encoder was a fantastic approach to capturing steering angle. However, our initial choice of local MCUs for each subsystem did not go well. This was a failure and ended up being almost completely void by the end of the project. The subsystem breakdown and organization was a success regardless of the modifications made to the design choices.
2. The largest unanticipated problem was the UART communication with 4 MCUs. This was almost never working properly and should have never been the approach to the system design in the first place. The other slight problem was the shifter debouncing when switching from neutral to drive or reverse. This was discovered late in the process of experimentation but was able to be fixed with some software changes.
3. I would make the system dependent on a single MCU for each subsystem because of the issues with UART. This was the most avoidable issue, but also the biggest setback in our project.
4. Some best practices I have learned through this project is to heavily document and comment code, keep all old and new versions of code, keep track of all experimental results, and never assume something will work without testing it.
5. Do not expect everything to work how it was designed. There is so many extraneous errors and mistakes that can occur when physically connecting devices and when designing complex systems. Always have a backup plan and always test your devices extensively.
6. I have learned to program in Arduino much better than I had early in college. I have also learned a lot more about how serial communication works and its proper use.

### Brett Harden
1. The detail design and implementation went well for the group, but the technical proposals were a struggle. The project started off rough since most of us had issues with stating and understanding all components required in the project proposal and conceptual design. Both of these tasks were new learning experiences for everyone since it was different from prior class projects. Once the project progressed to the detail designs and implementation, the team settled in and was able to work well together to complete the tasks. This portion was similar processes to those of prior classes with final projects, and everyone was confident in their abilities. These two phases showed to be a night and day difference for the group's success.
2. There were several unanticipated issues within most subsystems. The issues that I was responsible for consisted of the steering gears and power installation. I had issues with getting the gears spaced properly since there was not an exact or direct distance that I could measure. In result, I had to go through several iterations of the gear design to find the correct fit. This also included changing the plane in which the gears were printed because there were issues with layers pulling apart.
3. I would have approached capstone 1 differently. I approached capstone 2 with a mentality of "attack the task before it attacks you" and it made it so much easier. I also would have moved quicker to install the components to ensure that the required wiring was included. This ended up wasting a lot of time that could have been prevented due to finding required ground wires that were needed with the power supply.
4. Best practices for me include being open to not having to know all details for all components. It makes life much easier when the work is shared and everyone is able to focus on their own work. Communication is key for this process, but it makes most work easier when you only have to focus on a small amount of a large project. 
5. I would advise to always attack the task at hand. You never want to be the person that everyone is waiting on, and this includes the team waiting for feedback. It is always better to have your stuff done quick to avoid tardiness.
6. The biggest skill that I learned for our project was AutoCAD. I was responsible for the 3-dimensional drawings for the entire project and had to learn AutoCAD Mechanical to complete them. I spent about 200 hours learning and designing all the components, and this accounts for most of the new skills that I learned. 

### Chase Colotta
1. The project went very well for this group. We had some trouble understanding the problem and finding an approach at the beginning of capstone. After some clarification we got on the right track and finished the design signoffs on time. The design were good even though we change some systems on implementation like the pedals going straight to the master MCU. We meet all deadlines well and finished what was asked of us for this project. 
2. A unexpected problem that occurred was that the master MCU was not reading the four UART communcations withouts problems occurring. One problem that happened to my subsystem is that one of my brake pedal sensors that work during testing outside of the car did not work once installed back into the vehicle. 
3. I would have liked to have it plugged into a simulator to see everything come together. 
4. The best practices I have learned is to be adaptable like when the local MCU's wasn't talking to the master. I also learned the importance of documenting the process.
5. Do not think everything will go smoothly. You are going to have to put in the work of designing it and be able to make things work if the designs don't work perfectly. Have a good understanding of the goal and accomplish it however you can. 
6. I gained the knowledge of completely designing something from the ground up and the documentation needed to record the steps. I have a much better understanding of how to read wiring schematics. 

### Gerardo Mateo
1.  Overall, as a group, we were able to accomplish the project. At the start of the semester, there were some challenges in understanding the project goal. Eventually, the group understood its goal by working hard and being patient. Furthermore, both technical and organization meet the requirement that the team wanted. However, during the planning of the subsystem, we were able to break down and find the right equipment for each subsystem. Although each sensor worked perfectly, the local MCU did not, so the team decided to reduce the number to one. On the other hand, each of the new modifications to the project helped to improve and complete our project.
2. The unanticipated problem that occurred in my subsystem was that it needed a pull-down resistor. Because of this, Arduinos were unable to determine the ground state. However, the major unanticipated problem was that simulation was not working since the group needed it to put data into the simulation. However, the group was aware that we were able to extract data from the sensor.
3. If I were to start over, I would do more research and finish the assignment early. In addition, a better understanding of how the sign-off work early would help reduce stress and time waste.
4.  Communication with teammates and asking for help when needed are the best practices I picked up. Furthermore, documenting information and commenting on your code makes it easier to understand what you're doing and where you're stopping. Also, giving good detail on what your subsystem does will help you in the future.
5. The word of wisdom I would give is to do your research early and have a backup plan for each subsystem or whole project. Also, save other information even if you don't need it because it could help you in the future. Also, the major wisdom is communicating with the team and helping each other if needed. However, alway expect the unexpect in each subsystem or project.
6. What I learn from the project is to communicate with the team and document information in good detail for others to understand what I'm doing. Also, I learned to plan on a wiring diagram and show the connection of the circuit that I'm creating. Overall, I learned how to plan early in the project and how to document each piece of information I gather.

### Ethan Powers
1. Overall, I think the project went well. Tapping into the OEM sensors of the car proved to be the most successful way to capture all of the inputs. The main failure for the project was the intention of using 3 local MCUs. The master MCU could only handle UART communication for one local MCU, so this proved to be a major problem. Steering and pedals were changed to send inputs to master MCU, so the problem was fixed. Having everything organized in github made the completion of the project much easier.
2. An unanticipated problem was the simulator not working. This led to the team to not be able to send inputs and receive outputs from it. This didn't play a huge portion in the success of the project, but it would have been exciting to see the car talking with the simulator. The other unanticipated problem was mentioned in the answer for question 1.
3. I would do more research before trying to complete the conceptual design. The conceptual design differed completley from the end product. This ended up in more work for sign offs. This made the sign off portion of the class a lot more stressful.
4. The best practices I picked up on were to make sure to document everything you change in the project and make sure that your subsystem works before permanently installing hardware. 
5. Do your research early and get ahead early. The more deadlines you make, the easier your life is.
6. I learned how to program with Arduino and experiment with wiring diagrams to confirm that they are true.

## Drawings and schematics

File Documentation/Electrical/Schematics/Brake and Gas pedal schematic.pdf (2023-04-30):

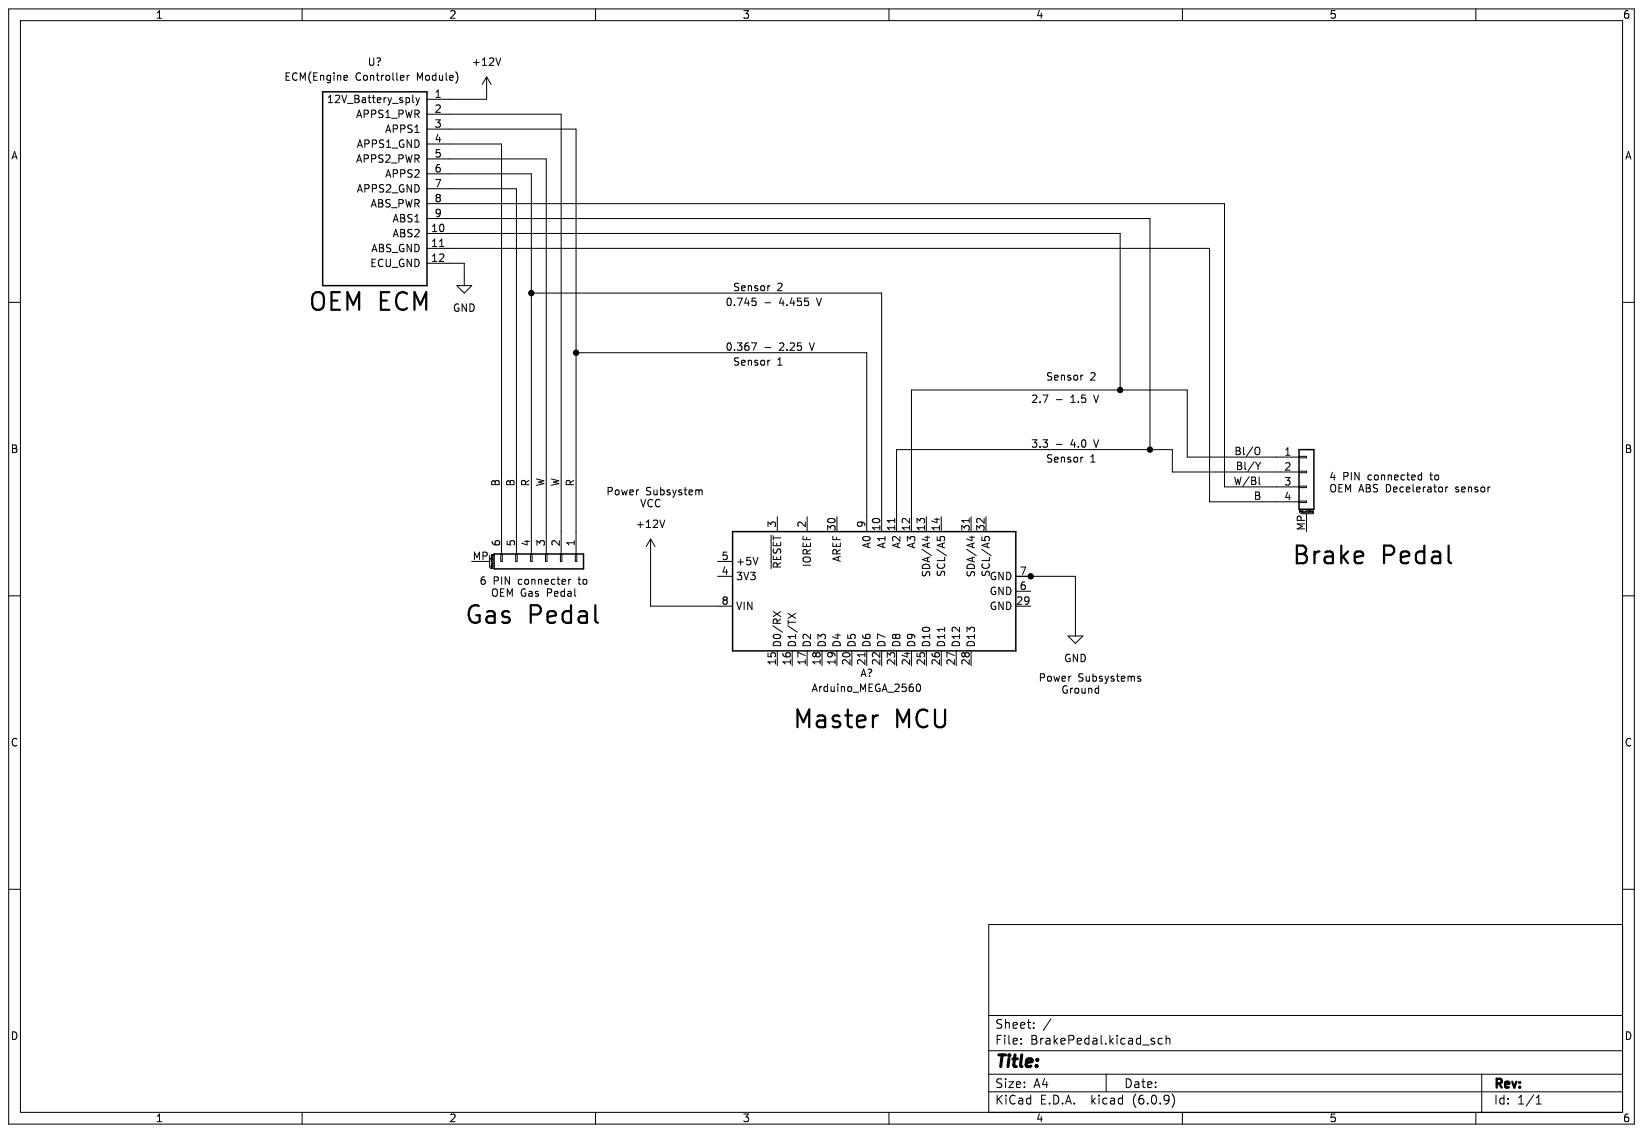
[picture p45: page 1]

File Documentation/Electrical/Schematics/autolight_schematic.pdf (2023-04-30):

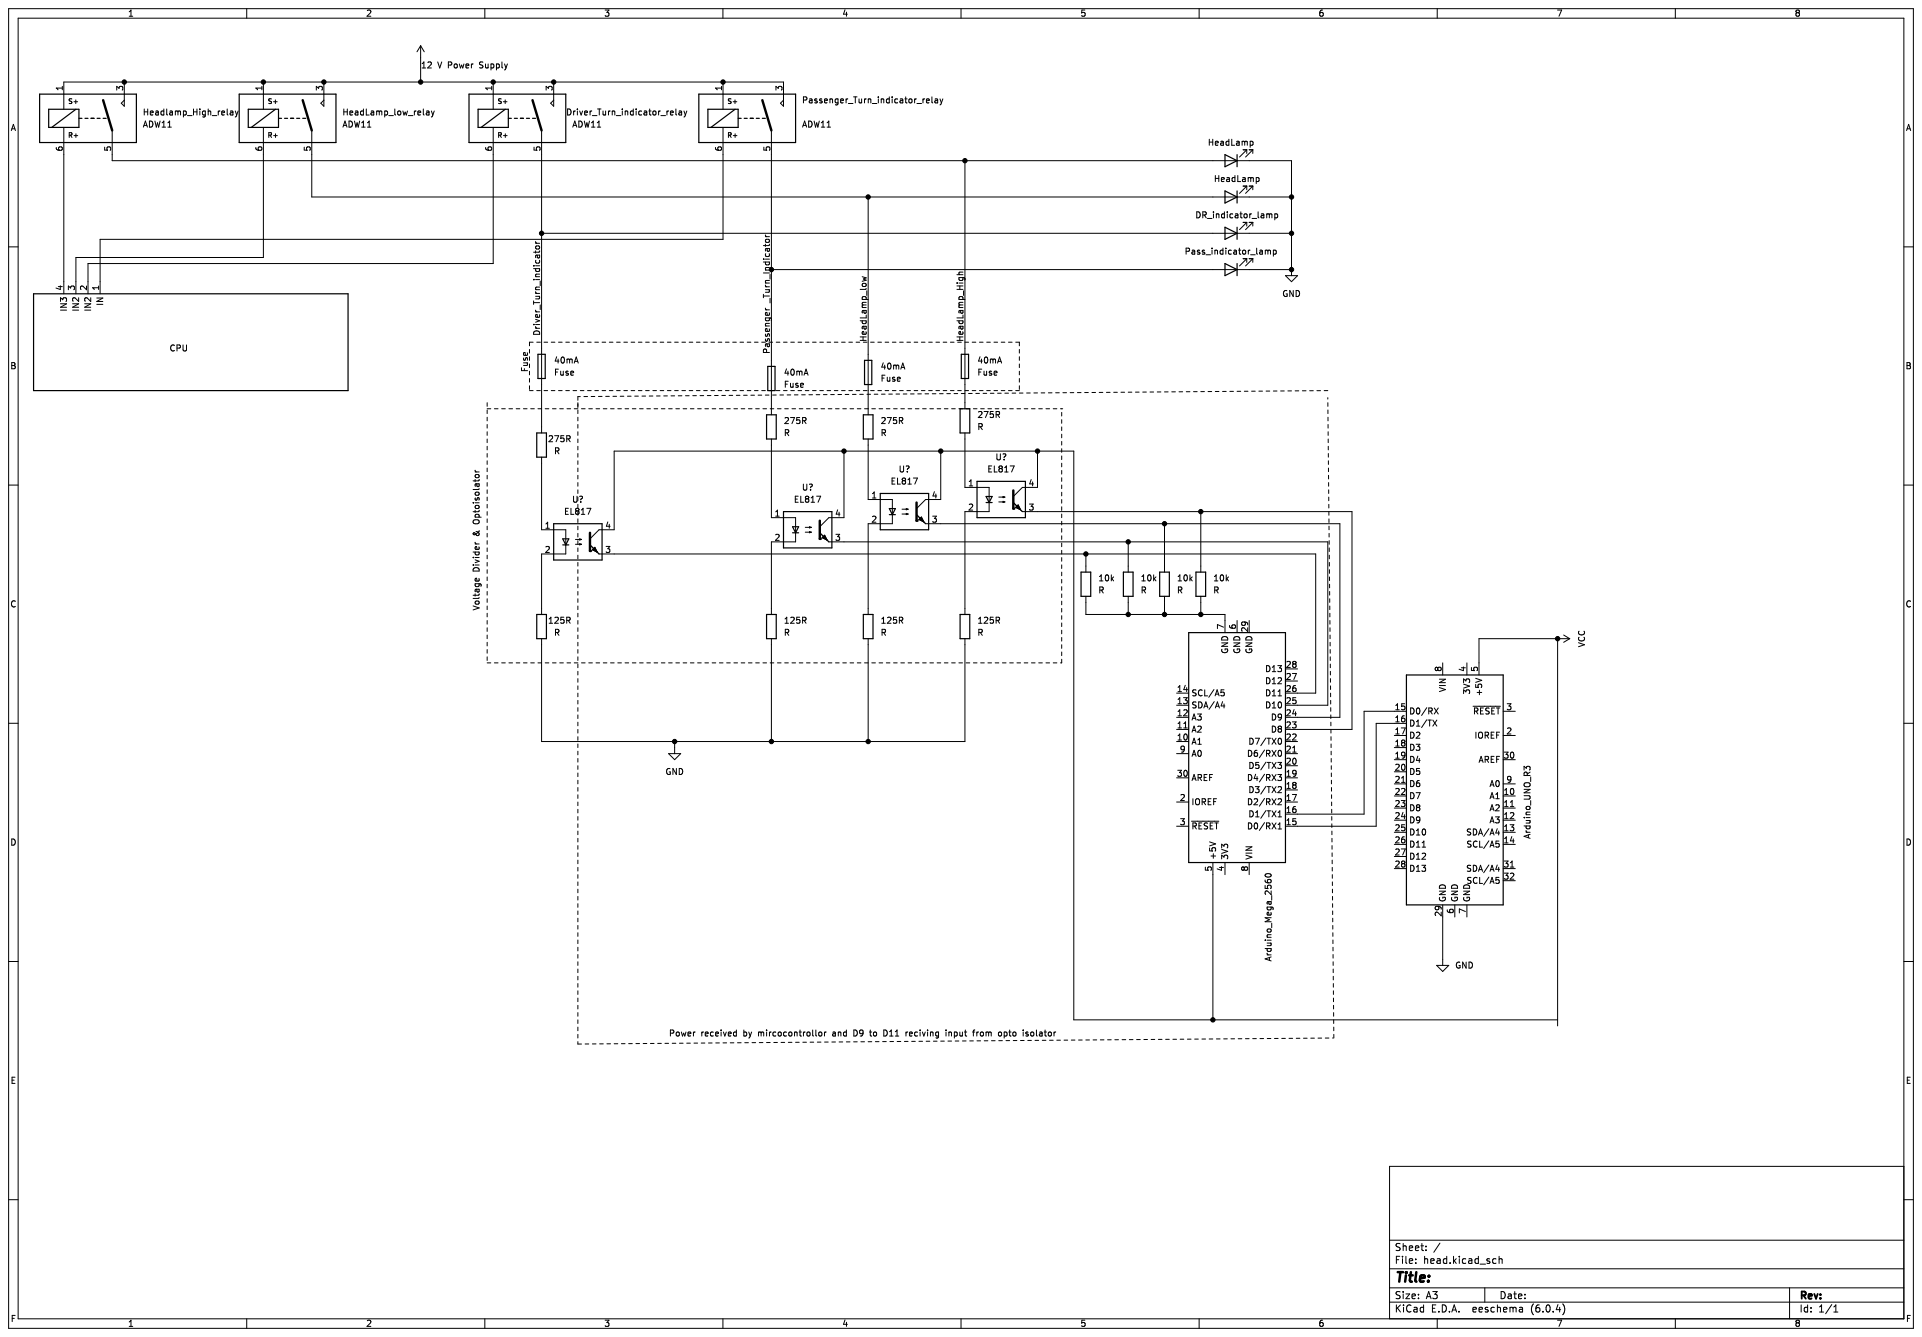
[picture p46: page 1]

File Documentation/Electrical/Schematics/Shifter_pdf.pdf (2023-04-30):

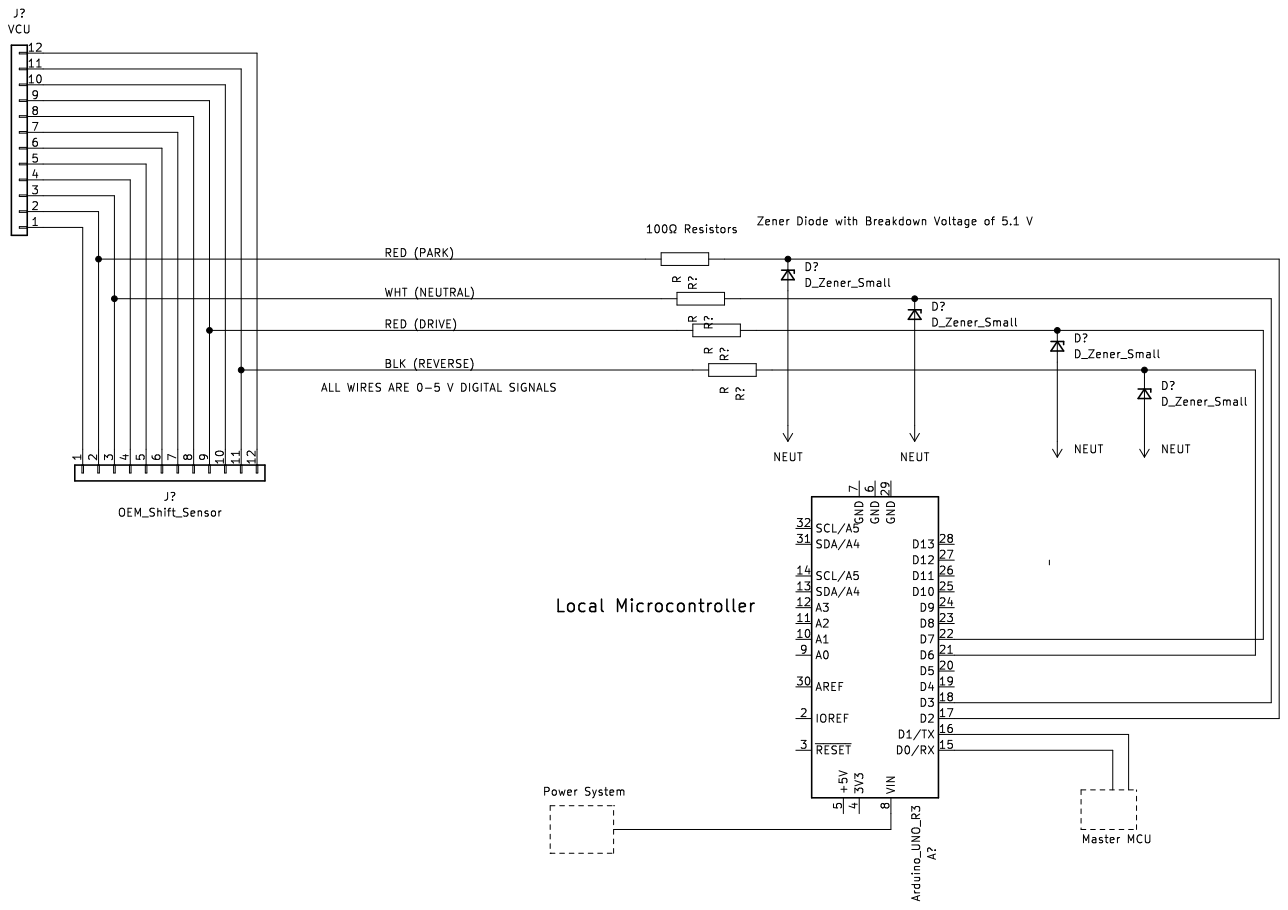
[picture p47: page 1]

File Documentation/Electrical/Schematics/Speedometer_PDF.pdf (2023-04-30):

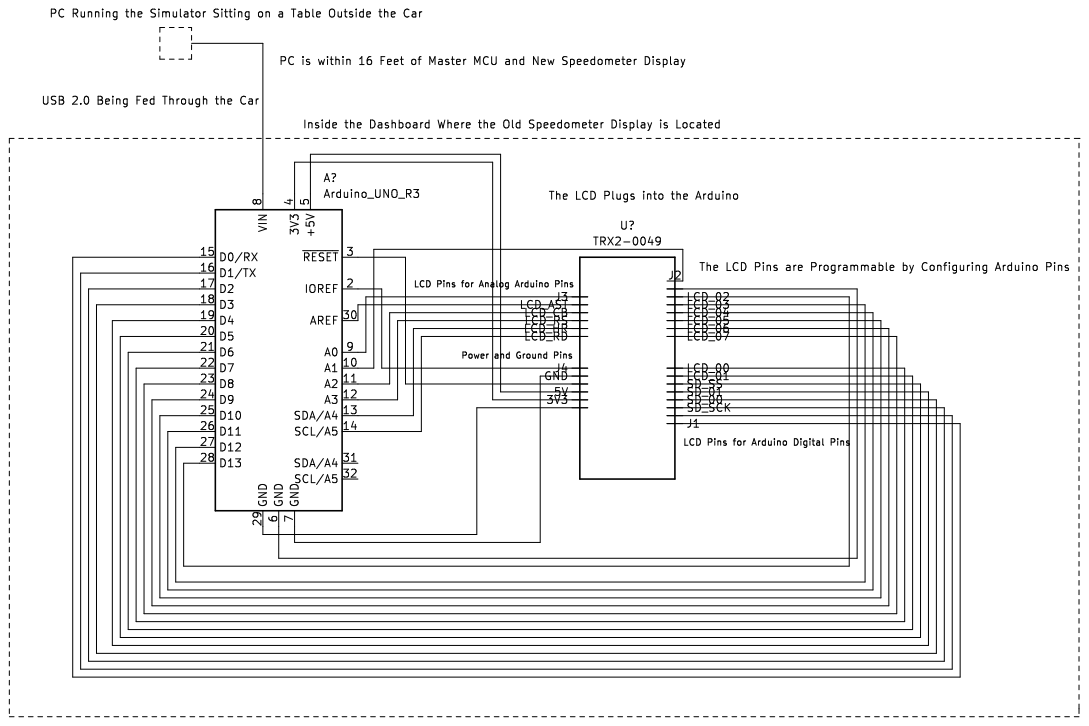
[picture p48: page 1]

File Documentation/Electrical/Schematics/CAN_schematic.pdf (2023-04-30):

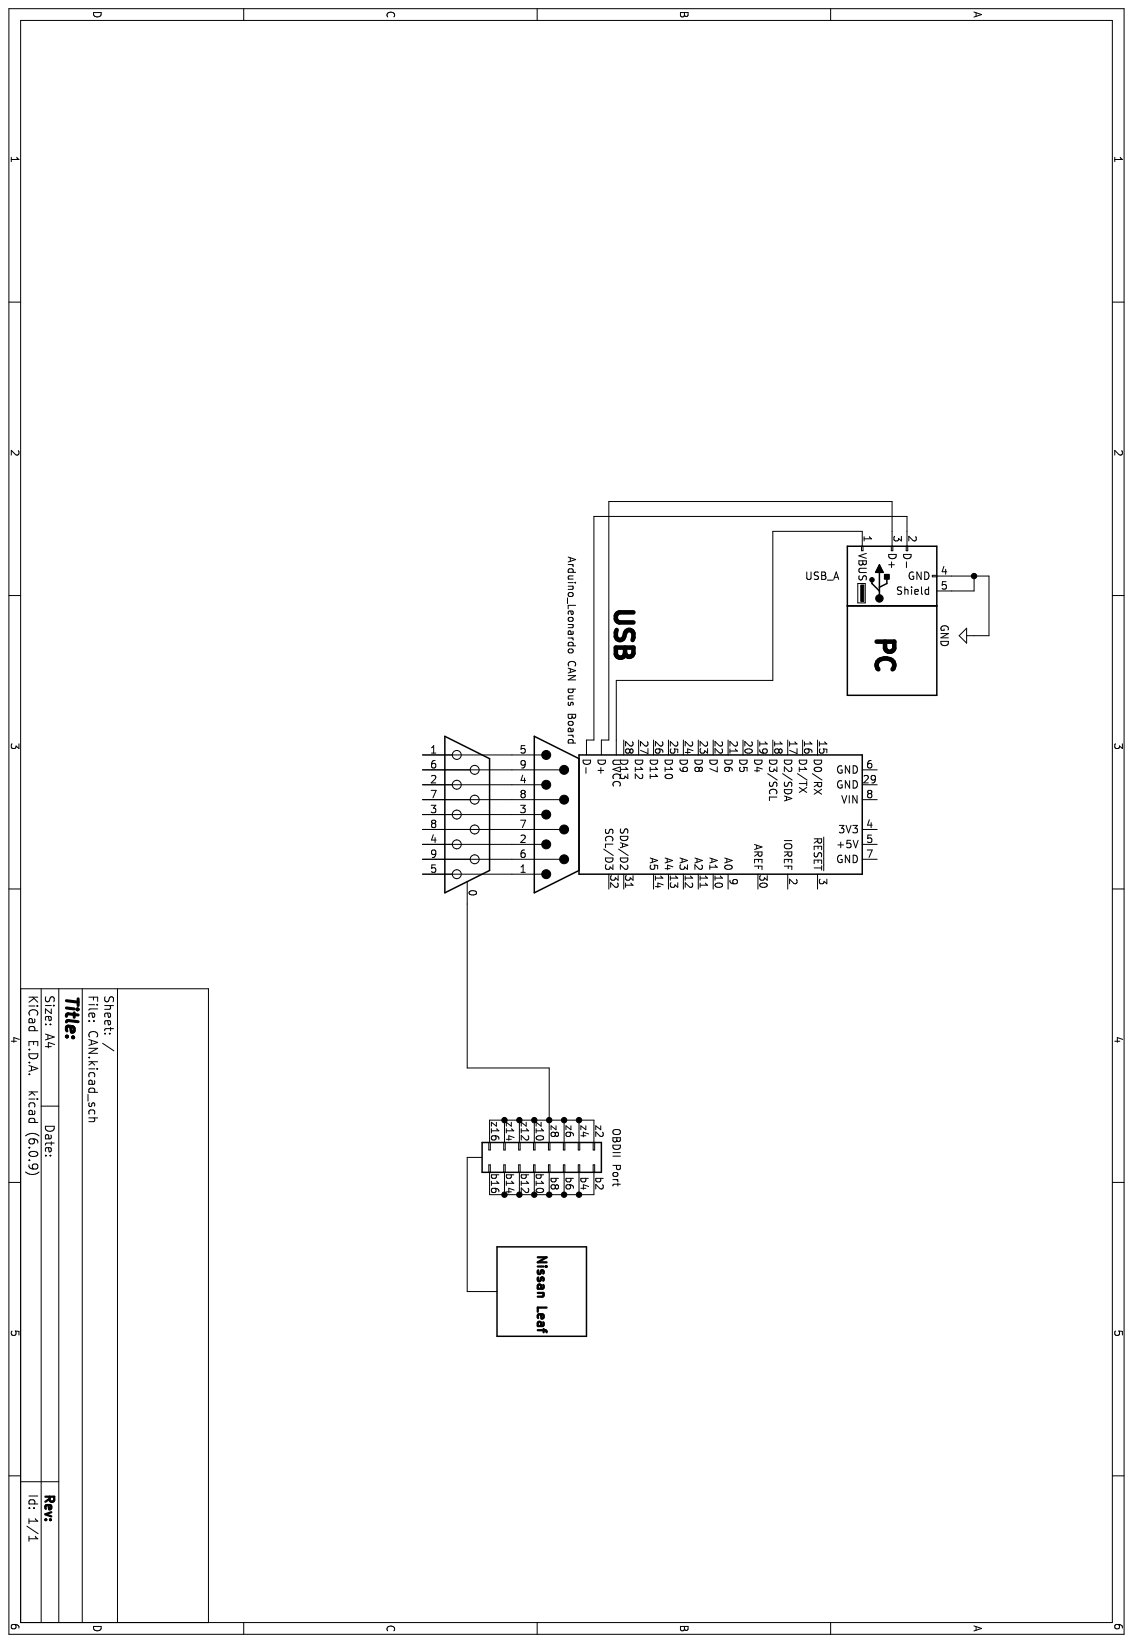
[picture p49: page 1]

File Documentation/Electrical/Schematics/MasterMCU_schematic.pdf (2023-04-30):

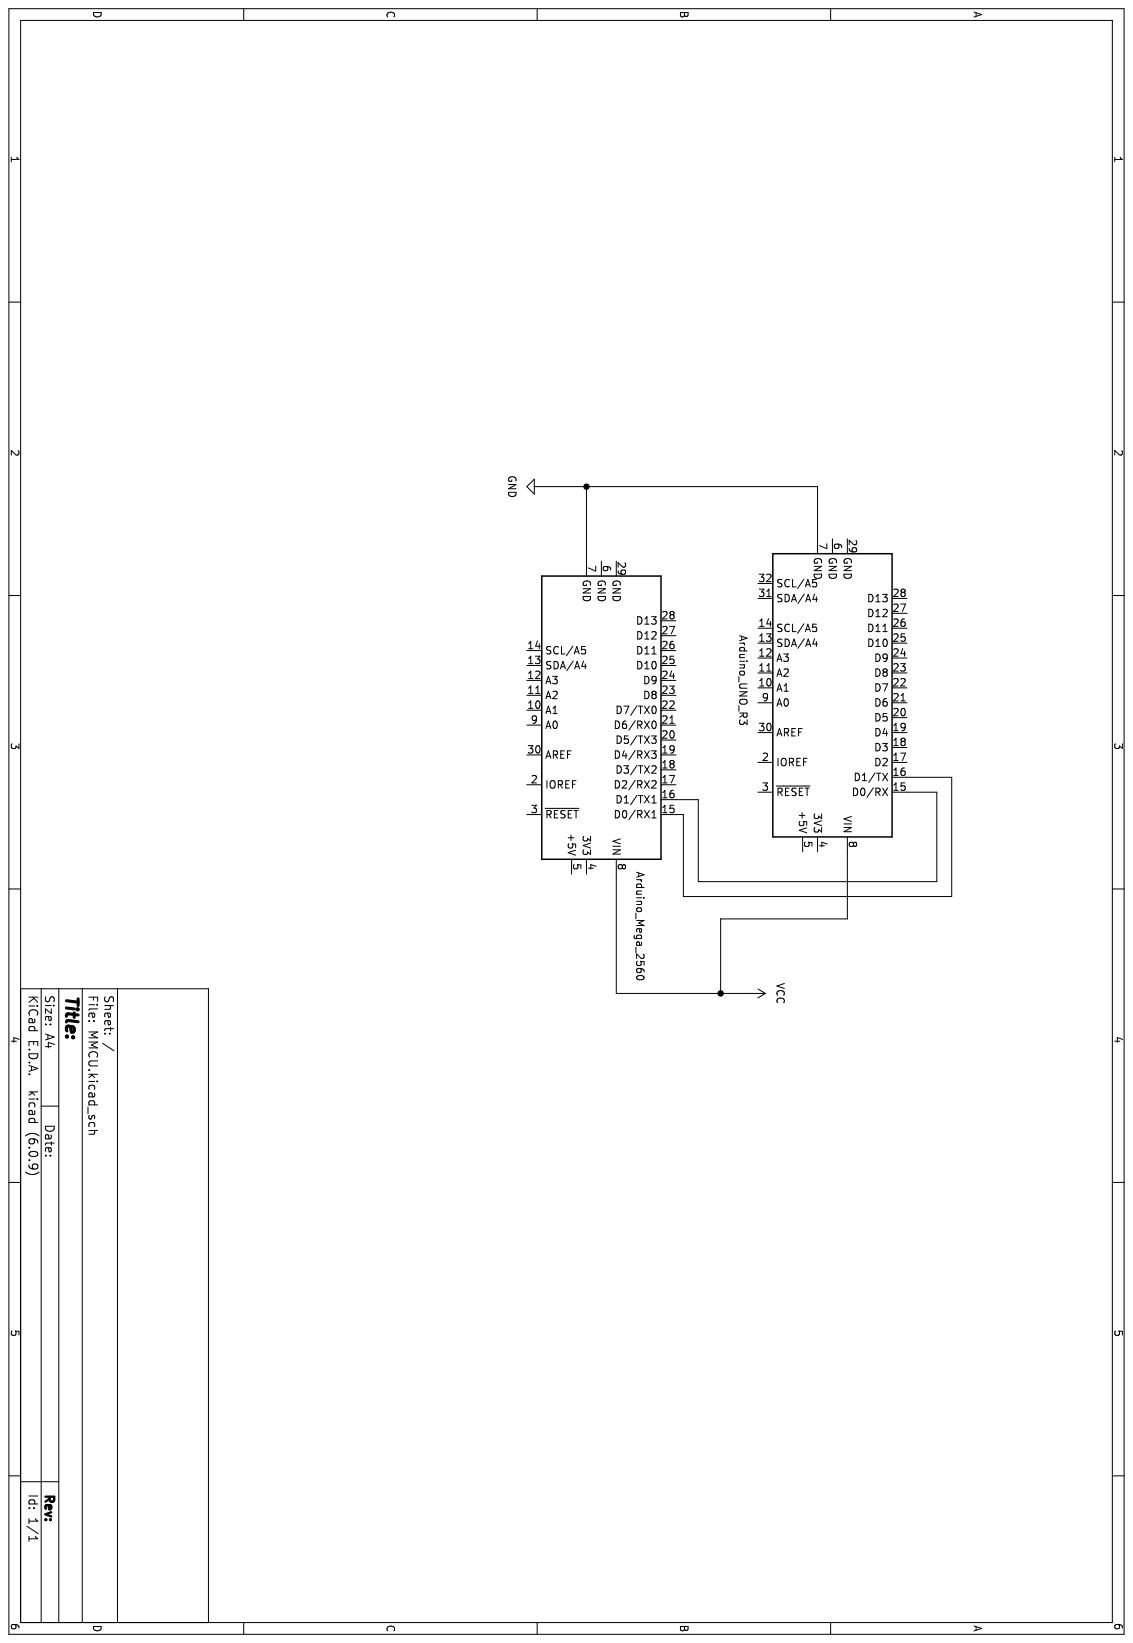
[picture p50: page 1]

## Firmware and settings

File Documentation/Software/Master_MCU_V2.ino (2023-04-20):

// Master MCU w/ UART Handling
// Capstone Team 8
// Captures UART data from shifter MCU and reads auto-light, steering, and pedal data via GPIO

int pin3 = 3;  
int pin4 = 4;  
int pin5 = 5;  
int pin6 = 6;

double Gas1;
double Gas2;
double Brake1;
double Brake2;

int steering_pins[] = {22, 23, 24, 25, 26, 27, 28, 29, 30, 31};
bool grey_code[10];
int binary = 0;
double pos, angle;

char shifter_data;
char last_pos = 'P'; // Default shifter position

void setup() {
  Serial.begin(115200);
  Serial1.begin(115200);

   // Set digital pins 3 through 6 as inputs for Headlights
  pinMode(pin3, INPUT);
  pinMode(pin4, INPUT);
  pinMode(pin5, INPUT);
  pinMode(pin6, INPUT);

  // Set Analog pins 0-3 as inputs for Gas & Brake
  pinMode(A0, INPUT);
  pinMode(A1, INPUT);
  pinMode(A2, INPUT);
  pinMode(A3, INPUT);

  // Set Digital pins 22-31 as inputs for Steering
  for (int i = 0; i < 10; i++)    // Set all pins to INPUT
  {
    pinMode(steering_pins[i], INPUT);
  }  
}

void loop() {  
    if (Serial1.available() > 0)
  {
    shifter_data = Serial1.read();

    if (shifter_data != 'X'){
        last_pos = shifter_data;
    }
        Serial.println();
        Serial.print("Shifter Info = ");
        Serial.print(last_pos);
        Serial.println();
  }
  
  // Steering Code
  steering();

  // Auto-Light Code
  autoLight();

  // Accelerator & Brake Code
  pedals();
}

void autoLight()
{
  // Combine digital pins 3 through 6 into a 4-bit value
  byte combinedValue = digitalRead(pin3) << 3 | digitalRead(pin4) << 2 | digitalRead(pin5) << 1 | digitalRead(pin6);

  // Print the combined value in binary format to the serial monitor
  Serial.print("\n");
  Serial.print(combinedValue, BIN);

  // Check if the combined value is equal to binary (autolight)
  if (combinedValue == B0000) {
    Serial.println(" all off!");
  }

  // Check if the combined value is equal to binary(low beam)
  if (combinedValue == B0001) {
    Serial.println(" Low beam detected!");
  }
   // Check if the combined value is equal to binary(high beam)
  if (combinedValue == B0010) {
    Serial.println(" High beam detected!");
  }

   // Check if the combined value is equal to binary(blinker)
  if (combinedValue == B0011) {
    Serial.println(" High and low beam detected!");
  }
   // Check if the combined value is equal to binary(right indicator )
  if (combinedValue == B0100) {
    Serial.println(" right indicator!");
  }
   // Check if the combined value is equal to binary(low beam and right indicator )
  if (combinedValue == B0101) {
    Serial.println(" low beam and right indicator detected!");
  }
   // Check if the combined value is equal to binary(high beam and right indicator)
  if (combinedValue == B0110) {
    Serial.println(" High beam and right indicator detected!");
  }
   // Check if the combined value is equal to binary(high beam/low beam on and right indicator)
  if (combinedValue == B0111) {
    Serial.println(" high beam/low beam and right indicator detected!");
  }
   // Check if the combined value is equal to binary(left indicator)
  if (combinedValue == B1000) {
    Serial.println(" left indicator detected!");
  }
   // Check if the combined value is equal to binary(left indicator and Low beam detected!)
  if (combinedValue == B1001) {
    Serial.println("left indicator and Low beam detected!");
  }
   // Check if the combined value is equal to binary(left indicator and high beam detected)
  if (combinedValue == B1010) {
    Serial.println(" left indicator and high beam detected!");
  } // Check if the combined value is equal to binary(high beam/low beam on and left indicator detected)
  if (combinedValue == B1011) {
    Serial.println(" high beam/low beam and left indicator detected!");
  }
   // Check if the combined value is equal to binary(hazard light)
  if (combinedValue == B1100) {
    Serial.println(" hazard light!");
  }
   // Check if the combined value is equal to binary(hazard light and low beam!)
  if (combinedValue == B1101) {
    Serial.println(" hazard light and low beam!");
  }
   // Check if the combined value is equal to binary( hazard light and high beamlow beam)
  if (combinedValue == B1110) {
    Serial.println("  hazard light and high beam!");
  }
   // Check if the combined value is equal to binary(all)
  if (combinedValue == B1111) {
    Serial.println(" all on!");
  }

  // Wait for a short time before repeating the loop
  //delay(100);
}

void pedals()
{
  // Calculate the percent of the compression based on the max & min values measured.
  Gas1 = analogRead(A0);
  Gas1 = (Gas1 - 168) / 799;

  Gas2 = analogRead(A1);
  Gas2 = (Gas2 - 84) / 411;

  // Print Average of Gas1 & Gas2 for redudancy.
  Serial.print("Accelerator: ");
  Serial.println((Gas1 + Gas2)/2);

  Brake1 = analogRead(A2);
  Brake1 = (Brake1 - 285) / 432;
  Serial.print("Brake: ");
  Serial.println(Brake1);

  // Redundant and not necessary
  Brake2 = analogRead(A3);
}

void steering()
{
  pos = grey_to_binary();     // Capture Binary output
  // Due to systematic and instrumental error in the steering of the Nissan Leaf
  // The angle was calculated by fine tuning and testing the left and right limits.
  // The team found that the vehicle wheel rotates slighty more to the right bound than
  // the left bound, so the distance from the center is not exactly symmetrical.
  angle = ((pos/1024) * 1292) - 639; // Convert Binary to angle based on 1200 degrees of rotation
  Serial.println();
  Serial.print("Steering Angle: ");
  Serial.print(angle);
}

int grey_to_binary()
{
  // Read Active Low Grey Code
  for (int i = 0; i < 10; i++)
  {
    grey_code[i] = !digitalRead(steering_pins[i]);
  }

  // Convert Grey to Binary
  binary = grey_code[9];  // MSB is the same
  
  for (int j = 8; j >= 0; j--)
  {
    binary = (binary << 1) | (grey_code[j] ^ (binary & 0x1));   
  }

  return binary;
}

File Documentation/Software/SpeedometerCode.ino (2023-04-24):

#include "Adafruit_GFX.h"
#include "MCUFRIEND_kbv.h"
#include "SPI.h" 
#include <SoftwareSerial.h>

// define color
#define BLACK 0x0000
#define NAVY 0x0004
#define DARKGREEN 0x03E0
#define DARKCYAN 0x03EF
#define MAROON 0x7800
#define PURPLE 0x780F
#define OLIVE 0x7BE0
#define LIGHTGREY 0xC618
#define DARKGREY 0x7BEF
#define BLUE 0x001F
#define GREEN 0x07E0
#define CYAN 0x07FF
#define RED 0xF800
#define MAGENTA 0xF81F
#define YELLOW 0xFFE0
#define WHITE 0xFFFF
#define ORANGE 0xFD20
#define GREENYELLOW 0xAFE5
#define PINK 0xF81F
#define RX 10
#define TX 11

int character_location;
unsigned int speed = 0;
unsigned int curSpeed;
int store = 0;
int CS=A3;
int RS=A2;
int WR=A1;
int RD=A0;
int RST=A4;
MCUFRIEND_kbv tft(A3, A2, A1, A0, A4);
//Variables


const int buffer_size=16; //buffer size and buffer used to recieve the
byte buf[buffer_size]; //data from Simulink

float output;
float output_current;

#define RX 10
#define TX 11



SoftwareSerial esp8mod(RX,TX);


void setup() {
  uint16_t ID = tft.readID(); 
  tft.begin(ID); 
  tft.setRotation(1);
  tft.fillScreen(NAVY);
  tft.fillRect(170, 120, 220, 90, NAVY);
  tft.setTextColor(WHITE);
  Serial.begin(9600);
  esp8mod.begin(115200);
}

void loop() {
      
    if (Serial.available() > 0 ){
      speed = Serial.read();
          
    }
    
      tft.setCursor(122, 120);
      tft.setTextSize(14);
      tft.print(speed);
      delay(500);
      tft.fillRect(122, 120, 250 , 100, NAVY);
          
    
}

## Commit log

2022-11-22 Add files via upload
    *I attempted to export all of the .dwg files to .stl using AutoCAD and they would not convert after several attempts.
    [Adapter Plate.dwg, Car Mount Arm.dwg, Final Steering Mount.dwg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]
2023-04-12 Add files via upload
    Final Version of the Master MCU code that prints directional steering angle on a 1200-degree scale and converts the accelerator and brake compression to percentage.
